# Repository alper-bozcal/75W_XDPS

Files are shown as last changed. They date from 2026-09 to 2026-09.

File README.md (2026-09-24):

# DBC2-Battery-Charger

  Main repository for the DEIF Battery Charger - 2 products.

## Dosyalama Sistemi

`Develop` branchinde kodun çalışma garantisi yoktur fakat en son kod bulunabilir. `Main` branch' de versiyon atlatıldığında stabil kod bulunabilir.

Yazılım `Firmware` klasöründe tutulmaktadır. `Common/` tüm ürünler için ortak fonksiyonları içermektedir. Bunun yanında yer alan klasörler ise proje ismine göre ayrılmıştır.

`ENKO` ve `Documents` klasörleri geliştirme sırasında oluşturulan dökümanları tutmaktadır. Bunları bazıları müşteri ile paylaşılmıştır.

`Hardware/` donanım şema ve PCB dosyalarını içermektedir.

`Simulations` ve `Tests` klasörleri donanım için gerekli çalışmalarda oluşturulan dosyaları içermektedir. Test sonuçları `Tests/` içerisinde bulunabilir.

## Algoritma

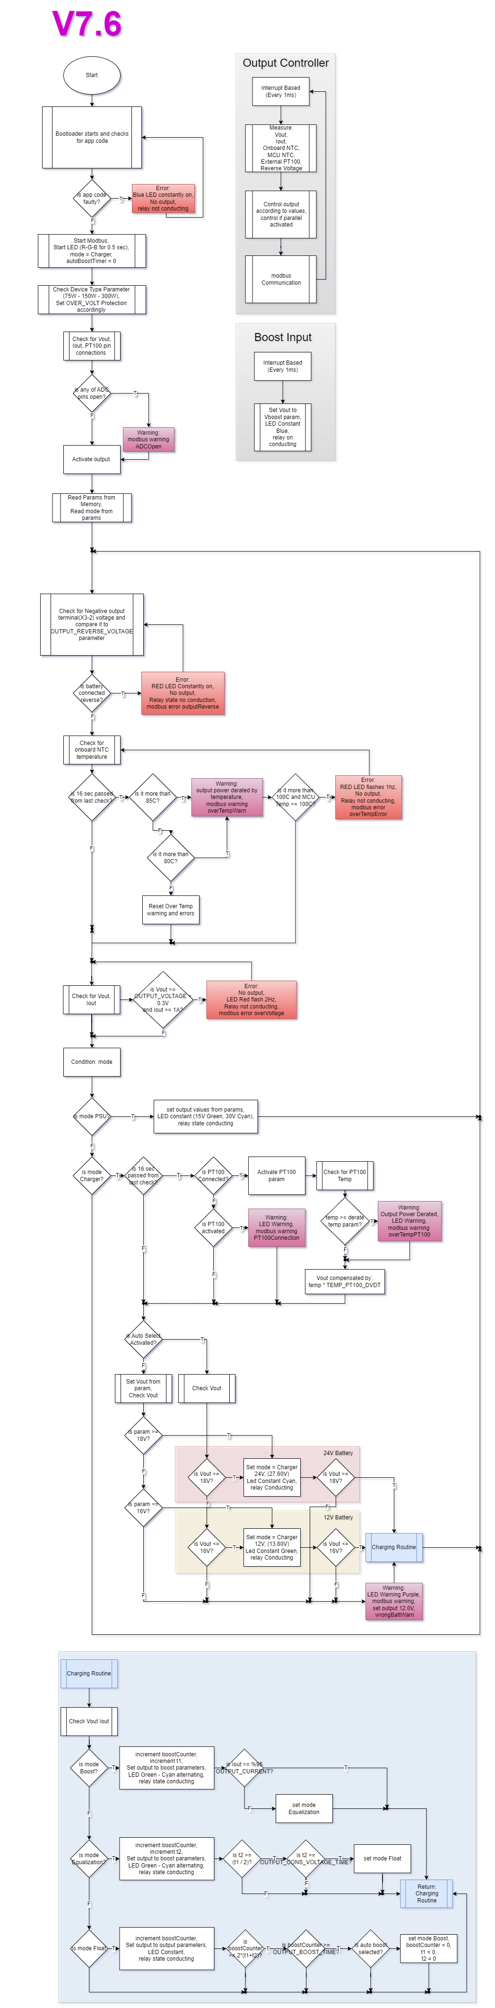
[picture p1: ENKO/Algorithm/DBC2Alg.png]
DBC2 Algorithm:


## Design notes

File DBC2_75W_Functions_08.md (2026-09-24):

# DBC2 75W Functions

|  |  |  | min-max | Unit | Default |
| --- | --- | --- | --- | --- | --- |
| Power  Supply | V_ps_set | Power Supply output voltage | 10.0-15.0 | VDC | 12 |
| Power  Supply | I_ps_limit | Power Supply current limit | 5.0 | ADC | 5 |
| Charge | I_bulk_max | Maximum current during Bulk (I) stage | 0.5-5.0 | ADC | 12 |
| Charge | V_abs | Absorption (U) voltage | 12.0-15.0 | VDC | 13.8 |
| Charge | T_bulk_max | Maximum duration for Bulk stage | 0-24 | Hour | 6 |
| Charge | T_abs | Absorption duration | 0-240 | min. | 120 |
| Charge | I_tail_threshold | Current threshold for transition from Absorption to Float | 0.1-0.2 | ADC | 1 |
| Charge | V_float | Float voltage | 11.0-14.5 | VDC | 13 |
| Charge | Ifloat_to_abs | Current threshold to switch from Float to Absorption (must be > I_tail_threshold) | 0.1-5.0 | ADC | 1.5 |
| Boost | Boost_En | Boost mode enable | 0-1 | - | 1 |
| Boost | Boost_Source | Boost source selection | Auto-Man-Both | - | Both |
| Boost | Boost Edge Selection | External Boost input rising/falling edge selection | Rising / Falling | - | Falling |
| Boost | V_boost | Boost voltage | 12.0-15.0 | VDC | 14.8 |
| Boost | I_boost_max | Maximum Boost current | 0.5-5.0 | ADC | 3 |
| Boost | T_boost_dur | Boost duration | 1-120 | min. | 60 |
| Boost | T_boost_per | Boost period | 1-99 | hour | 1440 |
| Pt100 | Pt100_Act | Pt100 temperature sensor active/passive | 0-1 | - | 0 |
| Pt100 | Pt100 dV/dT | Temperature compensation coefficient | -40 to +40 | mv/ºC | 0 |
| Pt100 | Pt100_temp_comp_minC | Minimum temperature for compensation | -10 to 10 | ºC | 0 |
| Pt100 | Pt100_temp_comp_maxC | Maximum temperature for compensation | 35 to 50 | ºC | 50 |
| Pt100 | Pt100_low_warning_temp | Battery low temperature warning level | -10 to 10 | ºC | 5 |
| Pt100 | Pt100_low_alarm_temp | Battery low temperature alarm level | -10 to 10 | ºC | 0 |
| Pt100 | Pt100_high_warning_temp | Battery high temperature warning level | 25 to 60 | ºC | 35 |
| Pt100 | Pt100_high_alarm_temp | Battery high temperature alarm level | 25 to 60 | ºC | 40 |
| Pt100 | Pt100_high_trip_temp | Battery high temperature trip level (output cut-off) | 25 to 60 | ºC | 45 |
| Cable Compensation | CableVoltage droop Compensation | Compensation coefficient for voltage drop across cable | 0 to 100 | mv/A | 0 |
| Paralel Working | Paralel_Working | Parallel working enable/disable | 0-1 | - | 0 |
| Paralel Working | Voltage Droop | Voltage droop for load sharing in parallel operation | 0 to -100 | mV/A | 0 |

| Calibration (ENKO Leevel) | Iout_offset |  |  |  |  |
| --- | --- | --- | --- | --- | --- |
| Calibration (ENKO Leevel) | Iout_gain |  |  |  |  |
| Calibration (ENKO Leevel) | Vout_offset |  |  |  |  |
| Calibration (ENKO Leevel) | Vout_gain |  |  |  |  |
| Calibration (ENKO Leevel) | Vbat_offset |  |  |  |  |
| Calibration (ENKO Leevel) | Vbat_gain |  |  |  |  |
| Calibration (ENKO Leevel) | Pt100_offset |  |  |  |  |
| Calibration (ENKO Leevel) | Pt100_gain |  |  |  |  |
| Calibration (ENKO Leevel) | NTC_offset |  |  |  |  |
| Calibration (ENKO Leevel) | NTC_gain |  |  |  |  |
| Calibration (ENKO Leevel) | Cupper Lines Voltage Droop Compensation |  |  |  |  |

## Detailed Parameter Descriptions

Parameters

Detailed Parameter Descriptions Based on DBC2 75W Functions

V_ps_set

Sets the output voltage of the device when operating in Power Supply mode. Adjustable between 10.0 V and 15.0 V to power external electronic circuits.

I_ps_limit

Defines the maximum current limit in Power Supply mode. If the load exceeds this value, the output current is clamped to this limit to prevent overload.

I_bulk_max

Maximum current supplied during the Bulk (I) charging stage. The device maintains constant current until the battery voltage reaches the absorption setpoint or the bulk time limit expires.

V_abs

Voltage setpoint for the Absorption (U) stage. The device maintains this voltage while the current gradually decreases as the battery approaches full charge.

T_bulk_max

Maximum duration for the Bulk stage. If the battery does not reach the absorption voltage within this time, the device transitions to the next stage.

T_abs

Duration of the Absorption stage. The device maintains the absorption voltage for this period unless the current drops below the tail threshold earlier.

I_tail_threshold

Current threshold used to determine the transition from Absorption to Float stage. When the charging current falls below this value, the device switches to Float mode.

V_float

Voltage level maintained during the Float stage to keep the battery fully charged without overcharging. Provides a trickle charge to compensate for self-discharge.

Ifloat_to_abs

Current threshold to trigger a transition from Float back to Absorption mode. Must be higher than the tail threshold to ensure proper recharge behavior.

Boost_En

Enables or disables the Boost charging mode. Boost mode applies a higher voltage to equalize battery cells and accelerate charging.

Boost_Source

Selects the source that initiates Boost mode. Can be time-based automatic activation, external input trigger, or both.

Boost Edge Selection

Defines the edge type (rising or falling) for external Boost input signal triggering. Determines how the Boost mode is activated externally.

V_boost

Voltage applied during Boost mode. This higher voltage helps equalize battery cells and ensure uniform charge levels.

I_boost_max

Maximum current allowed during Boost mode. Protects the system from excessive current during high-voltage charging.

T_boost_dur

Duration of the Boost mode operation. After this time, the device returns to Float voltage level.

T_boost_per

Periodicity of Boost mode activation. Defines how often Boost mode is triggered automatically.

Pt100_Act

Activates or deactivates the external Pt100 temperature sensor. Used for temperature-based voltage compensation.

Pt100 dV/dT

Temperature compensation coefficient in mV/°C. Determines how output voltage adjusts based on battery temperature.

Pt100_temp_comp_minC

Minimum temperature at which compensation is applied. Below this value, voltage compensation is not performed.

Pt100_temp_comp_maxC

Maximum temperature at which compensation is applied. Above this value, voltage compensation is not performed.

Pt100_low_warning_temp

Battery low temperature warning threshold. Triggers a warning when battery temperature drops below this level.

Pt100_low_alarm_temp

Battery low temperature alarm threshold. Triggers an alarm and may affect output behavior.

Pt100_high_warning_temp

Battery high temperature warning threshold. Triggers a warning when battery temperature exceeds this level.

Pt100_high_alarm_temp

Battery high temperature alarm threshold. Triggers an alarm and may affect output behavior.

Pt100_high_trip_temp

Battery high temperature trip threshold. If exceeded, output is cut off to protect the system.

CableVoltage droop Compensation

Compensation coefficient for voltage drop across output cables. Helps maintain accurate voltage at the battery terminals.

Paralel_Working

Enables or disables parallel operation mode. Allows multiple devices to share load current.

Voltage Droop

Voltage droop setting used in parallel operation for load sharing. Adjusts output voltage based on load to balance current among devices.

Boost (Equalization) 
Boost mode utilizes a higher charging voltage to rapidly recharge batteries and ensure that all cells within a battery string are equalized to the same charge level.

Boost mode can be initiated either automatically based on predefined timing parameters or manually by connecting the Boost terminal to the negative terminal of the battery. When the Boost function is activated externally, the automatic Boost timer is reset.

The external Boost input operates with edge triggering and can be configured to respond to either a rising or falling edge. Upon receiving an external Boost signal, the device output is elevated to the Boost voltage for the specified duration, after which it returns to the Float voltage level. Following this phase, the device automatically decides whether to switch to Float or Absorption mode based on the load conditions.

Remote Temperature Compensation Functionality (dV/dT) / Alarm

The charger supports remote temperature compensation based on the battery temperature when an optional external sensor is placed near the batteries and connected to the remote temperature sensor terminal block on the main circuit board. This feature is especially critical in applications where the charger and batteries are located in different ambient environments.

A Pt-100 sensor can be used as the external temperature sensor. If the temperature reading from the external sensor falls below -45°C or rises above +180°C, and remains outside these limits for a defined duration, a sensor fault is triggered. In this case, the alarm output is activated, and the output voltage is set to 12V.

The temperature compensation function is only active in Charger Mode. It is disabled in Power Supply Mode.

The temperature compensation value is expressed in mV/°C and can be either positive or negative:

A positive value increases the output voltage as temperature rises.

A negative value decreases the output voltage as temperature rises.

On the Power Cloud main screen, the Set Output value (for both current and voltage) reflects the user-defined setpoint. However, if temperature compensation is active, the effective output value shown will be adjusted accordingly.
For example, if the user sets the output voltage to 13.8V, and the external sensor reads 45°C with a compensation value of -10mV/°C, the adjustment will be:

Thus, the effective output voltage displayed will be 13.6V.

To protect against excessively high or low output voltages, the compensation effect is clamped at 0°C and +50°C. Beyond these temperatures, the output voltage is held constant at the values corresponding to these limits.

In a future update, the output voltage variation based on ambient temperature and set parameters will also be graphically displayed on the screen.

The temperature compensation value can be configured within the range of -40mV/°C to +40mV/°C.

If the external temperature sensor reading exceeds the Temperature Sensor Alarm Threshold, the output voltage is disabled, the LED turns red, and the alarm output is activated.

Internal Temperature Sensor / Alarm

The charger includes two internal temperature protection mechanisms and a power derating function, both utilizing onboard temperature sensors:

Sensor-1: Located on the secondary side, this sensor is also monitored by the MCU. It is used to implement power derating functions and to prevent device failure due to overheating.

Sensor-2: An NTC-type sensor also located on the secondary side, but not monitored by the MCU. It is directly connected to the primary SMPS IC and serves as a fail-safe. If Sensor-1 becomes non-functional or disconnected, Sensor-2 will shut down the output to protect the system. Once the temperature returns within safe limits, the output is automatically re-enabled.

Since only Sensor-1 is evaluated by the software, the following functions apply specifically to it:

The Sensor-1 temperature value can be monitored on the Power Cloud display and is also available in the log screen for recording.

If the Sensor-1 temperature is below 60°C, no action is taken.

Starting from 60°C, the output power is gradually limited.

At 70°C, the output power is reduced to 25% of the rated value.

If the temperature exceeds 70°C, the output is shut down, the red LED is turned on, and the alarm relay is activated.

Leds

Charger Mode:

Bulk : Flsahing Green ( 100msec ON, 100msec OFF)

Absorption: Flashing Green ( 400msec ON, 400msec OFF)

Float mode: Steady GREEN

Boost mode: Flashing BLUE (50msec ON, 500msec OFF)

Power Supply

Çıkış gerilimi set edilen değerde: Steady GREEN

Failure: Flashing RED

Over temperature (1 times 100msec ON, 500msec OFF)

Lower temperature (2 times 100msec ON, 500msec OFF)

Output Over Voltage (3 times 100msec ON, 500msec OFF)

Output Low Voltage (4 times 100msec ON, 500msec OFF)

Reverse Battery Connection (5 times 100msec ON, 500msec OFF)

Power Derate (6 times 100msec ON, 500msec OFF)

Battery Disconnected (only charger mode) (7 times 100msec ON, 500msec OFF)

High Ouput Current (only power supply mode) (8 times 100msec ON, 500msec OFF)

USB Communication:

Boot Mode (Firmware Update):  Steady Blue

Alarm Relay and Fault Monitoring Functions

The charger includes a SPST N/O (Single Pole Single Throw Normally Open) contact relay, which is energized during normal operation. This means the contact remains closed under normal conditions.

AC/DC Failure Condition

The alarm relay is de-energized (contact opens) under the following conditions:

Loss of AC input power

Loss of DC output from the charger

⚠️ Note: This alarm condition cannot be indicated via LED.

User-Configurable Alarm Functions

The following alarm functions can be enabled or disabled via the user interface. Each alarm can be configured as either:

Warning: Only the alarm relay is activated.

Trip: The alarm relay is activated and the output is shut down.

All alarm functions support a configurable delay time, with a default of 3 seconds. The delay can be set between 0 and 60 seconds.

Alarm Conditions

Low DC Output Voltage
Relay de-energized if:
VDC<88%×VSTATEV_{DC} < 88\% \times V_{STATE}VDC<88%×VSTATE
Alarm resets if:
VDC>92%×VSTATEV_{DC} > 92\% \times V_{STATE}VDC>92%×VSTATE

High DC Output Voltage
Relay de-energized if: VDC>107%×VSTATEVDC

Alarm resets if: VDC<102%×VSTATEVDC 

Overvoltage Protection
Relay de-energized if:
VDC>15.1 VDCV  (This is a fixed internal threshold.)

Battery Disconnect
Relay de-energized if the battery is disconnected.

Alarm delay: 10 to 20 minutes

This function is only active in Charger Mode

High Battery Temperature
Software-configurable threshold.
Relay de-energized if the high temperature limit is exceeded.

Low Battery Temperature
Software-configurable threshold.
Relay de-energized if the low temperature limit is exceeded.

Reverse Polarity Protection
(Relay de-energized if reverse battery connection is detected.)

Connection of Deeply Discharged Battery
(Relay de-energized if a battery with excessively low voltage is connected.)

Ters Bağlantı Koruması

Düşük gerilime Sahip Akü Bağlantısı

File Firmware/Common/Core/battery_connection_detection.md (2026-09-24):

# Battery Connection Detection Algorithm

## Overview

The battery connection detection algorithm is designed to determine whether a battery is actually connected to the charger output terminals. This is critical for proper charger operation, as the charging algorithm behaves differently when a battery is present versus when the output is open or connected to a purely resistive load.

## Purpose

- **Prevent false charging cycles**: Avoid running charging cycles when no battery is present
- **Improve safety**: Detect disconnection events that could indicate wiring issues
- **Optimize operation**: Allow the charger to enter appropriate operating modes based on battery presence

## Algorithm Overview

The detection algorithm operates on the principle that a battery behaves differently from a resistive load when voltage is applied:

1. **Resistive Load**: When voltage increases, current increases proportionally (Ohm's law: I = V/R)
2. **Battery Load**: A battery acts as a voltage source with low internal resistance, so applying voltage causes a disproportionate current increase

## Implementation Files

- **Header File**: `Controller.h` - Contains type definitions, constants, and function prototypes
- **Implementation File**: `Controller.c` - Contains the detection algorithm implementation
- **Documentation**: `battery_connection_detection.md` - This file

## Configuration Parameters

All configuration parameters are defined in `Controller.h` using `#define` directives:

| Parameter | Value | Unit | Description |
|---|---|---|---|
| `BAT_CONN_MIN_CURRENT_TRESHOLD` | 15 | 10mA | Minimum current threshold for detection (150mA) |
| `BAT_CONN_CHECK_DURATION_MS` | 30 | ms | Duration to monitor voltage after applying test voltage |
| `BAT_CONN_VOLTAGE_CONDITION_MV` | 10 | 10mV | Voltage condition threshold (100mV) |
| `BAT_CONN_VOLTAGE_THRESHOLD_MV` | 30 | 10mV | Voltage threshold above test voltage target (300mV) |
| `BAT_CONN_TEST_VOLTAGE_MV` | 1180 | mV | Test voltage to apply during detection (11.8V) |
| `BAT_CONN_CURRENT_THRESHOLD_PERCENT` | 95 | % | Percentage of effective current - detection only runs when below this |
| `BAT_CONN_CHECK_INTERVAL_MS` | 30000 | ms | Interval between detection checks (5 minutes with 10ms timer) |
| `BAT_CONN_MAX_FAILED_CHECKS` | 10 | count | Maximum consecutive failed checks before reporting battery disconnected |
| `BAT_CONN_CHECK_WINDOW_MS` | 360000 | ms | Time window for counting failed checks (1 hour with 10ms timer) |
| `BAT_CONN_RATIO_TOLERANCE_PERCENT` | 20 | % | Tolerance for comparing voltage and current change ratios |

## Algorithm Phases

### Phase 1: Preconditions Check

The detection algorithm only runs when specific conditions are met:

```
Condition: Measured Current < (Effective Current × 95%)
```

**Rationale**: Detection is only performed when current draw is low, ensuring the test voltage application won't cause issues.

### Phase 2: Baseline Measurement

```
1. Store current voltage (Vout_initial)
2. Store current current (Iout_initial)
```

These baseline values are used to calculate change ratios after applying the test voltage.

### Phase 3: Apply Test Voltage

```
1. Set charger output to 11.8V (BAT_CONN_TEST_VOLTAGE_MV)
2. Start 30ms monitoring timer (BAT_CONN_CHECK_DURATION_MS)
```

### Phase 4: Monitor Response

```
Wait for 30ms while measuring:
- Output voltage
- Output current
```

### Phase 5: Evaluation

After the monitoring period, the algorithm evaluates the results using two tests:

#### Test 1: Voltage Reached Target

```
IF Vout_measured < (BAT_CONN_TEST_VOLTAGE_MV + BAT_CONN_VOLTAGE_THRESHOLD_MV):
    RESULT = BATTERY NOT CONNECTED
```

**Rationale**: If the output voltage fails to reach approximately 11.8V within 30ms, it indicates there's no voltage source (battery) at the output.

#### Test 2: Change Ratio Comparison

If voltage reached the target, calculate and compare change ratios:

```
voltage_change = Vout_measured - Vout_initial
current_change = Iout_measured - Iout_initial

voltage_ratio = (voltage_change × 100) / Vout_initial
current_ratio = (current_change × 100) / Iout_initial

ratio_difference = |current_ratio - voltage_ratio|
```

**Decision Logic**:

```
IF ratio_difference <= BAT_CONN_RATIO_TOLERANCE_PERCENT:
    RESULT = BATTERY NOT CONNECTED (Resistive load)
ELSE IF current_ratio > (voltage_ratio + BAT_CONN_RATIO_TOLERANCE_PERCENT):
    RESULT = BATTERY CONNECTED
ELSE:
    RESULT = INDETERMINATE
```

**Rationale**:
- **Resistive Load**: Voltage and current change proportionally (similar ratios)
- **Battery Load**: Current increases more than voltage (battery acts as current sink)

## State Machine

The algorithm implements a state machine with the following states:

### BAT_CONN_IDLE
- **Description**: Waiting for next check interval
- **Entry**: After initialization or after completing a detection cycle
- **Exit**: When interval timer completes AND preconditions are met
- **Next State**: `BAT_CONN_STORE_VALUES`

### BAT_CONN_STORE_VALUES
- **Description**: Storing baseline voltage and current measurements
- **Actions**: 
  - Store `measured->Vout` → `ctx->storedVoltage`
  - Store `measured->Iout` → `ctx->storedCurrent`
- **Next State**: `BAT_CONN_APPLY_VOLTAGE`

### BAT_CONN_APPLY_VOLTAGE
- **Description**: Applying test voltage to output
- **Actions**:
  - Set `controller.referenceVoltage = BAT_CONN_TEST_VOLTAGE_MV`
  - Start monitoring timer
- **Next State**: `BAT_CONN_MONITORING`

### BAT_CONN_MONITORING
- **Description**: Monitoring voltage and current response
- **Duration**: 30ms (BAT_CONN_CHECK_DURATION_MS)
- **Exit**: When monitoring timer completes
- **Actions**: Store measured voltage and current
- **Next State**: `BAT_CONN_EVALUATE`

### BAT_CONN_EVALUATE
- **Description**: Evaluating results and updating status
- **Actions**:
  - Call `_evaluateBatteryConnection()`
  - Update failed check counter if battery not detected
  - Reset counter if battery detected
  - Update `batteryNotConnected` flag if threshold exceeded
- **Next State**: `BAT_CONN_IDLE`

## Failed Check Tracking

The algorithm tracks consecutive "battery not connected" detections:

### Counter Management

```
IF result == NOT_CONNECTED:
    failedCheckCount++
    IF failedCheckCount == 1:
        Record firstFailTimestamp
    
    IF (currentTime - firstFailTimestamp) > 1 hour:
        Reset failedCheckCount = 1
        Update firstFailTimestamp = currentTime
    
    IF failedCheckCount >= 10:
        Set batteryNotConnected flag = 1

ELSE IF result == CONNECTED:
    Reset failedCheckCount = 0
    Reset firstFailTimestamp = 0
    Clear batteryNotConnected flag = 0
```

### Rationale

- **10 consecutive failures within 1 hour**: Ensures the battery is consistently not detected before reporting
- **1-hour window**: Prevents old failures from affecting current status
- **Reset on success**: A single successful detection clears all previous failures

## Integration Guide

### ✅ Already Integrated in DBC2 Firmware

The battery connection detection has been **fully integrated** into the DBC2 firmware in `Interfaces.c`. The integration includes:

#### 1. Global Variables Declaration (Interfaces.c)
```c
protection_t protectionBatteryDisconnect;
batConnDetection_t batteryConnectionDetection = {0};
int16_t batteryConnectionStatus = 0; // 0 = connected, 1 = disconnected
```

#### 2. Protection Initialization (_initSystem function)
```c
// CRITICAL BUG - NEEDS FIXING:
initProtection(&protectionBatteryDisconnect, &batteryConnectionStatus, 0, 1000, MODE_OVER);
// Should be:
// initProtection(&protectionBatteryDisconnect, &batteryConnectionStatus, 1, 1000, MODE_OVER);

// Initialize Battery Connection Detection
initBatteryConnectionDetection(&batteryConnectionDetection);
enableBatteryConnectionDetection(&batteryConnectionDetection, 1);
```

#### 3. Periodic Update (Callback1ms function)
```c
// Update battery connection detection every 10ms
updateBatteryConnectionDetection(&batteryConnectionDetection, &measuredValues);
// Update battery connection status for protection system
batteryConnectionStatus = isBatteryDisconnected(&batteryConnectionDetection);
updateProtection(&protectionBatteryDisconnect);
```

#### 4. Error Flag Handling (_checkProtections function)
```c
// Check for battery disconnect protection
if(protectionBatteryDisconnect.triggered){
    //RED LED Flashes 7Hz
    controller.flagERR = controller.flagERR | 0x80; // 8th Error bit is BatteryDisconnect
}else{
    controller.flagERR = controller.flagERR & ~(0x80);
}
```

### How to Check Battery Status

#### Option 1: Check Protection Status
```c
if(protectionBatteryDisconnect.triggered){
    // Battery disconnection protection is active
    // Relay is in RELAY_ERROR state
}
```

#### Option 2: Direct Function Call
```c
if(isBatteryDisconnected(&batteryConnectionDetection)){
    // Battery is not connected (but protection may not be triggered yet)
}
```

#### Option 3: Check Error Flag
```c
if(controller.flagERR & 0x80){
    // Battery disconnect error flag is set (Bit 7)
}
```

#### Option 4: Via Modbus
Read the `flagERR` register via Modbus and check bit 7 (0x80).

### Protection Behavior

When `protectionBatteryDisconnect.triggered` becomes active:
1. **Error Flag**: `controller.flagERR` bit 7 (0x80) is set
2. **Relay State**: Relay goes to `RELAY_ERROR` state (output disabled)
3. **LED Indication**: Red LED blinks at 7Hz
4. **Modbus**: Error flag visible via Modbus ERR_FLAG register

### Reset Detection (If Needed)
```c
// Reset the detection algorithm
resetBatteryConnectionDetection(&batteryConnectionDetection);

// Reset the protection
resetProtection(&protectionBatteryDisconnect);
```

## Function Reference

```c
### initBatteryConnectionDetection()
```

**Description**: Initializes the battery connection detection context.

**Parameters**:
- `ctx`: Pointer to battery connection detection context structure

**Returns**: None

**Notes**: Must be called before using the detection system. Sets all fields to initial values and starts the interval timer. Called automatically during system initialization.

---

### updateBatteryConnectionDetection()

```c
BAT_CONN_RESULT updateBatteryConnectionDetection(batConnDetection_t *ctx, MEASURED_t *measured);
```

**Description**: Main update function for battery connection detection. Must be called periodically (every 10ms).

**Parameters**:
- `ctx`: Pointer to battery connection detection context structure
- `measured`: Pointer to current measurements structure

**Returns**: 
- `BAT_CONN_RESULT_CONNECTED`: Battery is connected
- `BAT_CONN_RESULT_NOT_CONNECTED`: Battery is not connected
- `BAT_CONN_RESULT_INDETERMINATE`: Status cannot be determined

**Notes**: 
- This function implements the state machine
- Should be called from a 10ms timer interrupt (DEF_CONTROL_TIMER)
- Returns the overall status based on accumulated detections

---

### isBatteryDisconnected()

```c
uint8_t isBatteryDisconnected(const batConnDetection_t *ctx);
```

**Description**: Returns the current battery connection status.

**Parameters**:
- `ctx`: Pointer to battery connection detection context structure

**Returns**: 
- `1`: Battery is disconnected (10+ consecutive failures detected)
- `0`: Battery is connected

**Notes**: This is the primary function to query battery status in application code.

---

### resetBatteryConnectionDetection()

```c
void resetBatteryConnectionDetection(batConnDetection_t *ctx);
```

**Description**: Resets the detection state and clears all counters.

**Parameters**:
- `ctx`: Pointer to battery connection detection context structure

**Returns**: None

**Notes**: 
- Clears failed check counter
- Clears batteryNotConnected flag
- Restarts interval timer
- Use when you want to force a fresh detection cycle

---

### enableBatteryConnectionDetection()

```c
void enableBatteryConnectionDetection(batConnDetection_t *ctx, uint8_t enable);
```

**Description**: Enables or disables the battery connection detection system.

**Parameters**:
- `ctx`: Pointer to battery connection detection context structure
- `enable`: `1` to enable, `0` to disable

**Returns**: None

**Notes**: 
- When disabled, `updateBatteryConnectionDetection()` always returns `BAT_CONN_RESULT_CONNECTED`
- Enabling the system automatically resets the detection state

## Example Usage Scenario

### Scenario: Battery Disconnect Protection in DBC2

The battery connection detection is **automatically active** in the DBC2 firmware. The protection system handles everything:

```c
// ✅ ALREADY IMPLEMENTED - No user code needed!

// System automatically:
// 1. Detects battery connection every 6 minutes (when I < 90% of Ieff)
// 2. After 10 consecutive failures within 1 hour -> batteryConnectionStatus = 1
// 3. Protection triggers after 1 second delay
// 4. Error flag bit 6 (0x40) is set in flagERR
// 5. Relay goes to RELAY_ERROR state
// 6. LED blinks red at 7Hz

// To check status in your code:
if(protectionBatteryDisconnect.triggered){
    // Battery disconnect protection is active
    // System has already disabled output via relay
}
```

### Manual Control Example (If Needed)

If you want to temporarily disable detection:

```c
// Disable detection
enableBatteryConnectionDetection(&batteryConnectionDetection, 0);

// ... do something ...

// Re-enable detection
enableBatteryConnectionDetection(&batteryConnectionDetection, 1);
```

### Custom Action on Battery Disconnect

```c
void CustomBatteryCheckHandler(void) {
    static uint8_t lastStatus = 0;
    uint8_t currentStatus = protectionBatteryDisconnect.triggered;
    
    // Detect state change
    if(currentStatus && !lastStatus) {
        // Battery just detected as disconnected
        // Protection is now active
        
        // Custom actions (optional - system already handles safety)
        // e.g., send CAN message, log to EEPROM, etc.
    }
    
    lastStatus = currentStatus;
}
```

## Assumptions and Limitations

### Assumptions

1. **Voltage Application**: The charger can safely apply 11.8V test voltage without causing damage
2. **Measurement Accuracy**: ADC measurements are sufficiently accurate to detect ratio differences
3. **Timing Precision**: The 10ms timer ISR is called with reasonable precision
4. **Single Battery**: Algorithm designed for single battery connection, not multiple batteries in parallel

### Limitations

1. **Test Voltage Fixed**: Currently hardcoded to 11.8V - may not be optimal for all battery types
2. **No Auto-Scaling**: Ratios are compared with fixed tolerance, may need adjustment for different battery chemistries
3. **Resistive Load Similarity**: A resistive load with very low resistance might be misidentified as a battery
4. **Temperature Effects**: Battery impedance changes with temperature, which could affect detection accuracy
5. **State of Charge**: Very full or empty batteries might behave differently
6. **Age Effects**: Old batteries with high internal resistance might be harder to detect

## Tuning Guidelines

If the detection is not working optimally, consider adjusting these parameters:

### False Negatives (Battery Present but Not Detected)

**Symptoms**: Real battery reported as not connected

**Possible Fixes**:
- Increase `BAT_CONN_RATIO_TOLERANCE_PERCENT` (allows more variation)
- Increase `BAT_CONN_CHECK_DURATION_MS` (more time for battery response)
- Adjust `BAT_CONN_TEST_VOLTAGE_MV` to a more suitable value

### False Positives (No Battery but Detected as Connected)

**Symptoms**: Open circuit or resistive load reported as battery

**Possible Fixes**:
- Decrease `BAT_CONN_RATIO_TOLERANCE_PERCENT` (requires clearer difference)
- Decrease `BAT_CONN_VOLTAGE_THRESHOLD_MV` (stricter voltage requirement)
- Increase `BAT_CONN_MAX_FAILED_CHECKS` (require more confirmations)

### Too Frequent Checks

**Symptoms**: System spends too much time in detection mode

**Possible Fixes**:
- Increase `BAT_CONN_CHECK_INTERVAL_MS` (check less frequently)
- Adjust `BAT_CONN_CURRENT_THRESHOLD_PERCENT` (run detection less often)

## Safety Considerations

1. **Voltage Application**: Ensure the test voltage (12V) is safe for all expected load types
2. **Current Limiting**: Ensure current limiting is active during detection to prevent damage
3. **Timeout Protection**: The state machine includes timeout protection via timers
4. **Null Pointer Checks**: All functions validate input pointers before use
5. **Integer Overflow**: All arithmetic uses appropriate data types to prevent overflow

## Testing Recommendations

### Test Cases

1. **Normal Battery Connection**
   - Expected: Detection reports battery connected
   - Verify: `isBatteryDisconnected()` returns `0`

2. **Open Circuit**
   - Expected: After 10 checks, reports battery not connected
   - Verify: `isBatteryDisconnected()` returns `1`

3. **Resistive Load (e.g., 10Ω)**
   - Expected: Reports battery not connected (ratios similar)
   - Verify: `isBatteryDisconnected()` returns `1`

4. **Battery Removal During Operation**
   - Expected: Within 1 hour, after 10 detection cycles, reports not connected
   - Verify: Status changes from connected to not connected

5. **Battery Reconnection**
   - Expected: Immediately (on next check) reports battery connected
   - Verify: Failed check counter resets, status changes to connected

6. **Disabled Detection**
   - Expected: Always reports battery connected
   - Verify: `updateBatteryConnectionDetection()` returns `CONNECTED` status

## Revision History

| Version | Date | Author | Changes |
|---|---|---|---|
| 1.1 | 2025-10-22 | System | **CRITICAL FIXES**: Updated documentation to match actual implementation:<br/>- Fixed error bit mapping (bit 7/0x80 for battery disconnect, not bit 6/0x40)<br/>- Corrected configuration values to match Controller.h<br/>- Updated timer frequency from 1ms to 10ms<br/>- Fixed protection threshold documentation<br/>- Updated test voltage from 12V to 11.8V<br/>- Corrected timing calculations for all intervals |
| 1.0 | 2025-10-16 | System | Initial implementation with full state machine and documentation |

## References

- **Controller.h**: Type definitions and function prototypes
- **Controller.c**: Implementation of detection algorithm
- **DBC2 Firmware Documentation**: Overall system architecture
- **Battery Charging Standards**: IEC 61851, SAE J1772 (for general battery behavior understanding)

---

**Note**: This algorithm is designed for the DBC2 battery charger series. Adaptations may be needed for different hardware configurations or battery types.

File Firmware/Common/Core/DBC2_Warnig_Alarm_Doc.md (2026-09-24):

# DBC2 Battery Charger – Error, Alarm & Warning Flags Documentation

This document describes the runtime diagnostic bitmasks `controller.flagERR` (errors/alarms) and `controller.flagWARN` (warnings) used in the DBC2 Battery Charger firmware.

> NOTE: File name typo kept for backward compatibility (`DBC2_Warnig_Alarm_Doc.md`). Prefer referencing it as “Warning & Alarm Documentation”.

## Overview

- **flagERR (ERR_FLAG)**: Critical, blocking faults OR alarms requiring protective action. Type: `int16_t` (bitmask)
- **flagWARN (WARN_FLAG)**: Non‑blocking informational conditions. Type: `int16_t` (bitmask)
- Multiple bits may be active simultaneously; firmware clears bits automatically when conditions disappear.
- Recent refactor (Oct 2025) moved PT100 connection failure from warning to error (bit 6 / 0x40) and deprecated ADC open / over‑current warnings from public documentation.

## Error / Alarm Bits (`controller.flagERR`)

| Bit | Hex | Symbol | Condition Source | Trigger Summary | Action |
|-----|-----|---|---|---|---|
| 0 | 0x01 | OutputReverse | `protectionOutputReverse` | Battery polarity reversed | Relay -> `RELAY_ERROR`, output disabled, LED pattern 1 |
| 1 | 0x02 | OverTempError | `protectionOverTemp` (NTC/internal) | Internal temperature over limit | Relay error, LED pattern 5 (see LED section) |
| 2 | 0x04 | OverVolt | `protectionOverVolt` | Output voltage > (boostVoltage + 100mV) | Relay error, LED pattern 2 |
| 3 | 0x08 | PT100UnderTemp | `protectionUnderTempPT100` | PT100 < `pt100LowAlarmTemp` | Relay error, LED pattern 8 |
| 4 | 0x10 | PT100TripTemp | `protectionTripTemp` | PT100 ≥ `pt100HighTripTemp` (Trip) | Output cut off (`flagCutOff = NOT_CONDUCTING`), LED pattern 6 |
| 5 | 0x20 | PT100OverTemp | `protectionOverTempPT100` | PT100 ≥ `Pt100AlarmTemp` (Alarm) | Relay error, LED pattern 7 |
| 6 | 0x40 | PT100Broken | `protectionPT100Broken` | PT100 physically disconnected / broken | Relay error, LED pattern 4 |
| 7 | 0x80 | BatteryDisconnect | `protectionBatteryDisconnect` | 10 failed connection detections within 1h | Relay error, LED pattern 3 |

Notes:
1. Bit numbering follows least‑significant bit = 0.
2. “LED pattern” refers to `controller.LEDBlink` values (NOT fixed Hz frequencies; pattern sequencing logic described later).
3. PT100 “Trip” (bit 4) is a hard shutdown; PT100 “OverTemp” (bit 5) is pre‑trip alarm; PT100 “Broken” (bit 6) indicates sensor integrity failure.

## Warning Bits (`controller.flagWARN`)

| Bit | Hex | Symbol | Implementation | Trigger Condition | Source File | Comments |
|-----|-----|---|---|---|---|---|
| 0 | 0x01 | ADCOpen | **Disabled (commented)** | `isADCOpen(measuredValues) == STAT_TRUE` | Interfaces.c:330-332 | Logic completely commented out |
| 1 | 0x02 | OverTempWarn | **Active** | Temperature > `POWER_DERATE_START_TEMP` during power derating | Controller.c:494,498,516 | Thermal derating warning system |
| 2 | 0x04 | PT100Connection | **Active** | `controller.flagPt100 == ENABLED` && `Tpt.flagOpen == ENABLED` | Controller.c:36,39,46 | PT100 enabled but sensor not connected |
| 3 | 0x08 | Reserved | **Unused** | – | – | Not implemented |
| 4 | 0x10 | PT100WarningTemp | **Active** | `controller.flagPt100` && `measuredValues.CPT100 > controller.Pt100WarningTemp` | Interfaces.c:297,300 | PT100 over temperature warning |
| 5 | 0x20 | WrongBattWarn | **Active** | Battery voltage mismatch in auto-detect or manual mode | Controller.c:141; Interfaces.c:483 | Wrong battery type detection |
| 6 | 0x40 | PT100UnderTempWarning | **Active** | `controller.flagPt100` && `measuredValues.CPT100 < controller.pt100LowWarningTemp` | Interfaces.c:305,308 | PT100 under temperature warning |
| 7-15 | – | Reserved | **Unused** | – | – | Not implemented |

### Disabled/Commented Warning Bits

| Bit | Hex | Symbol | Status | Location | Reason |
|-----|-----|---|---|---|---|
| 1 | 0x02 | OverCurrent | **Disabled (commented)** | Interfaces.c:266,268 | Over current warning commented out to avoid noise |

Rationale: 
- **ADC Open Detection**: Completely removed to eliminate false positives
- **Over Current Warning**: Disabled in favor of protection-only approach to reduce noise
- **Bit Reuse**: Bit 1 (0x02) repurposed from OverCurrent to OverTempWarn for thermal derating
- **PT100 Separation**: 
  - **Connection Warning** (bit 2): Informational when feature enabled but sensor missing
  - **Broken Sensor Error** (error bit 6): Critical failure requiring protective action
- **Dual Implementation**: WrongBattWarn implemented in both auto-detect and manual mode validation

## Protection Parameters

### Error / Alarm Protection Definitions
- **protectionOverVolt**: Over-voltage protection with threshold at controller.boostVoltage + 100 mV
- **protectionOutputReverse**: Reverse polarity protection (when battery is connected backwards)
- **protectionOverCurrent**: Over-current protection (when maximum current limit is exceeded) - *Note: Currently monitored but does not set warning flags*
- **protectionOverTemp**: Internal temperature protection (for MCU internal temperature)
- **protectionTripTemp**: PT100 high temperature trip protection with threshold at controller.pt100HighTripTemp (default: 450 = 45.0°C)
- **protectionOverTempPT100**: PT100 alarm temperature protection with threshold at controller.Pt100AlarmTemp (default: 1000 = 100.0°C)
- **protectionUnderTempPT100**: PT100 under-temperature protection with threshold at controller.pt100LowAlarmTemp (default: 0 = 0.0°C)
- **protectionBatteryDisconnect**: Battery connection detection protection (1s delay) triggers when `batteryConnectionStatus >= 1` after algorithm concludes disconnection.
- **protectionPT100Broken**: PT100 integrity protection, triggers when `pt100ConnectionStatus` indicates sensor loss (1s delay). Sets error bit 6.

### Warning Temperature Parameters & Derate System
- **Pt100WarningTemp**: PT100 warning temperature (default: 750 = 75.0°C)
- **Pt100AlarmTemp**: PT100 alarm temperature (default: 1000 = 100.0°C)
- **pt100LowWarningTemp**: PT100 low warning temperature (default: 50 = 5.0°C)
- **pt100LowAlarmTemp**: PT100 low alarm temperature (default: 0 = 0.0°C)
- **POWER_DERATE_START_TEMP**: Temperature at which power limiting begins
- **POWER_DERATE_END_TEMP**: Temperature at which power limiting reaches maximum
- Derate system applies power limiting with temperature increase and cuts output at very high temperatures

## Relay State Control

Any active error bit forces the relay into a safe error state (`RELAY_ERROR`). PT100TripTemp additionally sets `flagCutOff = NOT_CONDUCTING` for immediate output shutdown.

## LED Indication Logic

LED behavior is priority‑based (first matching condition in `Interfaces.c`). `controller.LEDBlink` is an integer pattern code, not a direct Hz value.

Priority & Pattern Codes (higher up = higher priority):

| Priority Order | Condition (Protection) | Error Bit | LEDBlink Code |
|---|---|---|---|
| 1 | Reverse Polarity (`protectionOutputReverse`) | 0x01 | 1 |
| 2 | Over Voltage (`protectionOverVolt`) | 0x04 | 2 |
| 3 | Battery Disconnect (`protectionBatteryDisconnect`) | 0x80 | 3 |
| 4 | PT100 Broken (`protectionPT100Broken`) | 0x40 | 4 |
| 5 | Over Temp MCU (`protectionOverTemp`) | 0x02 | 5 |
| 6 | PT100 Trip (`protectionTripTemp`) | 0x10 | 6 |
| 7 | PT100 Over Temp (`protectionOverTempPT100`) | 0x20 | 7 |
| 8 | PT100 Under Temp (`protectionUnderTempPT100`) | 0x08 | 8 |
| 9 | Over Current (`protectionOverCurrent`) | (no active bit / warning disabled) | 9 |

Blink Timing: The firmware toggles LED state with a tick window derived from `LED_DEFAULT_BLINK_TIME` and `(LEDBlink * 2)` offsets. Exact visual frequency depends on timer configuration and may not match legacy Hz documentation.

## Modbus Addresses & Access

- **ERR_FLAG**: Modbus address for error flags
- **WARN_FLAG**: Modbus address for warning flags
- **Access Level**: LEVEL_0 (read-only)
- **Save**: SAVE_DISABLE (not saved to memory)
- Values reflect real-time system status

## Flag Details

### ADC Open Circuit Detection (Deprecated)
- **Implementation**: Completely commented out in `Interfaces.c` lines 330-332
- **Previous Logic**: Would set warning bit 0 (0x01) when `isADCOpen(measuredValues) == STAT_TRUE`
- **Current Status**: Not active; code commented with "//Uyari kaldirildi." (Warning removed)

### Over Temperature Warning System (Power Derating)
- **Active Bit**: 1 (0x02) - `OverTempWarn`
- **Implementation**: `Controller.c` lines 494, 498, 516 in `updateCurrentByDerate()` function
- **Trigger Conditions**:
  - Sets when: `temperature > POWER_DERATE_START_TEMP`
  - Clears when: `temperature <= POWER_DERATE_START_TEMP`
- **Purpose**: Indicates active thermal power limiting/derating
- **Operation**: Works with linear power derating system to reduce current as temperature increases

### Over Current Warning (Disabled)
- **Implementation**: Commented out in `Interfaces.c` lines 266-268
- **Previous Logic**: Would set/clear warning bit 1 (0x02) based on `protectionOverCurrent.triggered`
- **Current Status**: Disabled to avoid noise; same bit (0x02) now used for OverTempWarn

### PT100 Connection Warning System
- **Active Bit**: 2 (0x04) - `PT100Connection`  
- **Implementation**: `Controller.c` lines 36, 39, 46 in `_checkTemperature()` function
- **Trigger Logic**:
  - Sets when: `controller.flagPt100 == ENABLED` AND `Tpt.flagOpen == ENABLED`
  - Clears when: PT100 is connected OR PT100 feature is disabled
- **Purpose**: Warns when PT100 temperature monitoring is enabled but sensor is not physically connected
- **Distinction**: This is different from PT100Broken error - this warns about missing sensor when feature is enabled

### PT100 Temperature Warning System
- **Warning Bits**: 
  - Bit 4 (0x10): `PT100WarningTemp` - Over temperature warning
  - Bit 6 (0x40): `PT100UnderTempWarning` - Under temperature warning
- **Implementation**: `Interfaces.c` lines 297-300 (over temp), 305-308 (under temp)
- **Trigger Conditions**:
  - **Over Temp**: `controller.flagPt100` AND `measuredValues.CPT100 > controller.Pt100WarningTemp`
  - **Under Temp**: `controller.flagPt100` AND `measuredValues.CPT100 < controller.pt100LowWarningTemp`
- **Requirements**: Both require `controller.flagPt100` to be enabled
- **Purpose**: Early warning system before reaching error/alarm thresholds

### Battery Type Mismatch Warning System
- **Active Bit**: 5 (0x20) - `WrongBattWarn`
- **Implementation**: 
  - `Controller.c` lines 129, 135, 141 in `outputAutoDetect()` function
  - `Interfaces.c` lines 472, 478, 483 in mode switching logic
- **Trigger Conditions**:
  - **Auto-detect mode**: When battery voltage doesn't match expected ranges (12V/24V)
  - **Manual mode**: When measured voltage doesn't match configured charge voltage
- **Clearing**: Automatically clears when voltage matches expected ranges
- **Purpose**: Alerts user to check battery type selection or wiring connections

### Battery Connection Detection System
- **Purpose**: Detects whether a battery is actually connected to the charger output
- **Detection Method**: Applies 12V test voltage and analyzes voltage/current response ratios
- **Detection Algorithm**:
  - Runs every 6 minutes when current is below 90% of effective current
  - Stores baseline voltage and current measurements
  - Applies 12V test voltage for 100ms
  - Compares voltage and current change ratios
  - Battery connected: Current ratio significantly higher than voltage ratio
  - No battery: Voltage and current ratios approximately equal (resistive load)
- **Protection Trigger**: After 10 consecutive failed detections within 1 hour
- **Protection Delay**: 1 second after batteryConnectionStatus becomes 1
- **Status Variable**: `batteryConnectionStatus` (0 = connected, 1 = disconnected)
- **Configuration Parameters** (in Controller.h):
  - `BAT_CONN_CHECK_DURATION_MS`: 100ms monitoring duration
  - `BAT_CONN_TEST_VOLTAGE_MV`: 12000mV test voltage
  - `BAT_CONN_CHECK_INTERVAL_MS`: 360000ms (6 minutes) between checks
  - `BAT_CONN_MAX_FAILED_CHECKS`: 10 consecutive failures required
  - `BAT_CONN_CHECK_WINDOW_MS`: 3600000ms (1 hour) time window
  - `BAT_CONN_CURRENT_THRESHOLD_PERCENT`: 90% effective current threshold
  - `BAT_CONN_VOLTAGE_THRESHOLD_MV`: 100mV voltage tolerance
  - `BAT_CONN_RATIO_TOLERANCE_PERCENT`: 20% ratio comparison tolerance
- **Result**: When triggered, sets error flag bit 7 (0x80), relay enters RELAY_ERROR state
- **Detailed Documentation**: See `battery_connection_detection.md` for complete algorithm description

### Power Limiting (Derate) System
- Dynamic power limiting vs. temperature (linear derate) with final cutoff at trip temperature.

## Notes & Revision History

1. Bits are auto‑clearing when protection conditions reset.
2. Errors enforce relay safe state; warnings are informational only.
3. LED priority ensures a single visible pattern (most critical first).
4. Deprecated warning bits (ADCOpen, OverCurrent) retained for traceability.
5. Battery disconnect & PT100 integrity moved to ERR domain for safety.

### Recent Updates (Oct 2025)
- **Complete Code Analysis**: Thoroughly analyzed `Controller.c` and `Interfaces.c` for all `controller.flagWARN` usages
- **Accurate Implementation Table**: Created detailed table showing exact source code locations and trigger conditions
- **Bit Usage Clarification**:
  - Bit 0 (0x01): ADCOpen - Completely commented out, not functional
  - Bit 1 (0x02): Repurposed from OverCurrent to OverTempWarn for thermal derating system  
  - Bit 2 (0x04): PT100Connection - Active warning for missing sensor when feature enabled
  - Bit 4 (0x10): PT100WarningTemp - Active temperature warning system
  - Bit 5 (0x20): WrongBattWarn - Dual implementation in auto and manual modes
  - Bit 6 (0x40): PT100UnderTempWarning - Active cold temperature warning
- **Disabled Features**: Documented OverCurrent warning disable in Interfaces.c (lines 266-268)
- **Source Code Synchronization**: Ensured 100% accuracy between documentation and actual implementation
- **Function-Level Detail**: Added specific function names and line numbers for each warning implementation

---
*Last update: October 22, 2025*

---
*This document was prepared for DBC2 Battery Charger Firmware.*
*Last update: October 17, 2025*

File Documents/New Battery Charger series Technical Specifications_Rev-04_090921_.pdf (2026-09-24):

# ENKO Ltd

### Projectname:

### DEIF NEW BATTERY CHARGERS

### Document name:

### TECHNICAL SPECIFICATIONS AND MODELS DESCRIPTION

### Customer:

### DEIF / DENMARK

### Date:

### 04/AUG/2021 17/AUG/2021 26/AUG/2021 01/SEP/2021 09/SEP/2021

### EXPLANATIONS:

### THIS DOCUMENT PRESENTS THE FINAL TECHNICAL SPECIFICATIONS

FOR THE NEW BATTERY CHARGER SERIES TO BE DESIGNED FOR DEIF. DOCUMENT CONTAINS ELECTRICAL AND MECHANICAL SPECIFICATIONS.

### THIS DOCUMENT IS REVISED TO “REV01” ON 18/AUG/2021

### DOCUMENT IS REVISED BASED ON MAIL SENT BY LENE SKJERNAA ON

20/08/2021

### REV-04 EXPLAINS THE EXPECTED COST IMPACT AND DIFFERENCES IN TECHNICAL SPECIFICATIONS WITH REFERENCE TO PPT PRESENTATION DOCUMENT PREVIOUSLY SHARED WITH DEIF

### Revision:

R00
R01
R02
R03
R04

### Preparation:

### ENKO R&D

### Contents:

### - PROJECT SCOPE - MODEL DESCRIPTIONS - TECHNICAL SPECIFICATIONS (REVISED TO “REV-04”) - COMMENTS

### Written:

### S. KAZAZOGLU

### Control:

### M. AKAR

Approved: | Pages:
| 21 (INCLUDING COVER)

### REF:

### DEIF_T_090921

### ENKO LTD 10006 sokak, No: 64 AOSB

Çiğli IZMIR – TURKEY | Tel: 0090 232 3767806

### ENKO Electronic Control Systems

### September 9, 2021

www.enkoelektronik.com | Tel: 0090 232 3767806 | Page | 2

## PROJECT BACKGROUND:

This project was initiated in order to create a new `Battery Charger` series for DEIF with up-to-date technology and specifications and at the same time, renew the mechanical construction design to suit market demand.

Both DEIF and ENKO technical teams participated in a series of discussions to determine the final technical specifications for these new charger series and final specifications document is generated and published in the following chapters. A revision can be made to these specifications before the project starts and all changes will be followed by revision updates, based on this document.

## GENERAL DESCRIPTION OF THE MODELS:

Based on the technical discussions till date, the model arrangement of the new battery chargers is given in the

### table below:

MODELS: | 75W | 150W | 300W | 600W | 1200W
MODEL – A | 12V/5A
MODEL – B | | 12V10A 24V/5A
MODEL – C | | | 24V/10
MODEL – D | | | | 24V/20A
MODEL – E | | | | | 24V/40A

The above model names will be nominated by DEIF in the later stages of the project. MODEL-B is a 150W package device and charge voltage will be user selectable in the field.

## NOTES ON CHARGER SPECIFICATIONS:

Rev-03 contains all the revisions we have been discussing during our meetings with DEIF project team. This is the final technical specifications document for DEIF Charger project.

Model names are given as reference to this document and DEIF should determine each model name and description.

Mechanical dimensions are given as reference in this document and only approximate dimensions are given. During design phase, exact dimensions will be calculated and published in respective documents. Charger enclosure design work will be made in ENKO and plastic injection molds will be manufactured in ENKO.

Reinforced insulation term is used instead of “Double Insulation” as double insulation refers to non-earthed devices where output is completely FLOATING, and input is not connected to EARTH point. This is not the case in DEIF charger series.

### September 9, 2021

www.enkoelektronik.com | Tel: 0090 232 3767806 | Page | 3

Revision Rev-04 includes notes on added technical specifications with reference to the initial specifications document (ppt document) shared with DEIF initially and the estimated cost impact on the models, based on normal component prices (impact of component shortage premium costs is not included in this calculation).

## MODEL-A: 12V/5A (75W PACKAGE)

This is the basic model and will be based on flyback converter topology. Targeted efficiency will be better than 86% at 220Vac input voltage and above 50% load conditions.

Specification | Description

Input Specifications:

AC Supply Input Voltage range: | Universal AC power input
(withstand to 300Vac)
88.0Vac min. | 265Vac max.
@ full-load conditions
Operating Input Frequency range: | 50Hz / 60Hz | 45Hz | 70Hz
| | 120V | 400V
DC Input voltage range: | DC volts
@ full-load conditions
Continuous Input current at full load condition: | @ 5A load condition | @ 90Vac input | <1.8Aac (typ.)
| | @ 220Vac input | <0.7Aac (typ.)
Efficiency: | >83% worst case condition (typical efficiency: 85%)
Input Power Factor: | >0,65 Capacitive (no PFC compensation)
Input fuse protection: | PCB mounted, non-replaceable fuse (no user serviceable parts)
Rated input power: | <88W max. at full load. (@ worst case efficiency)
Input terminal type: | Enclosure front panel mounted | Mains input | GSTB 2.5 / 3 (12Adc) Phoenix three pole screw type terminal set
| | DC output | MSTB 2.5 / 6 (12Adc) Phoenix six pole screw type terminal set

Output Specifications:

Output voltage range:
12V model only

Factory set at 13.8Vdc float charge Boost mode: 14.5Vdc (gassing level)

Output current range: | 0Adc to 5Adc (load dependent)
Short-circuit current: | 100% rated output current into short circuit, continuous operation.
Output ripple voltage: | <1.0% of nominal output voltage over 10Hz to 100KHz
Output voltage tolerance: | <±1.5% of set value

### September 9, 2021

www.enkoelektronik.com | Tel: 0090 232 3767806 | Page | 4
Current limit: | 100% rated current during BULK and ABSORPTION charging modes
Boost mode control: | Built-in automatic boost function, (boost mode charge current derating value will be decided during design phase.)
Output noise level: | <1.2V pk-pk (30KHz to 300KHz) connected to resistive load
Line regulation: | <1% over 100Vac to 265Vac input voltage range at constant output load (not exceeding rated load)
Load regulation: | <1% at constant input voltage, from 10% load to 90% load on the output, measured at the output terminals
Reverse polarity protection: | Active protection | “Automatic Resettable” SS reverse polarity protection. No external component (fuse) is required.
Front panel indicators: | Multicolor LED indicator for status and alarm conditions: • Float mode (normal operation): steady green • Boost mode: blinking green • Failure: blinking red
Auxiliary output: | Alarm output, N/O contact relay (SPST), 250Vac@1A, AC3 class

Environmental conditions:

Operating temperature range: | -40ºC to +70ºC with output power derating
Output Power derating: | Output power is linearly de-rated starting at 55ºC down to 50% rated current at TAMB = 70ºC (approx. -3.5%/⁰C power derating above 55⁰C))
Storage temperature and humidity: | -40ºC to +85ºC, (0%Rh to 95%Rh, non-condensing)
Cooling type: | Convection cooled (vertical mounted, no physical obstacles are allowed within 20mm from both sides and minimum 50mm for top and bottom sides)
Operating humidity range: | 0%Rh to 95%Rh, non-condensing with AC supply connected. Derating may activate below 30%RH depending on operating conditions.
Altitude: | <2000mt at full rated load. Derate linearly from full power to 50% power from 2000mt to 3000mt over the specified working temperature range.
Dielectric withstanding voltage: | Mains input – DC output, Boost input & Alarm o/p (with voltage input terminals shorted) Reinforced-insulation between primary and secondary circuits. | 4.0 KVDC @ 70% RH
| Mains input – Earth (voltage input terminals shorted) | 2,5 KVDC @ 70% RH
| DC Output – Earth (with output terminals shorted) | 0,5 KVac @ 70% RH
| Alarm o/p - DC out & Boost terminals | 2,5 KVDC @ 70% RH
ESD protection: | 8kV free air discharge onto the metal case and plastic housing (metal case connected to EARTH)
EMI noise immunity: | IEC/EN 61000-6-2,
Conducted and radiated EMC: | IEC/EN61000-6-4, IEC/EN61000-4-4, IEC/EN61000-4-5, IEC/EN61000-4-6, IEC/EN61000-4-11, IEC/EN61000-3-2, Light industry noise emission level

### September 9, 2021

www.enkoelektronik.com | Tel: 0090 232 3767806 | Page | 5
Safety standard compatibility: | UL508, EN61000-4-2 (ESD),
Vibration (non-operating): | Swept Sine (EN60068-2-6): 2G, 18-500 Hz, 3 primary axes. Random: 20-500Hz
Protection class: | IP20 protection class (minimum)
Output protection fuse: | No output protection fuse. Short circuit protection provided with electronic hardware design
Terminal Protection: | Terminals are inset within the plastic enclosure. Protected against accidental touch.

Standards Agency Compliancy:

All models: | CE compliant (LVD, EMC and RoHS directives, no certification) UL compliant (no certification)

Additional functions:

Alarm Output:

| Relay contact, coil activated during normal operation (energized for power good signal)
N/O contact relay | Relay contact, potential-free N/O contact (energized and closed under normal operating conditions) Contact capacity: 230Vac/1A max.
| AC/DC failure: | Relay de-energized, if: 1. AC power input is lost 2. If charger DC output is lost
| Low DC output: | Relay de-energized, if: 1. Charger DC output voltage VDC<88%VFLOAT 2. Alarm RESET if VDC>92%VFLOAT
| High DC output: | Relay de-energized, if: 1. Charger DC output voltage VDC>107%VFLOAT 2. Alarm RESET if VDC<105%VFLOAT
| Overvoltage: | Relay de-energized, if: 1. VDC>16VDC (on 12VDC charger) 2. VDC>30.5VDC (on 24VDC charger)
| Battery Disconnect: | Relay de-energized, if: Battery load is disconnected (alarm time delay 10 to 20 minutes)
Communication: | USB com port | Type-B USB socket, non-isolated, for device configuration purpose only.
Temperature measurement: | Pt-100 RTD sensor | Range: -40⁰C to +100⁰C for battery terminal voltage compensation (sensor not supplied)
Boost Enable/Disable: | Automatic BOOST function | Integrated “Automatic Boost” function, with an additional external BOOST control input (user selectable)
| Serial connection: | Not allowed
| Parallel connection: | Multiple units of same model can be connected in parallel to increase total output current value and/or to introduce redundancy. Current sharing is based on V-I characteristics of each individual charger unit in the stack.

Alarm Functions:

Charger stacking:

### September 9, 2021

www.enkoelektronik.com | Tel: 0090 232 3767806 | Page | 6
Label: | Printed, compliant to UL standards | Stamp printed on front panel cover | Model number Serial number, terminal definition Input limits Warnings Compliance, LED definition Alarm output indication.
| Live – Earth

Input Surge Protection:

Capacitive decoupling
Neutral – Earth | Common mode noise filter
Live-Neutral | MOV protected
Earth Leakage Current: | Live-Neutral to Earth: | <1mA | 50Hz – 60Hz ±10%
| Nylon 66 plastic material with GF reinforcement | Black / 25%GF | No additional colouring
| | UL94 (1,5mm HB) | 850⁰C glow wire test compliant
Plastic enclosure:

Mounting

DIN rail mount | Screw mounting with wall-
Screw mount | mount plate
Mechanical dimensions: | L x W x H | To be determined during design phase

### REVISED TECHNICAL SPECIFICTIONS FOR 75W MODEL:

### - USB non-isolated communication port added with type-2 socket - Temperature compensation RTD sensor port added - External BOOST control terminal added - Foldback current limiting changed to full rated current into short circuit

### Initial estimated cost of 75W model was: $22.60

Estimated cost with added features: | $28.20

## MODEL-B: 12V/10A & 24V/5A (150W Package)

This is the model with dual-battery voltage selection. The topology is based on flyback conversion and targeted efficiency will be around 86% at 220Vac input and more than 50% output load.

Specifications | Description

Input Specifications:

AC Supply Input Voltage range: | Universal AC power input
(withstanding to 300Vac)
88.0Vac min. | 265Vac max.

@ Full load conditions

Operating Input Frequency range: | 50Hz / 60Hz | 45Hz min. | 70Hz max.
| | 120V min. | 400V max.
DC Input voltage range: | DC volts
@ full load conditions
Continuous Input current: | @ Full load | 90Vac input | <3.23Aac
| | 220Vac input | <1.22Aac

### September 9, 2021

www.enkoelektronik.com | Tel: 0090 232 3767806 | Page | 7
Efficiency: | >83% worst case condition
Rated input power: | <178W @ full load and worst-case efficiency conditions
Input Power Factor: | >0.65 Capacitive (no PFC compensation)
Input fuse protection: | PCB mounted, non-replaceable fuse (no user serviceable parts)
Input terminal type: | 12V/10A 24V/5A | Mains | GSTB 2.5 / 3 Three pole Phoenix screw type terminal set
| | Battery | MSTB 2.5 / 6 six pole Phoenix screw type terminal set

Output Specifications:

Output voltage (VFLOAT):

| 12V selection (user configurable) | Factory set at 13.8Vdc Boost mode: 14.7Vdc
| 24V selection (user configurable) | Factory set at 27.6Vdc Boost mode: 29.4Vdc
| 12V selection | 10A
| 24V selection | 5A
Short-circuit current: | Full rated current into short circuit, continuous operation
Output ripple voltage: | <1.0% of nominal output voltage over 10Hz to 100KHz
Current limit: | Automatic current limitation at rated o/p current value, based on selected battery voltage setting.
Boost mode control: | Built-in automatic boost function control, BOOST charge current limit to be decided during design phase.
Output noise level: | <1.5V pk-pk (30KHz to 300KHz)
Line regulation: | <1% over specified input voltage range at constant output load (not exceeding rated load)
Load regulation: | <1% at constant input voltage, from no load to full load on the output, measured at the output terminals, no current limiting conditions
Output Voltage ripple: | <160mV pk-pk at full load
Battery voltage selection: | Battery voltage selection is user configurable from USB communication port
Reverse polarity protection: | 12V/10A 24V/5A | “Automatic Resettable” electronic reverse polarity protection. No external components (fuse) required.
Front panel indicators: | Multicolor LED indicator for status and alarm conditions: • Bulk, Absorption and Float modes: steady green • Boost mode: blinking green • Failure: steady red Battery voltage selection: • Green LED for 12V and 24V selected battery voltage indication
Auxiliary output: | Alarm relay output | N/O contact, 250Vac@1A AC3 class

Output current range:

Environmental conditions:

Operating temperature range: | -40ºC to +70ºC with power derating
Output Power derating: | Output power is linearly de-rated starting at 55ºC down to 50% of its rated capacity at 70ºC. (7pprox... -3.5%/⁰C power derating above 55⁰C)

### September 9, 2021

www.enkoelektronik.com | Tel: 0090 232 3767806 | Page | 8
Storage temperature and humidity: | -40ºC to +85ºC, (0%rh to 95%rh, non-condensing)
Cooling type: | Convection cooled (vertical mounted and no physical obstacles are allowed within 30mm from each side and 50mm between top and bottom sides)
Operating humidity range: | 0%Rh to 95%Rh, non-condensing and AC supply connected. Derating may activate below 30%RH depending on operating conditions
Altitude: | 2000mt at full rated load. De-rate linearly from full power to 50% power from 2000mt to 3000mt over the specified working temperature range.
| Mains input – DC output, Boost input & Alarm o/p (with voltage input terminals shorted) Reinforced-insulation between primary and secondary cicuits. | 4.0 KVDC @ 70% RH
| Mains input – Earth (voltage input terminals shorted) | 2,5 KVDC @ 70% RH
| DC Output – Earth (with output terminals shorted) | 0,5 KVac @ 70% RH
| Alarm o/p - DC out & Boost terminals | 2,5 KVDC @ 70% RH

Dielectric withstanding voltage:

ESD protection: | 8kV free air discharge onto plastic front cover and metal case (metal case connected to Earth)
EMI noise immunity: | IEC/EN 61000-6-2,
Conducted and radiated EMC: | IEC/EN61000-6-4, IEC/EN61000-4-4, IEC/EN61000-4-5, IEC/EN61000-4-6, IEC/EN61000-4-11, IEC/EN61000-3-2, Light industry noise emission level
Safety standard compatibility: | UL508, EN61000-4-2 (ESD),
Vibration (non-operating): | Swept Sine (EN60068-2-6): 2G, 18-500 Hz, 3 primary axes.
Environmental Protection class: | IP20 protection class (minimum)
Output protection fuse: | No output protection fuse. Short circuit protection with electronic hardware
Terminal Protection: | Terminals are inset within the plastic enclosure. Protected against accidental touch.

Standards Agency Compliancy:

All models: | CE compliant (LVD, EMC and RoHS directives, no certification) UL safety standard compliant (no certification)

Additional functions:

Alarm Output:

| Relay contact, active during normal operation (energized for power good signal)
Relay fitted as standard | Relay contact, potential-free N/O contact (Energized under normal operating conditions) Contact capacity: 230Vac/1A max.
| AC/DC failure: | Relay de-energized, if: 1. AC power input is lost 2. If charger DC output is lost
| Low DC output: | Relay de-energized, if: 1. Charger DC output voltage VDC<88%VFLOAT 2. Alarm RESET if VDC>92%VFLOAT
Alarm Functions:

### September 9, 2021

www.enkoelektronik.com | Tel: 0090 232 3767806 | Page | 9
| High DC output: | Relay de-energized, if: 1. Charger DC output voltage VDC>107%VFLOAT 2. Alarm RESET if VDC<105%VFLOAT
| Overvoltage: | Relay de-energized, if: 1. VDC>16VDC (on 12V charger) 2. VDC>30.5VDC (on 24V charger)
| Battery Disconnect: | Relay de-energized, if: Battery load is disconnected (alarm time delay, aprox. 10 to 20 minutes)
Boost Enable/Disable: | Automatic BOOST function | Integrated “Automatic Boost” function, with an additional external BOOST control input (user selectable)
Communication: | USB com port | Type-B USB socket, non-isolated, for device configuration purpose only.
Temperature measurement: | Pt-100 RTD sensor | Range: -40⁰C to +100⁰C for battery terminal voltage compensation (sensor not supplied)
| Serial connection: | Not allowed
| Parallel connection: | Multiple similar models can be connected in parallel to increase total output current value and/or to introduce redundancy. Current sharing is based on V-I characteristics of individual charger in the stack.
Label: | Stamp printed, compliant to UL standards | Printed on front cover | Model number Serial number Terminal definition Input limits Warnings Compliance, LED definition Alarm output indication,
| Live – Earth

Charger stacking:

Input Surge Protection:

Capacitive decoupling | Common mode noise
filter in the input circuit Neutral – Earth
Live-Neutral | MOV protected
Earth Leakage Current: | Live-Neutral to Earth: | <1mA | 50Hz – 60Hz ±5%
| Nylon 66 with GF reinforcement filling | Black / 25%GF | no additional colouring
| | UL94 (1,5mm HB) | 850⁰C glow wire test compliant
Plastic enclosure:

Mounting

DIN rail mount | Screw mounting with
Screw mount | wall-mount plate.
Mechanical dimensions: | L x W x H | Mechanical dimensions will be determined during design phase

### REVISED TECHNICAL SPECIFICTIONS FOR 150W MODEL:

### - USB non-isolated communication port added with type-2 socket - Temperature compensation RTD sensor port added - External BOOST control terminal added - Foldback current limiting changed to full rated current into short circuit

### Initial estimated cost of 150W model was: $31.60

Estimated cost with added features: | $37.80

### September 9, 2021

www.enkoelektronik.com | Tel: 0090 232 3767806 | Page | 10

## MODEL-C: 24V/10A (300W package)

This package is a 24V model and will be based on forward conversion topology. Input stage will be designed with PFC circuit and targeted efficiency will be above 88% at 220Vac input voltage and above 50% output load.

Specification | Description

Input Specifications:

AC Supply Input Voltage range: | Universal input
(withstand to 300Vac)
88.0Vac min. | 265Vac
@ Full load condition
Operating Input Frequency range: | 50Hz / 60Hz | 45Hz min. | 70Hz max.
DC operating input voltage range: | DC Volts | 120VDC min @ full load conditions | 400VDC max. @ full load conditions
Continuous input current at full load condition: | 300W package (Cosφ >0.97 with PFC correction circuit) | 90Vac input | <4.40Aac
| | 220Vac input | <1.85Aac
Efficiency: | >88% worst-case condition
Input Power Factor: | >0.97 with “Power Factor Corrected” input circuit design
Input fuse protection: | PCB mounted, replaceable glass fuse protection on the input circuit
Input terminal type: | 24Vdc model only | Mains | GSTB 2.5 / 3 (12Adc) Three pole screw type Phoenix terminal set
| | Battery | MSTB 2.5 / 6 (12Adc) six pole screw type Phoenix terminal set

Output Specifications:

Output voltage:

| Float voltage setting | Factory setting: 27.6Vdc
| Boost voltage setting | Factory setting: 29.0Vdc
Output current range: | 24vdc | 0 – 10Adc load dependent
Output terminal types: | PCB mounted | 16Adc | Phoenix Screw type terminal set
Short-circuit current: | Rated output current (10Adc) into short circuit, continuous operation
Output ripple voltage: | <1.0% of nominal output voltage over 10Hz to 100KHz
Current limit: | 100% rated current during BULK and ABSORPTION charging modes
Boost mode control: | Built-in automatic boost function, with one EXTERNAL Boost control input. Boost charging current derating will be decided during design phase.
Output noise level: | <1.5V pk-pk (30KHz to 300KHz)
Line regulation: | <1.0% over 100Vac to 300Vac between -20⁰C to 55⁰C at 50% constant load condition
Load regulation: | <1.0% at constant input voltage between 115Vac and 265Vac, from 10% load to 90% load on the output, measured at the output terminals over -20⁰C and 55⁰C operating temperature
Output Voltage ripple: | <150mV pk-pk at full load conditions

### September 9, 2021

www.enkoelektronik.com | Tel: 0090 232 3767806 | Page | 11
Reverse polarity protection: | With 24V battery connected to output terminals | “Automatic Resettable” electronic reverse polarity protection. No external components (fuse) required.
Front panel indicators: | Multicolor LED indicator for status and alarm conditions: • Bulk, Absorption and Float mode charging: steady green • Boost mode: blinking green • Failure: steady red
Auxiliary output: | Alarm relay output | N/O contact, 250Vac@2A AC3 class

N/C contact, 250Vac@1A AC3 class

Environmental conditions:

Operating temperature range: | -40ºC to +70ºC ambient temperature. Starting at 55⁰C ambient, output power will be linearly derated down to 50% of rated output power at 70⁰C
Output Power derating: | Output power is linearly de-rated starting at 55ºC down to 50% of its rated capacity at 70ºC. Output will cut off at TAMB > 70ºC
Storage temperature and humidity: | -40ºC to +85ºC, (10%rh to 95%rh, non-condensing)
Cooling type: | Convection cooled (vertical mounted and no physical obstacles are allowed within 30mm from each side and 50mm above and below)
Humidity: | 0%Rh to 95%Rh, non-condensing and AC supply connected. (power derating may become active below 30%RH)
Altitude: | Up to 2000mt at full rated load (input voltage >110Vac) De-rate linearly from full power to 50% power from 2000mt to 3000mt over the specified operating temperature range.
| Mains input – DC output, Boost input & Alarm o/p (with voltage input terminals shorted) Reinforced insulation between primary and secondary circuits. | 4.0 KVDC @ 70% RH
| Mains input – Earth (voltage input terminals shorted) | 2,5 KVDC @ 70% RH
| DC Output – Earth (with output terminals shorted) | 0,5 KVac @ 70% RH
| Alarm o/p - DC out & Boost terminals | 2,5 KVDC @ 70% RH

Dielectric withstanding voltage:

ESD protection: | 8kV free air discharge onto the metal case and plastic enclosure (metal case connected to EARTH)
EMI noise immunity: | IEC/EN 61000-6-2,
Conducted and radiated EMC: | IEC/EN61000-6-4, IEC/EN61000-4-4, IEC/EN61000-4-5, IEC/EN61000-4-6, IEC/EN61000-4-11, IEC/EN61000-3-2, Light industry noise emission level
Safety standard compliance: | UL508, EN61000-4-2 (ESD),
Vibration (non-operating): | Swept Sine (EN60068-2-6): 4G, 18-500 Hz, 3 primary axes. Random: 20-500Hz,
Environmental Protection class: | IP20 protection class (minimum)
Output protection fuse: | No output protection fuse. Short circuit protection with electronic hardware
Terminal Protection: | Terminals are inset within the plastic enclosure. Protected against accidental touch.

### September 9, 2021

www.enkoelektronik.com | Tel: 0090 232 3767806 | Page | 12

Standards Agency Compliancy:

All models: | CE compliant (LVD, EMC and RoHS directives, no certification) UL compliant (no certification)

Additional functions:

Alarm Output:

| Active during normal operation (energized for power good signal)
Relay fitted as standard (SPDT relay) | Relay contact, potential-free N/O - N/C contact (energized under normal operating conditions) Contact capacity: 230Vac/1Aac max.
| AC/DC failure: | Relay de-energized, if: 1. AC power input is lost 2. If charger DC output is lost
| Low DC output: | Relay de-energized, if: 1. Charger DC output voltage VDC<88%VFLOAT 2. Alarm RESET if VDC>92%VFLOAT
| High DC output: | Relay de-energized, if: 1. Charger DC output voltage VDC>107%VFLOAT 2. Alarm RESET if VDC<105%VFLOAT
| Overvoltage: | Relay de-energized, if: 1. VDC>16VDC (on 12V charger) 2. VDC>30.5VDC (on 24V charger)
| Battery Disconnect: | Relay de-energized, if: Battery load is disconnected (alarm time delay, approx. 10 to 20 minutes)
Boost Enable/Disable: | Automatic BOOST function | Integrated “Automatic Boost” function with an additional terminal for external BOOST control
Communication: | USB com port | Type-B USB socket, non-isolated, for device configuration purpose only.
Temperature measurement: | Pt-100 RTD sensor | Range: -40⁰C to +100⁰C for battery terminal voltage compensation (sensor not supplied)
| Serial connection: | Not allowed
| Parallel connection: | Multiple similar units can be connected in parallel to increase total output current value and/or to introduce redundancy. Current sharing is based on V-I characteristics of individual charger in the stack.
Label: | Printed, compliant to UL standards | Stamp printed on enclosure front cover | Model number Serial number. Terminal definition Input limits Warnings Compliance LED definition Alarm output
| Live - Earth

Alarm Functions:

Charger stacking:

Input Surge Protection:

Capacitive coupling | Common mode noise filter stage for conduction EMC
Neutral - Earth
Live-Neutral | MOV protected
Earth Leakage Current: | Live-Neutral to Earth: | <1mA | 50Hz – 60Hz ±5%
Plastic enclosure: | Nylon-6 25%GF | Original Black granules | No coloring
| | UL94 (1,5mm HB) | 850⁰C glow wire test compliant

### September 9, 2021

www.enkoelektronik.com | Tel: 0090 232 3767806 | Page | 13

Mounting

DIN rail mount
Screw mount with | Standard feature
mounting plate
Mechanical dimensions: | L x W x H | To be determined during design phase

### REVISED TECHNICAL SPECIFICTIONS FOR 300W MODEL:

### - PFC input circuit - USB non-isolated communication port added with type-2 socket - Temperature compensation RTD sensor port added - External BOOST control terminal added - Foldback current limiting changed to full rated current into short circuit

### Initial estimated cost of 300W model was: $49.40

Estimated cost with added features: | $62.00

## MODEL-D: 24V/20A (600W package)

This model will be designed with communication capability and topology will be based on LLC resonant converter technology to achieve high efficiency

Specification | Description

Input Specifications:

AC Supply Input Voltage range: | Universal input
(withstanding 300Vac)
88.0Vac min. | 265Vac max.
Full load
Operating Input Frequency range: | 45Hz to 70Hz. (All models can operate at full capacity with DC input voltage feed, within their specified input voltage ranges)
DC Input voltage range: | DC Volts | 120VDC min. @ full load conditions | 400VDC max. @ full load conditions
Continuous Input current at full load condition: | 600W package (Cosφ > 0.97) | 90Vac input | <7.8Aac
| | 220Vac input | <3.0Aac
Efficiency: | >90% worst case condition
Input Power Factor: | >0.97 PFC corrected input stage
Input fuse protection: | PCB mounted, replaceable glass fuse, not front panel accessible.

### September 9, 2021

www.enkoelektronik.com | Tel: 0090 232 3767806 | Page | 14
Input / Output terminal types: | 24Vdc model only | Mains | GSTB 2.5 / 3 (12Adc) Three pole screw type Phoenix terminal set
| | Battery | 40A stud type battery terminals
| | Control and signal | MSTB2.5/6 screw type Phoenix terminals. The number of terminals may vary depending on the required number of external control pins.

Output Specifications:

Output voltage range: | 24Vdc nominal
Factory set at 27.6Vdc | For BULK, ABSORPTION and FLOAT
mode operation
Boost: 29.0Vdc | Boos mode only (gassing limit)
Output current range: | DC amps | 0 to 20A depending on output load
Output terminal types: | 24VDC | 40.0A (contact capacity) | Stud type screw terminal set
Short-circuit current: | Output current cut off below 60% of rated open circuit output voltage level. Full rated current can be delivered, provided that; loaded output voltage is >0.6VOUT-nominal.
Output ripple voltage: | <1.5% of nominal output voltage over 10Hz to 300KHz
Current limit: | 100% rated current in Bulk / Absorb charging modes 50% rated current in Boost mode, governed by rated maximum power and operating conditions,
Boost mode control: | Intelligent BOOST charge mode based on integrated BMS software algorithm. There is an additional terminal for EXTERNAL Boost function control
| Series connection | Not allowed
| Parallel connection | Multiple same model chargers can be connected in parallel to increase output charge current and/or to introduce redundancy. Current sharing of each unit depends on the V-I characteristics of individual charger unit. Intelligent current sharing possible when connected with RBM or EDU accessories.
Output noise level: | <1.5V pk-pk (30KHz to 300KHz)
Line regulation: | <1% over specified input voltage range (90Vac to 265Vac) at constant output load of 50%
Load regulation: | <1.5% at constant input voltage of 220Vac, from 10% load to 90% load on the output, measured across output terminals of the charger unit,
Reverse polarity protection: | All models | “Automatic Resettable” electronic reverse polarity protection. No external components (fuse) required.
Front panel LED indicators: | Multicolor LED indicator for status and alarm conditions: • Bulk, Absorption and Float mode: steady green • Boost mode: blinking green • Failure: steady red • Communication port status indicator • Auxiliary i/o status indicators (high battery temperature)
Alarm output: | Alarm relay output (SPDT) | N/O contact, 250Vac@1A AC3 class

Charger stacking:

N/C contact, 250Vac@1A AC3 class

AUXILIARY I/O: | Digital I/O

2 digital inputs and 1 digital output (solid state protected output) available for external device integration. All AUX i/o connections are non-isolated and rated voltage is 24Vdc.

### September 9, 2021

www.enkoelektronik.com | Tel: 0090 232 3767806 | Page | 15

Environmental conditions:

Operating temperature range: | -40ºC to +70ºC, between 200Vac to 440Vac input voltage range with power derating active
Operating humidity range: | 0%RH to 95%RH (power derating may activate below 30%RH based on the operating conditions), AC power is connected,
Output Power derating: | Output power is linearly de-rated starting at 55ºC down to 50% of its rated capacity at 70ºC. Power derating factor is approx. -3.5%/⁰C from 55⁰C to 70⁰C ambient temp.
Storage temperature and humidity: | -40ºC to +85ºC, (0%rh to 95%rh, non-condensing)
Cooling type: | Convection cooled (vertical mounted and no physical obstacles are allowed within 50mm from each side and 100mm above and below.
Altitude: | 2000mt at full rated load. De-rate linearly from full power to 50% power from 2000mt to 3000mt over the specified working temperature and humidity range.
| Mains input – DC output, Boost input & Alarm o/p (with voltage input terminals shorted) Reinforced-insulation between primary and secondary circuits. | 4.0 KVDC @ 70% RH
| Mains input – Earth (voltage input terminals shorted) | 2,5 KVDC @ 70% RH
| DC Output – Earth (with output terminals shorted) | 0,5 KVac @ 70% RH
| Alarm o/p - DC out & Boost terminals | 2,5 KVDC @ 70% RH

Dielectric withstanding voltage:

ESD protection: | 8kV free air discharge onto plastic enclosure and metal parts (with unit connected to EARTH)
EMI noise immunity: | IEC/EN 61000-6-2,
Conducted and radiated EMC: | IEC/EN61000-6-4, IEC/EN61000-4-4, IEC/EN61000-4-5, IEC/EN61000-4-6, IEC/EN61000-4-11, IEC/EN61000-3-2, Light industry noise emission level
Safety standard compliance: | UL508, EN61000-4-2 (ESD),
Vibration (non-operating): | Swept Sine (EN60068-2-6): 4G, 18-500 Hz, 3 primary axes. Random: 20-500Hz,
Environmental Protection class: | IP20 protection class (minimum)
Output protection fuse: | No output protection fuse. Short circuit current limiting with electronic hardware
Terminal Protection: | Terminals are inset within the plastic enclosure. Protected against accidental touch.

Standards Agency Compliancy:

All models: | CE compliant (LVD, EMC and RoHS directives, no certification) UL compliant (no certification)

Additional functions:

Alarm Output:

| Active during normal operation (energized for power good signal)
SPDT Relay fitted as standard on all models | Relay contact, potential-free N/O - N/C contact (energized under normal operating conditions) Contact capacity: 230Vac/1A AC3 class
Alarm Functions: | AC/DC failure: | Relay de-energized, if: 1. AC power input is lost 2. If charger DC output is lost

### September 9, 2021

www.enkoelektronik.com | Tel: 0090 232 3767806 | Page | 16
| Low DC output: | Relay de-energized, if: 1. Charger DC output voltage VDC<88%VFLOAT 2. Alarm RESET if VDC>92%VFLOAT
| High DC output: | Relay de-energized, if: 1. Charger DC output voltage VDC>107%VFLOAT 2. Alarm RESET if VDC<105%VFLOAT
| Overvoltage: | Relay de-energized, if: 1. VDC>30.5VDC (on 24V charger)
| Battery Disconnect: | Relay de-energized, if: Battery load is disconnected (alarm time delay, approx. 10 to 20 minutes)
| High Battery temperature: | Relay de-energized if: TBATTERY > SET TEMP. POINT
| S/W Alarm warnings: | When connected with COM port, additional alarm and status indication data will be available with PC Tool Software. BMS measured and calculated data will be available from the COM port only.
Boost Enable/Disable: | Automatic BOOST control | Integrated “Automatic Boost” control function plus an additional EXTERNAL Boost control terminal
Label: | Printed, compliant to UL standards | Stamp printed on front cover | Model number Serial number Terminal definition Input limits Warnings Compliance LED definition Alarm output indication
| Live - Earth

Input Surge Protection:

Capacitive coupling Common mode noise filter and PFC circuit for conducted EMC compatibility

Neutral - Earth

Live-Neutral | MOV protected
Earth Leakage Current: | Live-Neutral to Earth: | <1mA | 50Hz – 60Hz ±5%

Communications:

USB (type2): | For device configuration only (no galvanic isolation, for device configuration only) Type-B USB socket on the PCB.
CAN BUS (CAN open): | For connection to peripheral devices and networks. (Galvanically isolated communications and power input)
Battery temperature measuring input: | Pt-100 RTD temperature sensor | Configurable with PC Tool S/W for battery temperature measurement. (sensor not supplied)
| Nylon-6 with GF reinforcement and aluminum heatsink plate | Black | Natural granules, no color granule additives
| | UL94 (1,5mm HB) | 850⁰C glow wire test compliant
| Mounting | Screw mount with mounting plate | Standard feature

Enclosure:

### September 9, 2021

www.enkoelektronik.com | Tel: 0090 232 3767806 | Page | 17

### REVISED TECHNICAL SPECIFICTIONS FOR 600W MODEL:

### - External BOOST control terminal added

### Initial estimated cost of 600W model was: $99.40

No significant cost change.

(please note that; the short circuit current limit is working as “fold-back” current limiting mode in this model. We have not changed this right from the beginning of our discussions).

## MODEL-E: 24V/40A (1200W package)

These chargers will be designed with 3-phase input stage and PFC correction circuit. They will be panel mounted (not suitable for DIN rail mounting).

Specification | Description

Input Specifications:

AC Supply Input Voltage range: | 3-phase input
(no NEUTRAL connection)
200Vac min. | 440Vac max.
Full load conditions
Operating Input Frequency range: | 45Hz to 70Hz.
DC Input voltage range: | DC Volts | 300VDC min. and 550VDC max. Input rectifier diode current rating will be selected according to DC input current values connected across two phases.
Continuous Input current at full load: | 1200W package (Cosφ > 0.97) | 3 x 200Vac input | <3.6Aac
Efficiency: | >93% worst case condition
Input Power Factor: | >0.97 with PFC corrected input stage
Input fuse protection: | PCB mounted, replaceable fuse (not suitable for user servicing)
Input / Output terminal types: | 24Vdc model only | Mains | 1000V rated screw type terminal strip
| | Battery | 100A stud type battery terminals
| | Control and signal | Phoenix MSTB2.5 screw type terminals (required number of terminals)

Output Specifications:

Output voltage range: | 24Vdc nominal | Factory set at 27.6Vdc Boost mode: 29.0Vdc

Configurable via PC
Tool software

### September 9, 2021

www.enkoelektronik.com | Tel: 0090 232 3767806 | Page | 18
Output current range: | DC Amps | 0-40A load dependent
Short-circuit current: | Output current cut off below 60% of rated open circuit output voltage level. Full rated current can be delivered, if; loaded output voltage is >0.6VOUT-nominal.
Output ripple voltage: | <1.5% of nominal output voltage over 10Hz to 300KHz
Current limit: | 100% rated current in Bulk / Absorption and Float charging phases. Output current will cut-off if battery terminal voltage is <60% of nominal battery voltage level.
Boost mode control: | Intelligent BOOST charge mode based on integrated BMS software algorithm. Boost mode can also be configured and controlled via communication ports.
Output noise level: | <1.2V pk-pk (30KHz to 300KHz) at 50% load level.
Line regulation: | <1% over specified input voltage range at 50% output load condition.
Load regulation: | <1.5% at nominal input voltage, from 10% load to 90% load on the output, measured at the output terminals
Output Voltage ripple: | <300mV pk-pk at full load (not in current limit conditions)
Reverse polarity protection: | Solid state protection technology | “Automatic Resettable” electronic reverse polarity protection. No external components (fuse) required.
Front panel indicators: | Multicolor LED indicator for status and alarm conditions: • Float mode: steady green • Boost mode: steady blinking green • Failure: steady red • Communication status indicators • i/o status indicators (high battery temperature)
Alarm output: | SPDT Relay | N/O contact, 250Vac@2A AC3 class

N/C contact, 250Vac@1A AC3 class

Auxiliary input / output: | 24Vdc Digital input and output ports

2 digital inputs and 1 solid-state digital output, non-isolated and rated at 24Vdc. Configurable via PC tool software.
Environmental conditions:
Operating temperature range: | -40ºC to +70⁰C ambient temperature.
Output Power derating: | Output power is linearly de-rated starting at 55ºC down to 50% of its rated output capacity at 70ºC. Output will cut off at around TAMB > 70ºC
Storage temperature range: | -40ºC to +85ºC, (0%rh to 95%rh, non-condensing)
Cooling type: | Convection cooled (vertical mounted and no physical obstacles are allowed within 50mm from each side and 100mm above and below)
Operating Humidity range: | 0%Rh to 95%Rh, non-condensing and AC supply connected. Power derating may activate if humidity is <30%RH under certain operating conditions
Altitude: | 2000mt at full rated load. De-rate linearly from full power to 50% rated power from 2000mt to 3000mt over the specified working temperature range.
Dielectric withstanding voltage: | Mains input – DC output, Boost input & Alarm o/p (with voltage input terminals shorted) Reinforced insulation between primary and secondary circuits. | 4.0 KVDC @ 70% RH

### September 9, 2021

www.enkoelektronik.com | Tel: 0090 232 3767806 | Page | 19
Mains input – Earth (voltage input terminals shorted) | 2,5 KVDC @ 70% RH
DC Output – Earth (with output terminals shorted) | 0,5 KVac @ 70% RH
Alarm o/p - DC out & Boost terminals | 2,5 KVDC @ 70% RH
ESD protection: | 8kV free air discharge onto the metal case (metal case is internally connected to EARTH)
EMI noise immunity: | IEC/EN 61000-6-2,
Conducted and radiated EMC: | IEC/EN61000-6-4, IEC/EN61000-4-4, IEC/EN61000-4-5, IEC/EN61000-4-6, IEC/EN61000-4-11, IEC/EN61000-3-2, Light industry noise emission level
Safety standard compliance: | UL508, EN61000-4-2 (ESD),
Vibration (non-operating): | Swept Sine (EN60068-2-6): 4G, 18-500 Hz, 3 primary axes. Random: 20-500Hz,
Environmental Protection class: | IP20 protection class (minimum)
Output protection fuse: | No output protection fuse. Short circuit protection with electronic hardware
Terminal Protection: | Terminals are inset within the plastic enclosure. Protected against accidental touch.

Standards Agency Compliancy:

All models: | CE compliant (LVD, EMC and RoHS directives, no certification) UL compliant (no certification)

Additional functions:

Alarm Output:

| Active during normal operation (energized for power good signal)
SPDT Relay fitted as standard on all models | Relay contact, potential-free N/O - N/C contact (energized under normal operating conditions) Contact capacity: 230Vac/1A max.
| AC/DC failure: | Relay de-energized, if: 1. AC power input is lost 2. If charger DC output is lost
| Low DC output: | Relay de-energized, if: 1. Charger DC output voltage VDC<88%VFLOAT 2. Alarm RESET if VDC>92%VFLOAT
| High DC output: | Relay de-energized, if: 1. Charger DC output voltage VDC>107%VFLOAT 2. Alarm RESET if VDC<105%VFLOAT
| Overvoltage: | Relay de-energized, if: 1. VDC>30.5VDC (on 24V charger)
| Battery Disconnect: | Relay de-energized, if: Battery load is disconnected (alarm time delay, approx. 10 minutes)
| High Battery temperature: | Relay de-energized if: TBATTERY > SET TEMP. POINT

Alarm Functions:

### September 9, 2021

www.enkoelektronik.com | Tel: 0090 232 3767806 | Page | 20
| S/W Alarm warnings: | When connected with COM port, additional alarm and status indication data will be available with PC Tool Software. BMS measured and calculated data will be available from the COM port only.
Boost Enable/Disable: | All models | Integrated “Automatic Boost” control function. Can be also controlled via com-port with PC-Tool software. There is an additional terminal for EXTERNAL Boost control.
Label: | Printed, compliant to UL standards | Stamp printed on front cover | Model number Serial number Terminal definition Input limits Warnings Compliance LED definition Alarm output and status indications
| Live - Earth

Input Surge Protection:

Capacitive coupling Common mode noise filter Neutral - Earth

Live-Neutral | MOV protected
Earth Leakage Current: | Live-Neutral to Earth: | <1mA | 50Hz – 60Hz ±5%

Communications:

USB (type2): | For device configuration only (no galvanic isolation, for device configuration only) Type-B USB socket on the PCB.
CAN BUS (CAN Open): | For connection to peripheral devices and networks. (Galvanically isolated communications and power input)
Temperature measuring input: | Pt-100 RTD sensor | Configurable with PC Tool S/W for battery temperature measurement. (sensor not supplied)
Power limit selection: | User configurable (600W / 1200W) | Output power can be limited to 600W (with current limit parameter selection) for applications with 3-phase input configuration.
| Nylon-6 with GF reinforcement and aluminum metal heatsink | Black | Natural colored granule, no additional coloring
| | UL94 (1,5mm HB) | 850⁰C glow wire test compliant
| Mounting | Screw mount only on panel surface | Standard feature

Enclosure:

### REVISED TECHNICAL SPECIFICTIONS FOR 1200W MODEL:

### - External BOOST control terminal added

Initial estimated cost of 1200W model was: | $168.00

No significant cost change.

(please note that; the short circuit current limit is working as “fold-back” current limiting mode in this model. We have not changed this right from the beginning of our discussions).

### September 9, 2021

www.enkoelektronik.com | Tel: 0090 232 3767806 | Page | 21

### THIS PAGE IS LEFT BLANK INTENTIONALLY

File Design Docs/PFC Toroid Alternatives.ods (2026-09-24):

Magnetics | ChangSung | Turn | Wire Dia. (mm) | Strand | No Load Ind. (uH) | Full Load Ind. (uH) | Winding Factor (%) | Loss (W) | ΔT (°C) | DC Current (A) | Ir (A) | Core Stack | Power (W)
77071 (https://www.mag-inc.com/Media/Magnetics/Datasheets/0077071A7.pdf) | CS330060G (http://www.changsung.com/file/product/cores/5.%20Sendust%20Cores/TDS_CS330060G.pdf) | 80 | 1 | 2 | 390 | 162 | 50 | 3,7 | 53 | 6 | 5 | 1 | 300
77071 (https://www.mag-inc.com/Media/Magnetics/Datasheets/0077071A7.pdf) | CS330060G (http://www.changsung.com/file/product/cores/5.%20Sendust%20Cores/TDS_CS330060G.pdf) | 95 | 1 | 2 | 550 | 190 | 60,3 | 4,3 | 60 | 6 | 5 | 1 | 300
77083 (https://www.mag-inc.com/Media/Magnetics/Datasheets/0077083A7.pdf) | CS400060G(Stokta var) (http://www.changsung.com/file/product/cores/5.%20Sendust%20Cores/TDS_CS400060G.pdf) | 65 | 1 | 1 | 344 | 189 | 14,3 | 5,7 | 53 | 6 | 5 | 1 | 300
77083 (https://www.mag-inc.com/Media/Magnetics/Datasheets/0077083A7.pdf) | CS400060G(Stokta var) (http://www.changsung.com/file/product/cores/5.%20Sendust%20Cores/TDS_CS400060G.pdf) | 150 | 1 | 1 | 1822 | 357 | 33 | 12 | 100 | 6 | 5 | 1 | 300
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

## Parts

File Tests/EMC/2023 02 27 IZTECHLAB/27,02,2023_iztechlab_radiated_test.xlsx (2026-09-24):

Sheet: DBC2_75W
RE_DBC2_75W |  |  |  | RE_DBC2_75W_2
 | Gate | 120 | ohm |  | Gate | 120 | ohm
 | C5 | N.C. | nF |  | C5 | 2.2 | nF
 | C7 | N.C. | nF |  | C7 | 2.2 | nF

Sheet: Adaptör
RE_Adaptör_1 |  |  | RE_Adaptör_2
 | N.C | pF |  | 470 | pF
 | N.C | pF |  | 470 | pF

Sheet: DBC2_150W
RE_DBC2_150W_1510_B |  |  |  | RE_DBC2_150W_3005_B |  |  |  |  | RE_DBC2_150W_1505_B2 |  |  |  |  | RE_DBC2_150W_1510_B3 |  |  |  |  | RE_DBC2_150W_1510_B4
 |  |  |  | Ters polarite mosfeti hasar gördü |  |  |  |  | D kartı komponentleri B karrtı ile aynı hale getirildi
 |  |  |  |  | Gate | R15 | 42 | Ohm |  | Gate | R15 | 42 | Ohm |  | Gate | R15 | 42 | Ohm |  | Gate | R15
Gate | R15 | 42 | Ohm |  |  | R14 | 82 | Ohm |  |  | R14 | 82 | Ohm |  |  | R14 | 82 | Ohm |  |  | R14
 | R14 | 82 | Ohm |  |  | D5 | 1N4148 |  |  |  | D5 | 1N4148 |  |  |  | D5 | 1N4148 |  |  |  | D5
 | D5 | 1N4148 |  |  | Pri snubb | C17 | 270 | pF |  | Pri snubb | C17 | 270 | pF |  | Pri snubb | C17 | 270 | pF |  | Pri snubb | C17
Pri snubb | C17 | 270 | pF |  |  | R31 | 15 | Ohm |  |  | R31 | 15 | Ohm |  |  | R31 | 15 | Ohm |  |  | R31
 | R31 | 15 | Ohm |  |  | R33 | 15 | Ohm |  |  | R33 | 15 | Ohm |  |  | R33 | 15 | Ohm |  |  | R33
 | R33 | 15 | Ohm |  |  | R334 | 15 | Ohm |  |  | R334 | 15 | Ohm |  |  | R334 | 15 | Ohm |  |  | R334
 | R334 | 15 | Ohm |  |  | R30 | 15 | Ohm |  |  | R30 | 15 | Ohm |  |  | R30 | 15 | Ohm |  |  | R30
 | R30 | 15 | Ohm |  | Sec snubb | C21 | 4.7 | nF |  | Sec snubb | C21 | 4.7 | nF |  | Sec snubb | C21 | 4.7 | nF |  | Sec snubb | C21
Sec snubb | C21 | 4.7 | nF |  |  | R39 | 56 | Ohm |  |  | R39 | 56 | Ohm |  |  | R39 | 56 | Ohm |  |  | R39
 | R39 | 56 | Ohm |  |  | R40 | 56 | Ohm |  |  | R40 | 56 | Ohm |  |  | R40 | 56 | Ohm |  |  | R40
 | R40 | 56 | Ohm |  |  | R41 | 56 | Ohm |  |  | R41 | 56 | Ohm |  |  | R41 | 56 | Ohm |  |  | R41
 | R41 | 56 | Ohm |  |  | R42 | 56 | Ohm |  |  | R42 | 56 | Ohm |  |  | R42 | 56 | Ohm |  |  | R42
 | R42 | 56 | Ohm |  |  | C59 | 4.7 | nF |  |  | C59 | N.C. | nF |  |  | C59 | N.C. | nF |  |  | C59
 | C59 | 4.7 | nF |  |  | C27 | 4.7 | nF |  |  | C27 | N.C. | nF |  |  | C27 | N.C. | nF |  |  | C27
 | C27 | 4.7 | nF |  |  | C73 | 4.7 | nF |  |  | C73 | 4.7 | nF |  |  | C73 | 4.7 | nF |  |  | C73
 | C73 | 4.7 | nF |  |  | C25 | 4.7 | nF |  |  | C25 | 4.7 | nF |  |  | C25 | 4.7 | nF |  |  | C25
 | C25 | 4.7 | nF |  |  | C18 | 4.7 | nF |  |  | C18 | 4.7 | nF |  |  | C18 | 4.7 | nF |  |  | C18
 | C18 | 4.7 | nF |  |  | C74 | 10 | nF |  |  | C74 | 10 | nF |  |  | C74 | 4.7 | nF |  |  | C74
 | C74 | 10 | nF |  |  | C75 | 10 | nF |  |  | C75 | 10 | nF |  |  | C75 | 4.7 | nF |  |  | C75
 | C75 | 10 | nF
 |  |  |  |  |  | Trafo | E42/21/15 |  |  |  | Trafo | E42/21/15 |  |  |  | Trafo | E42/21/15 |  |  |  | Trafo
 | Trafo | E42/21/15 |  |  |  | Lm | 300 | uH |  |  | Lm | 300 | uH |  |  | Lm | 300 | uH |  |  | Lm
 | Lm | 300 | uH
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

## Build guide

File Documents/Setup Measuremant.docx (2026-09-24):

# Leakage Test Setup Measurement

I made the setup measurement for the Leakage test. Measured with 20Vrms 60Hz input signal.

Results of the measurement :

V1 = 20,91Vrms

I1 = 10.74 mA rms

V3 = 5,325Vrms

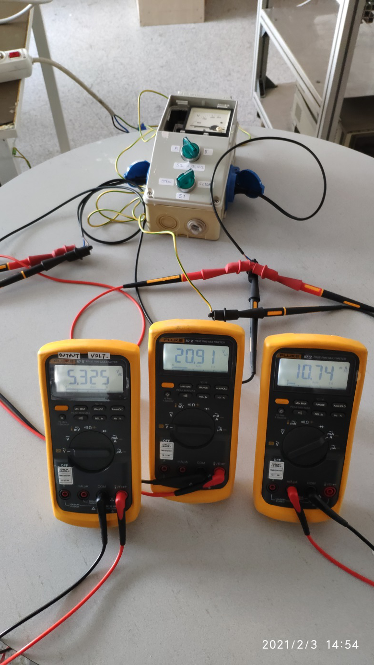
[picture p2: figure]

# Referenced resources:

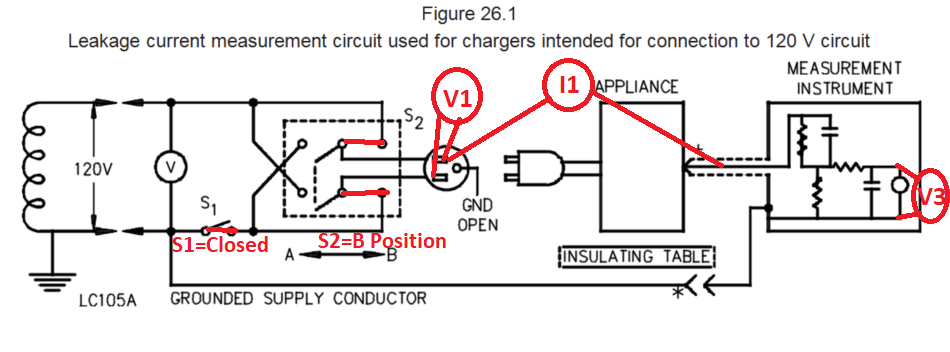
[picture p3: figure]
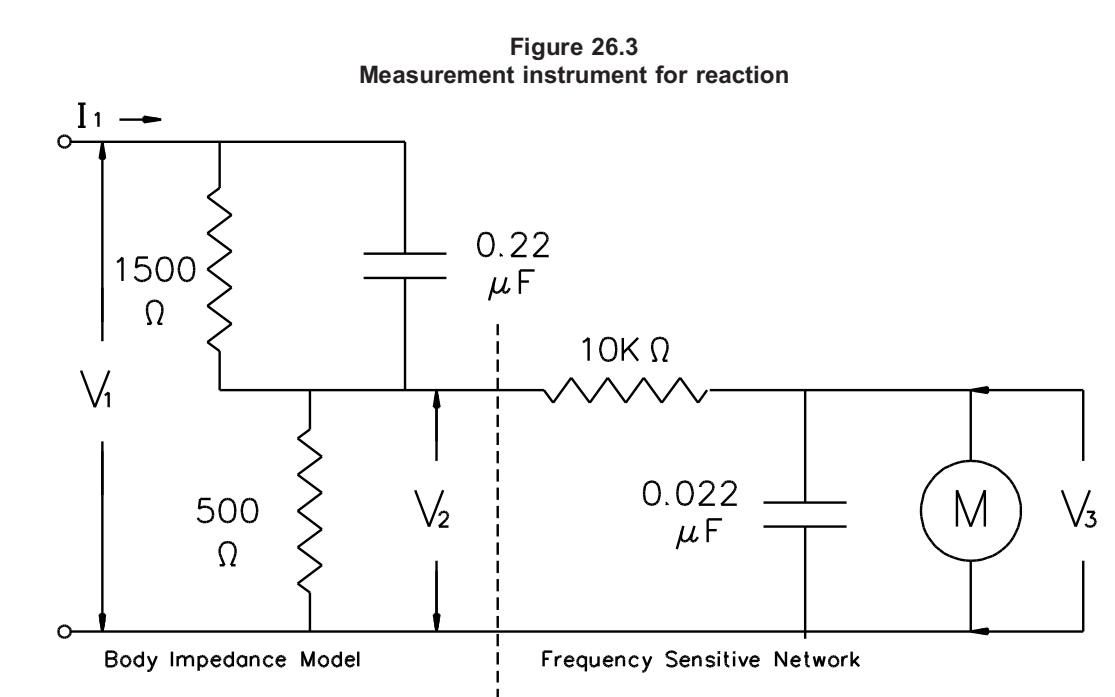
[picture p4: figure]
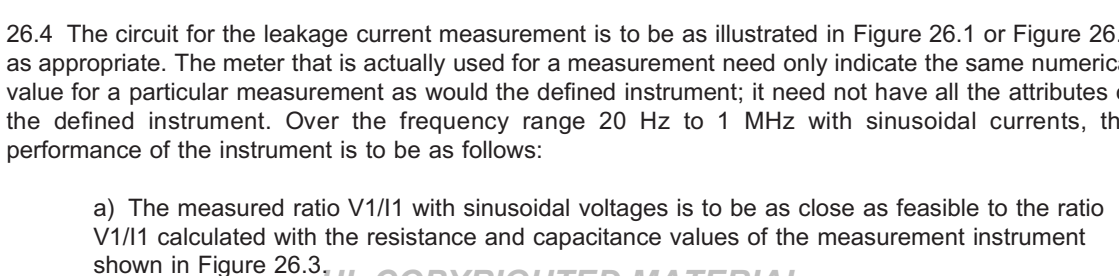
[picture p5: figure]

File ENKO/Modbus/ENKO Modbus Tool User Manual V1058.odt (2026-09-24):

DBC2

ENKO MODBUS TOOL

USER MANUAL

V1003

ENKO Battery Charger Team

March 2023

ENKO Modbus Tool provides interface to the DBC2 device over USB. Using this interface following actions can be taken.

# 1. Connecting to Device

This tool uses modbus over USB to talk with the device. To use it:

- First connect USB from device to PC.

- Then click on Connect/Disconnect toggle.

- Values should be updated on the UI. If not please check the connections and drivers.

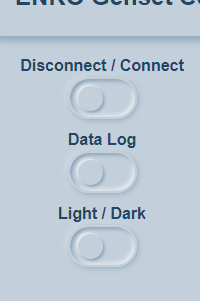
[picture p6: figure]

Image 1

# 2. Reading Output Values

This tool can show you output readings in UI.

Vout is the output Voltage readed from Modbus interface and Iout is the output current. Their units are Volts and Amps accordingly.

Examples:

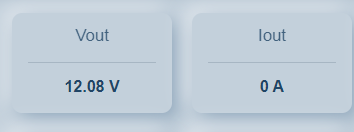
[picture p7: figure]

Image 2

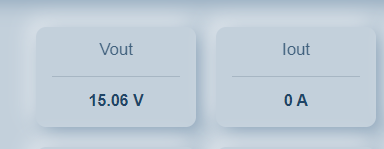
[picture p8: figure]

Image 3

## Readable Parameters

There are few monitoring parameters to see device states and readings. There are few examples below. More information about these monitoring parameters can be found on “Parameter Lists Vxxx” document.

- Vout, Iout, Vbat.

- NTC, RPT100.

- Error and Warning Flags.

- SW Version.

Also all of the settable parameters can be monitored simultaneously.

## Warning And Error Outputs

There is 5 warning situations and 3 error situations for this device. They are visually represented by diagram in Modbus Tool. If any one of them goes to red color this means there is corresponding error happening right now on device.

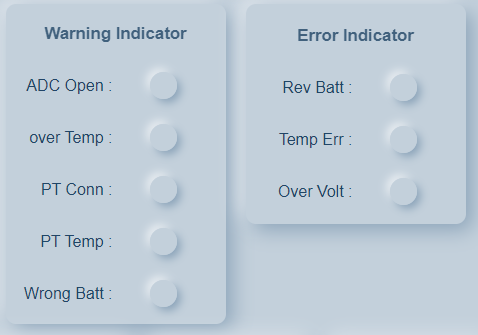
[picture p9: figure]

Image 4

# 3. Configuring Output Values

Output voltage can be controlled with Modbus interface through Vout-set card. Left clicking this card will open a popup window.

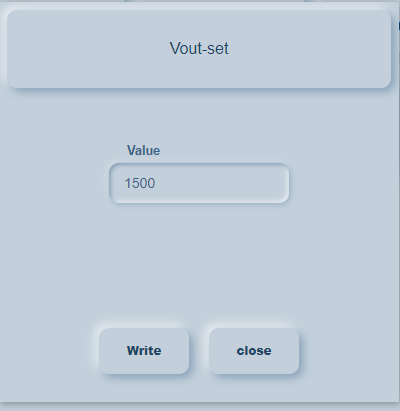
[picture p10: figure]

Image 5

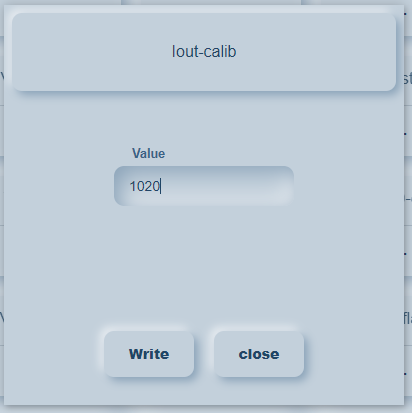
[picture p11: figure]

Image 6

To set output voltage, desired value * 100 should be entered to value box. For example; setting to 12V could be done with 1200. Setting to 13.8V could be done with 1380 value.

Be careful, for the 75W model minimum settable output voltage is 12V and maximum settable output voltage is 15V. Only 1200 – 1500 range can be typed in this box. Otherwise input will be discarded.

After that click on the write button to send value to device. This will trigger an event and if write successful, value can be read back from this card. Otherwise card value won’t change.

After setting V or I out, device will calculate corresponding output power. If this power exceeds device limits, last set value will remain unchanged but complementary one will go for smallest possible value.

Image 7

Image 8

## Settable Parameters

Following parameters can be also settable by this. More information about these parameters can be found on “Parameter Lists Vxxx” document.

- Iout-set.

- Vboost-set.

- isParallel

- Vout, Iout, PT100, NTC, Vbat Calibrations.

- PT100 Activated.

- PSU mode activated

- LED Color, Blink and Period controls.

# 4. Updating Firmware

Firmware update to the device could be done with this tool. Only ENKO firmware, and firmware files are supported.

To use this, click on the “Firmware Update” toggle on left panel. This will open a file manager window to manage firmware file. Locate the firmware file and choose it. After clicking open, update will take some time and your device’s LED’s may flicker few times. If update successful popup will show the output.

Update process should be robust and shouldn't require any user interaction on process. But if it stuck or any external interrupt disturbs update, device can go brick mode. In this case just close Modbus Tool, unplug and plug USB cable then start update process again. It would update just regularly and parameters should not be lost.

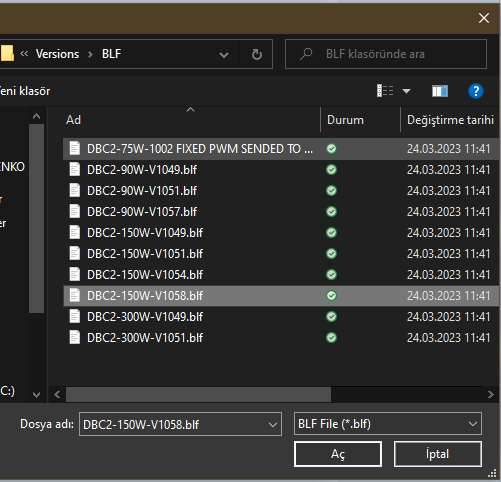
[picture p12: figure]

Image 9

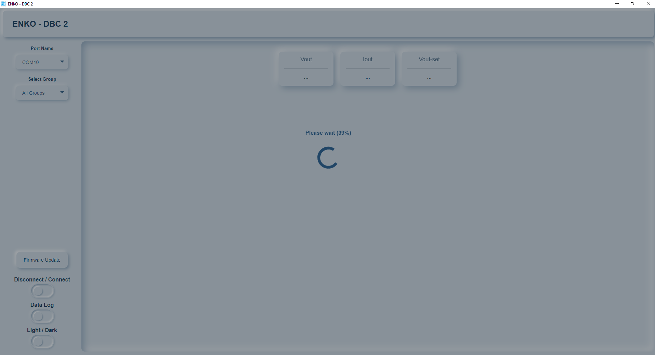
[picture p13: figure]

Image 10

# 5. Logging Info

Logging of the output values versus time could be done with this tool.

To use this click on the Data Log toggle left on your panel. This will open a file manager window. Choose file name and path to save output file. This text file will contain modbus address and value of each card on UI, and will be updated every second.

# 6. UI Theme

User can choose to see Light or Dark theme easily through toggle switch on left plane.

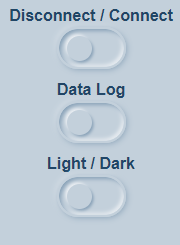
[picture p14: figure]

Image 11

ENKO Control Systems

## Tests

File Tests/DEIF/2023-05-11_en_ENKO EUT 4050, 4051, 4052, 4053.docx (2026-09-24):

Remarks to measurements on the EUT’s

Voltage and current measurements at different input voltages and output currents.

Load is pure resistive. No electronic load used during tests.

Remarks:

The internal current measurement without external load shows 210mA. This was not seen on the first prototypes with the old firmware and seems to be introduced with SW release 1.070. EUT’s with SW 1.058 do not show this issue.

Remarks

The remark above about internal measurements also applies here.

Remarks

The remark above about internal measurements also applies here.

At a load of 10 A at 14.4 Vdc and a supply voltage of 88 Vac the DC-output is not stable. We suspect this is caused by the 100 Hz ripple, that can be seen in the following measurements.

Remarks

The remark above about internal measurements also applies here.

At a load of 10 A at 14.4 Vdc and a supply voltage of 88 Vac the DC-output is not stable. We suspect this is caused by the 100 Hz ripple, that can be seen in the following measurements.

Measurements on the DC-output connector

Specification | Measured

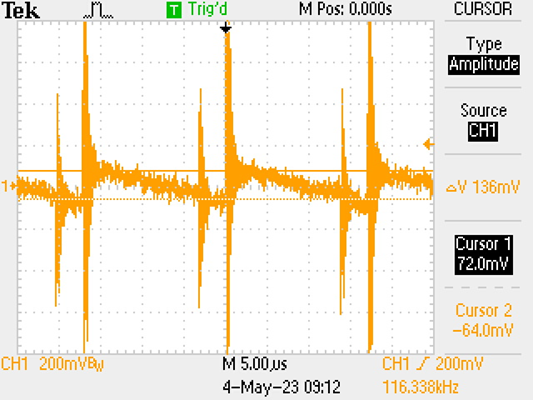
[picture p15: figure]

Output Voltage ripple: <160 mV pk-pk @ full load Mains = 230Vac. Load 10A @ 14.5Vdc. Measured ripple 136mVpp

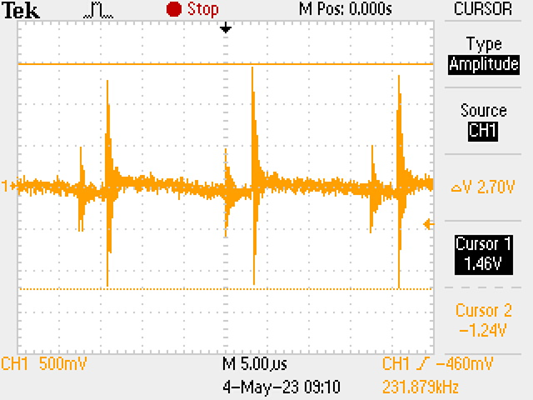
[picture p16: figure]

Output Noise level: <1.5Vpp (30KHz – 300KHz) Mains = 230Vac. Load 10A @ 14.5Vdc. Measured noise 2.7Vpp

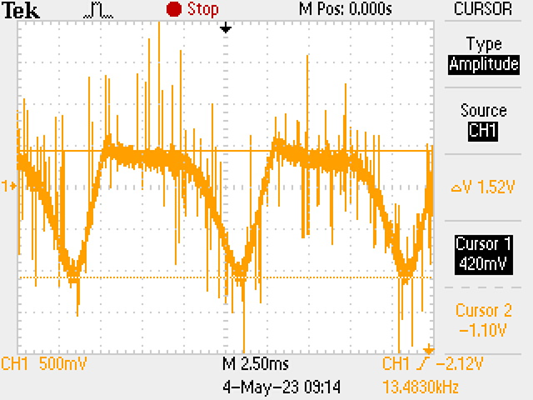
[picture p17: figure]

Output ripple voltage: <1.0% of nominal output voltage Over (10Hz – 100KHz) Mains = 88Vac. Load 10A @ 14.5Vdc. Measured 100Hz ripple, 1.52 Vpp.

Harmonic distortion

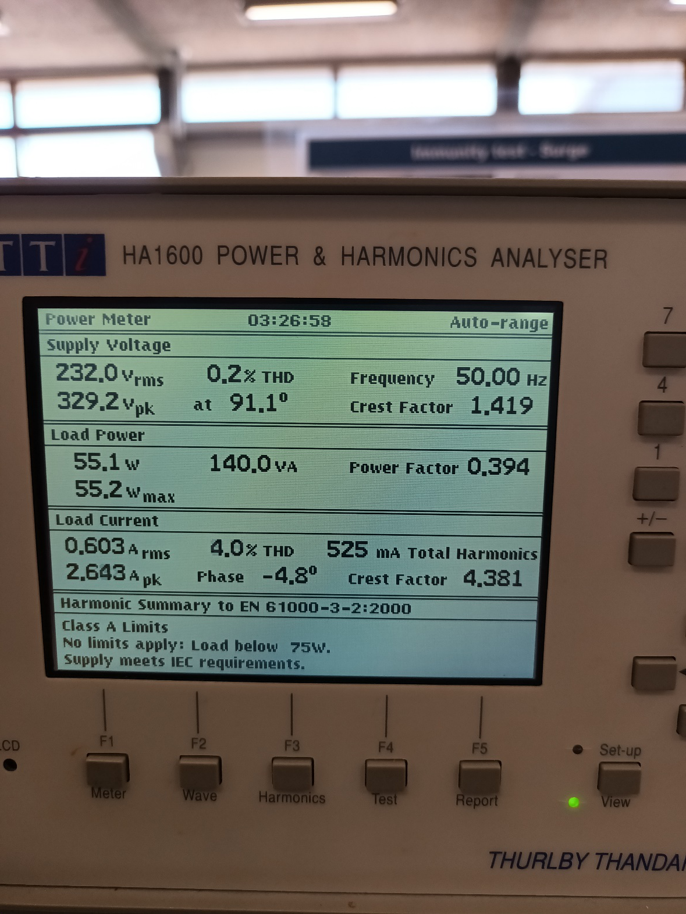
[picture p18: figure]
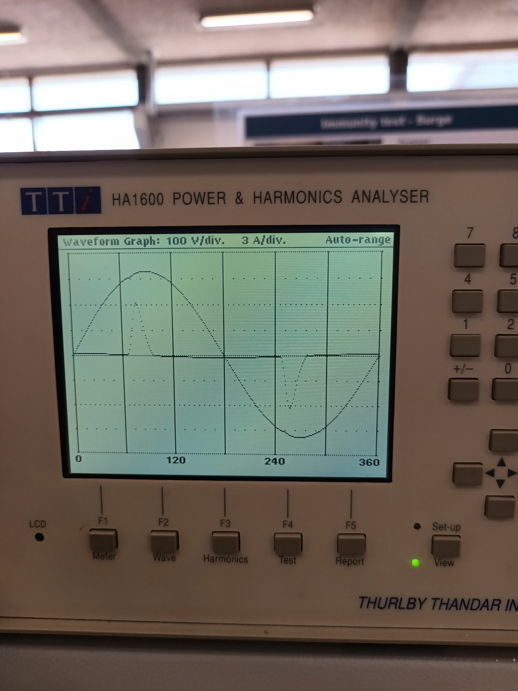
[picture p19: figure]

Voltage and current at 230 Vac

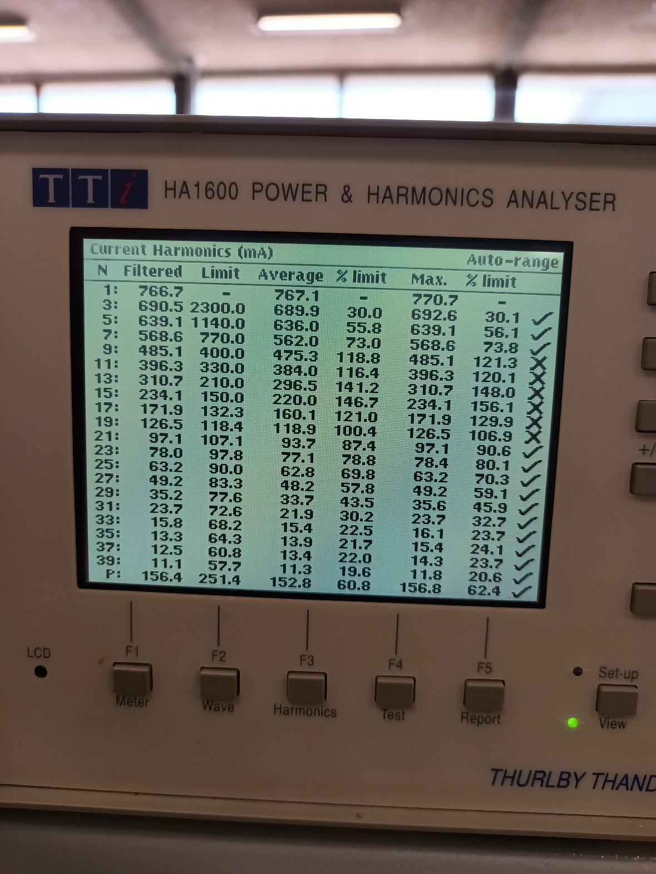
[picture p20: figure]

Table of harmonic distortion

Load 10A @ 14,5Vdc

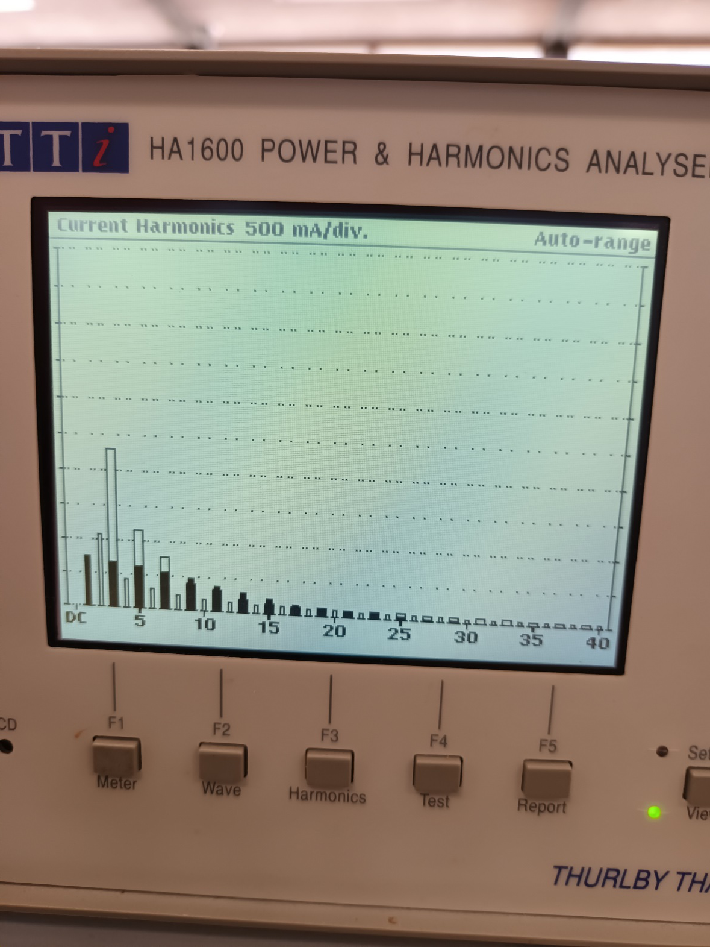
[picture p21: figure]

Harmonic distortion histogram.

Load 10A @ 14,5Vdc

Temperature measurement

During the above measurements, the units appeared to be very warm. For this reason thermal images of EUT 4053 were made. Ambient temperature was 23 deg. C

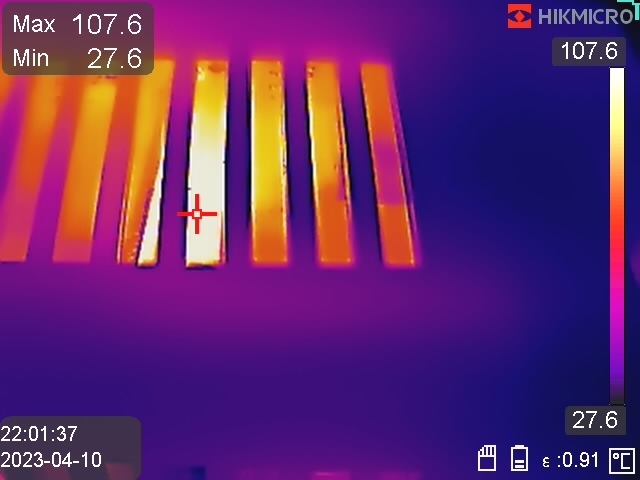
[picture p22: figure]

First measurement with unit in cabinet

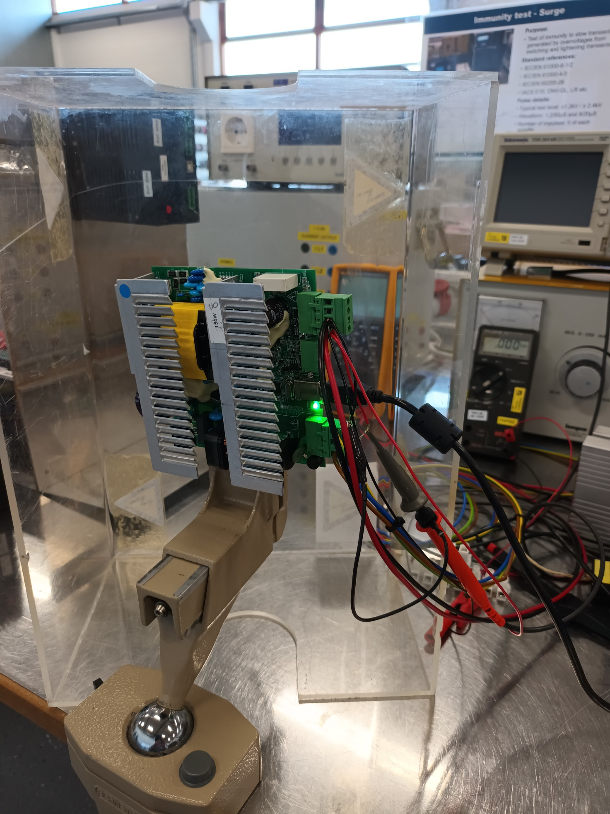
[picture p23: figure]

Tests on open PCB

(It has been noticed the unit is oriented up-side down.)

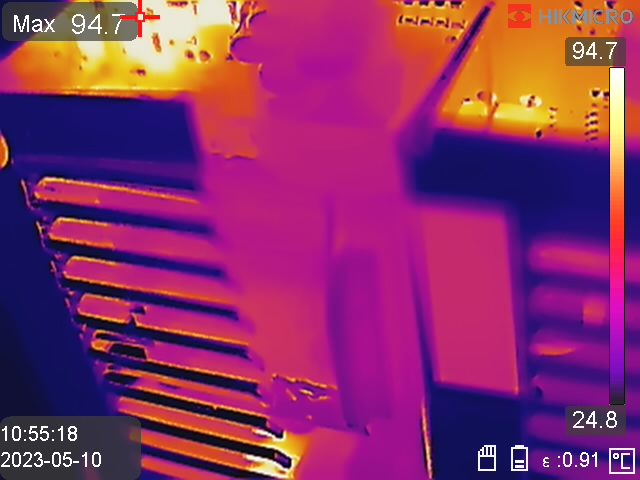
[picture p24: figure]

Hot spot at SMD resistors (primary side snubber and current sensing?)


Rectifier MOSFET


Backside of PCB


Backside of PCB


Inrush PTC


SMD power resistors


Mains rectifier bridge

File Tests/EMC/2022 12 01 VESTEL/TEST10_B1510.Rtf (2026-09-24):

TEST10_B1510

Common Information
Test Description:
Test Site: | SAC3
Test Standard:
Environment Conditions:
Operator Name:
Comment:

Final_Result
Frequency (MHz) | QuasiPeak (dBµV/m) | Limit (dBµV/m) | Margin (dB) | Meas. Time (ms) | Bandwidth (kHz) | Height (cm) | Pol | Azimuth (deg)
Hardware Setup: EMI radiated\SAC3 Radiated Emission 30-6000 MHz - [EMI radiated] Subrange 1
| Frequency Range: | 30 MHz - 6 GHz
| Receiver: | ESW 44 [ESW 44]
| | @ GPIB0 (ADR 20), SN 1328.4100K45/103131, FW 2.10SP2
| Signal Path: | ESR 7-ETS-Lindgren 3142E
| | FW 1.0
| | Correction Table: EMI+ANTENNA_CABLE_30MHz-6GHz_26.08.2022
| Antenna: | ETS-Lindgren 3142E
| | Correction Table (vertical): ETS_LINDGREN_3142E_HORIZONTAL_18.08.2020
| | Correction Table (horizontal): ETS_LINDGREN_3142E_HORIZONTAL_18.08.2020
| Antenna Tower: | EMCO 2090 Antenna Tower [EMCO 2090 Antenna Tower]
| | @ GPIB0 (ADR 8), FW REV 3.21
| Turntable: | EMCO Turntable [EMCO Turntable]
| | @ GPIB0 (ADR 9), FW REV 3.21
EMI Auto Test Template: SAC3 EN 55032 CLASS B 30-1000 MHz TEST
Hardware Setup: | SAC3 Radiated Emission 30-6000 MHz
Measurement Type: | Open-Area-Test-Site
Frequency Range: | 30 MHz - 1 GHz
Graphics Level Range: | 0 dBµV/m - 80 dBµV/m
Preview Measurements:
| Graphics Display: | Show separate traces for horizontal and vertical polarization
| Scan Test Template: | SAC2 TV EN 55022 ITE Equipments Prescan
Adjustment:
| Template for Single Meas.: | SAC2 TV EN 55022 ITE Equipments Final Measurement
Final Measurements:
| Template for Single Meas.: | SAC2 TV EN 55022 ITE Equipments Final Measurement

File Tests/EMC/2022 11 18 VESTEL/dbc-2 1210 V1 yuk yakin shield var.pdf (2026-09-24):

# DBC-2

18.11.2022 13:26:01

1 / 1 - Page 1 of 2

Heading | dbc-2 1210 V1 yuk yakin shield var
Meas Type
Equipment under Test
Manufacturer | enko
OP Condition | p
Operator | g.aktas
Test Spec | J
Settings
Scan Start | 150.000000000 kHz
Scan Stop | 30.000000000 MHz
RBW | 9.0 kHz
IF RBW | 10.0 kHz
Meas Time | 1.0 s
RF Att | 10.0 dB
Preamp State | Off
Preamp Value | 0.0 dB
Input Selection | INP1
Input Coupling | AC
Scan Type | TD Scan
Transducer | ENV432 ENKO.TDF
Scan Table
Scan Start | 150.000000000 kHz
Scan Stop | 30.000000000 MHz
Scan Type | TD Scan
Transducer | ENV432 ENKO.TDF
Detector | Trace 1: Max Peak Trace 2: Average
Start
Frequency

Stop
Frequency
Step Size | RBW | Meas Time | RF Atten | Preamp | Input
150.000 kHz | 30.000 MHz | 2.250 kHz | 9.0 kHz 100.0 ms 10.0 dB 0.0 dB INPUT1
Peak List
Margin | 6.0 dB
Peaks | 25
Trace | Frequency | Level (dBµV) | Phase | Detector | Delta Limit/dB
2 | 10.383000000 MHz | 44.14 | L1 | Average | -5.86
1 | 10.970250000 MHz | 58.01 | L1 Positive Peak | -1.99
Final Results
Meas Time | 1.0 s
Margin | 6.0 dB
Peaks | 25
Trace | Frequency | Level (dBµV) | Phase | Detector | Delta Limit/dB
2 | 10.383000000 MHz | 43.92 | L1 | CISPR AV | -6.08
1 | 10.970250000 MHz | 51.86 | L1 | Quasi Peak | -8.14

18.11.2022 13:26:01
Heading | dbc-2 1210 V1 yuk yakin shield var
Meas Type
Equipment under Test
Manufacturer | enko
OP Condition | p
Operator | g.aktas
Test Spec | J

1 / 1 - Page 2 of 2

Scan Diagram


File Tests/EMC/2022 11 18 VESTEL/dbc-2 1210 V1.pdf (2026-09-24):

# DBC-2

18.11.2022 13:21:24

### 1 / 1 - Page 1 of 2

Heading | dbc-2 1210 V1

## Meas Type Equipment under Test

Manufacturer | enko
OP Condition | p
Operator | g.aktas
Test Spec | J

## Settings

Scan Start | 150.000000000 kHz
Scan Stop | 30.000000000 MHz
RBW | 9.0 kHz
IF RBW | 10.0 kHz
Meas Time | 1.0 s
RF Att | 10.0 dB
Preamp State | Off
Preamp Value | 0.0 dB
Input Selection | INP1
Input Coupling | AC
Scan Type | TD Scan
Transducer | ENV432 ENKO.TDF

## Scan Table

Scan Start | 150.000000000 kHz
Scan Stop | 30.000000000 MHz
Scan Type | TD Scan
Transducer | ENV432 ENKO.TDF
Detector | Trace 1: Max Peak Trace 2: Average
Start
Frequency

Stop
Frequency
Step Size | RBW | Meas Time | RF Atten | Preamp | Input
150.000 kHz | 30.000 MHz | 2.250 kHz | 9.0 kHz 100.0 ms 10.0 dB 0.0 dB INPUT1

## Peak List

Margin | 6.0 dB
Peaks | 25
Trace | Frequency | Level (dBµV) | Phase | Detector | Delta Limit/dB
1 | 9.807000000 MHz | 55.88 | L1 Positive Peak | -4.12
1 | 10.288500000 MHz | 56.28 | L1 Positive Peak | -3.72
2 | 10.320000000 MHz | 44.39 | L1 | Average | -5.61
1 | 10.356000000 MHz | 56.88 | L1 Positive Peak | -3.12
2 | 10.387500000 MHz | 44.36 | L1 | Average | -5.64
1 | 10.698000000 MHz | 57.42 | L1 Positive Peak | -2.58

## Final Results

Meas Time | 1.0 s
Margin | 6.0 dB
Peaks | 25
Trace | Frequency | Level (dBµV) | Phase | Detector | Delta Limit/dB
1 | 9.807000000 MHz | 48.99 | L1 | Quasi Peak | -11.01
1 | 10.288500000 MHz | 50.39 | L1 | Quasi Peak | -9.61
2 | 10.320000000 MHz | 43.87 | L1 | CISPR AV | -6.13
1 | 10.356000000 MHz | 50.33 | L1 | Quasi Peak | -9.67
2 | 10.387500000 MHz | 44.41 | L1 | CISPR AV | -5.59
1 | 10.698000000 MHz | 51.30 | L1 | Quasi Peak | -8.70

18.11.2022 13:21:24
Heading | dbc-2 1210 V1

## Meas Type Equipment under Test

Manufacturer | enko
OP Condition | p
Operator | g.aktas
Test Spec | J

### 1 / 1 - Page 2 of 2

## Scan Diagram


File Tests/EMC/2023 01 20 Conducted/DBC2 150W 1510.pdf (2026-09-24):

# sens

19.01.2023 21:00:15

1 / 1 - Page 1 of 2

Heading | dbc2 150W 1510
Meas Type
Equipment under Test
Manufacturer | enko
OP Condition | p
Operator | g.aktas
Test Spec | J
Settings
Scan Start | 150.000000000 kHz
Scan Stop | 30.000000000 MHz
RBW | 9.0 kHz
IF RBW | 10.0 kHz
Meas Time | 1.0 s
RF Att | 10.0 dB
Preamp State | Off
Preamp Value | 0.0 dB
Input Selection | INP1
Input Coupling | AC
Scan Type | TD Scan
Transducer | ENV432 ENKO.TDF
Scan Table
Scan Start | 150.000000000 kHz
Scan Stop | 30.000000000 MHz
Scan Type | TD Scan
Transducer | ENV432 ENKO.TDF
Detector | Trace 1: Max Peak Trace 2: Average
Start
Frequency

Stop
Frequency
Step Size | RBW | Meas Time | RF Atten | Preamp | Input
150.000 kHz | 30.000 MHz | 2.250 kHz | 9.0 kHz | 10.0 ms 10.0 dB 0.0 dB INPUT1
Peak List
Margin | 6.0 dB
Peaks | 25
Trace | Frequency | Level (dBµV) | Phase | Detector | Delta Limit/dB
1 174.750000000 kHz | 60.47 | N Positive Peak | -4.26
2 177.000000000 kHz | 50.23 | N | Average | -4.40
1 | 8.020500000 MHz | 54.55 | N Positive Peak | -5.45
Final Results
Meas Time | 1.0 s
Margin | 6.0 dB
Peaks | 25
Trace | Frequency | Level (dBµV) | Phase | Detector | Delta Limit/dB
1 174.750000000 kHz | 58.93 | N | Quasi Peak | -5.80
2 177.000000000 kHz | 46.80 | N | CISPR AV | -7.83
1 | 8.020500000 MHz | 46.70 | N | Quasi Peak | -13.30

19.01.2023 21:00:15
Heading | dbc2 150W 1510
Meas Type
Equipment under Test
Manufacturer | enko
OP Condition | p
Operator | g.aktas
Test Spec | J

1 / 1 - Page 2 of 2

Scan Diagram


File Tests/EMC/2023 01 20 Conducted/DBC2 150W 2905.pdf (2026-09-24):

# sens

19.01.2023 20:55:51

1 / 1 - Page 1 of 2

Heading | dbc2 150W 2905
Meas Type
Equipment under Test
Manufacturer | enko
OP Condition | p
Operator | g.aktas
Test Spec | J
Settings
Scan Start | 150.000000000 kHz
Scan Stop | 30.000000000 MHz
RBW | 9.0 kHz
IF RBW | 10.0 kHz
Meas Time | 1.0 s
RF Att | 10.0 dB
Preamp State | Off
Preamp Value | 0.0 dB
Input Selection | INP1
Input Coupling | AC
Scan Type | TD Scan
Transducer | ENV432 ENKO.TDF
Scan Table
Scan Start | 150.000000000 kHz
Scan Stop | 30.000000000 MHz
Scan Type | TD Scan
Transducer | ENV432 ENKO.TDF
Detector | Trace 1: Max Peak Trace 2: Average
Start
Frequency

Stop
Frequency
Step Size | RBW | Meas Time | RF Atten | Preamp | Input
150.000 kHz | 30.000 MHz | 2.250 kHz | 9.0 kHz | 10.0 ms 10.0 dB 0.0 dB INPUT1
Peak List
Margin | 6.0 dB
Peaks | 25
Trace | Frequency | Level (dBµV) | Phase | Detector | Delta Limit/dB
1 161.250000000 kHz | 60.32 | L1 Positive Peak | -5.08
2 163.500000000 kHz | 50.37 | L1 | Average | -4.91
2 | 1.214250000 MHz | 41.72 | L1 | Average | -4.28
Final Results
Meas Time | 1.0 s
Margin | 6.0 dB
Peaks | 25
Trace | Frequency | Level (dBµV) | Phase | Detector | Delta Limit/dB
1 161.250000000 kHz | 59.39 | N | Quasi Peak | -6.01
2 163.500000000 kHz | 48.53 | N | CISPR AV | -6.75
2 | 1.214250000 MHz | 40.94 | L1 | CISPR AV | -5.06

19.01.2023 20:55:51
Heading | dbc2 150W 2905
Meas Type
Equipment under Test
Manufacturer | enko
OP Condition | p
Operator | g.aktas
Test Spec | J

1 / 1 - Page 2 of 2

Scan Diagram


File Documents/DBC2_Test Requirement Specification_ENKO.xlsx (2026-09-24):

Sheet: TESTLER
1- | TEST1 sayfasındaki koşullar oluşturularak test yapılır. Sonuçlar bu sayfaya kayıt edilir.
2- | PC arayüzden min.12V ve maksimum 30V değerine set edilebilir olmalıdır. Kontrol edilir.
3- | Output reverse polarity protection test (TEST3)
4- | Akım harmonikleri ölçümü TEST4
4- | Cold start test
5- | Max. ambient temperature test on maximum output power (thermal kamera ile test, thermocouple ile test)
6- | Leakage Current. Leakage current için devre eş değer şeması çizilir. Leakage akım hesaplanır. 220VAC ve 264VAc için ölçülür.
 | Humidity test
 | Output power derating test
 | Alarm conditions and alarm relay test
 | Battery temperature measurement tests
 | Boost charge test
 | Parallel connection test
 | Vibration
 | Sparking (Cihaz enerjisiz ve çıkış kondansatörleri boşalmışken akü bağlantısı yapılır bu sırada ark oluşmamalıdır.)
 | In-rush current value (Cihaz enerjisiz ve çıkış kondansötörleri boşalmışken çıkış tam yük ve boş durumları için akım akım probu ile osiloskopta giriş akımı ölçülür.)
 | Input-output Hi-Pot test (with terminals shorted)
 | Input-Earth isolation test
 | Output-Earth isolation test
 | Case-Earth ESD test, 8kV max. (not applicable with 3D enclosure)
 | EMC test:
 | Input current harmonics level measurement
 | Conducted EMC
 | Radiated EMC
 | Burst-surge test (to be tested at final stage)
 | Noise immunity test
 | Failure Mode Analysis
 | Load Dump Test
 |  | 7-

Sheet: TEST1
INPUT |  |  |  |  | OUTPUT |  |  |  | Verim | Ripple | Start-up | Start-up with 10x10.000uF
Vin (VAC) |  | Fr (Hz) |  | Pin (watt) | Vout(DC) |  | Iout(A) |  | Çıkış Gücü/Giriş Gücü | Çıkışta sadece direnç yükü varken ölçüm yapılır. | Beliritlen koşulda giriş gerilimini kes ve ver. Problemsiz olarak çıkış geriliminin yada akımının oluştuğunu gör. | Beliritlen koşulda giriş gerilimini kes ve ver. Problemsiz olarak çıkış geriliminin yada akımının oluştuğunu gör.
İstenen | Ölçülen | İstenen | Ölçülen |  | İstenen | Ölçülen | İstenen | Ölçülen | % | mVDC
85VAC |  | 60Hz |  |  | 12VDC |  | NO LOAD
85VAC |  | 60Hz |  |  | 12VDC |  | 0,5A
85VAC |  | 60Hz |  |  | 12VDC |  | 5A
85VAC |  | 60Hz |  |  | 12VDC |  | 9A
85VAC |  | 60Hz |  |  | 12VDC |  | 10A
85VAC |  | 60Hz |  |  | 12VDC |  | SHORT
85VAC |  | 60Hz |  |  | 13,8VDC |  | NO LOAD
85VAC |  | 60Hz |  |  | 13,8VDC |  | 0,5A
85VAC |  | 60Hz |  |  | 13,8VDC |  | 5A
85VAC |  | 60Hz |  |  | 13,8VDC |  | 9A
85VAC |  | 60Hz |  |  | 13,8VDC |  | 10A
85VAC |  | 60Hz |  |  | 13,8VDC |  | SHORT
85VAC |  | 60Hz |  |  | 15VDC |  | NO LOAD
85VAC |  | 60Hz |  |  | 15VDC |  | 0,5A
85VAC |  | 60Hz |  |  | 15VDC |  | 5A
85VAC |  | 60Hz |  |  | 15VDC |  | 9A
85VAC |  | 60Hz |  |  | 15VDC |  | 10A
85VAC |  | 60Hz |  |  | 15VDC |  | SHORT
85VAC |  | 60Hz |  |  | 24VDC |  | NO LOAD
85VAC |  | 60Hz |  |  | 24VDC |  | 0,5A
85VAC |  | 60Hz |  |  | 24VDC |  | 5A
85VAC |  | 60Hz |  |  | 24VDC |  | 9A
85VAC |  | 60Hz |  |  | 24VDC |  | 10A
85VAC |  | 60Hz |  |  | 24VDC |  | SHORT
85VAC |  | 60Hz |  |  | 27,6VDC |  | NO LOAD
85VAC |  | 60Hz |  |  | 27,6VDC |  | 0,5A
85VAC |  | 60Hz |  |  | 27,6VDC |  | 5A
85VAC |  | 60Hz |  |  | 27,6VDC |  | 9A
85VAC |  | 60Hz |  |  | 27,6VDC |  | 10A
85VAC |  | 60Hz |  |  | 27,6VDC |  | SHORT
85VAC |  | 60Hz |  |  | 30VDC |  | NO LOAD
85VAC |  | 60Hz |  |  | 30VDC |  | 0,5A
85VAC |  | 60Hz |  |  | 30VDC |  | 5A
85VAC |  | 60Hz |  |  | 30VDC |  | 9A
85VAC |  | 60Hz |  |  | 30VDC |  | 10A
85VAC |  | 60Hz |  |  | 30VDC |  | SHORT
110VAC |  | 60Hz |  |  | 12VDC |  | NO LOAD
110VAC |  | 60Hz |  |  | 12VDC |  | 0,5A
110VAC |  | 60Hz |  |  | 12VDC |  | 5A
110VAC |  | 60Hz |  |  | 12VDC |  | 9A
110VAC |  | 60Hz |  |  | 12VDC |  | 10A
110VAC |  | 60Hz |  |  | 12VDC |  | SHORT
110VAC |  | 60Hz |  |  | 13,8VDC |  | NO LOAD
110VAC |  | 60Hz |  |  | 13,8VDC |  | 0,5A
110VAC |  | 60Hz |  |  | 13,8VDC |  | 5A
110VAC |  | 60Hz |  |  | 13,8VDC |  | 9A
110VAC |  | 60Hz |  |  | 13,8VDC |  | 10A
110VAC |  | 60Hz |  |  | 13,8VDC |  | SHORT
110VAC |  | 60Hz |  |  | 15VDC |  | NO LOAD
110VAC |  | 60Hz |  |  | 15VDC |  | 0,5A
110VAC |  | 60Hz |  |  | 15VDC |  | 5A
110VAC |  | 60Hz |  |  | 15VDC |  | 9A
110VAC |  | 60Hz |  |  | 15VDC |  | 10A
110VAC |  | 60Hz |  |  | 15VDC |  | SHORT
110VAC |  | 60Hz |  |  | 24VDC |  | NO LOAD
110VAC |  | 60Hz |  |  | 24VDC |  | 0,5A
110VAC |  | 60Hz |  |  | 24VDC |  | 5A
110VAC |  | 60Hz |  |  | 24VDC |  | 9A
110VAC |  | 60Hz |  |  | 24VDC |  | 10A
110VAC |  | 60Hz |  |  | 24VDC |  | SHORT
110VAC |  | 60Hz |  |  | 27,6VDC |  | NO LOAD
110VAC |  | 60Hz |  |  | 27,6VDC |  | 0,5A
110VAC |  | 60Hz |  |  | 27,6VDC |  | 5A
110VAC |  | 60Hz |  |  | 27,6VDC |  | 9A
110VAC |  | 60Hz |  |  | 27,6VDC |  | 10A
110VAC |  | 60Hz |  |  | 27,6VDC |  | SHORT
110VAC |  | 60Hz |  |  | 30VDC |  | NO LOAD
110VAC |  | 60Hz |  |  | 30VDC |  | 0,5A
110VAC |  | 60Hz |  |  | 30VDC |  | 5A
110VAC |  | 60Hz |  |  | 30VDC |  | 9A
110VAC |  | 60Hz |  |  | 30VDC |  | 10A
110VAC |  | 60Hz |  |  | 30VDC |  | SHORT
220VAC |  | 50Hz |  |  | 12VDC |  | NO LOAD
220VAC |  | 50Hz |  |  | 12VDC |  | 0,5A
220VAC |  | 50Hz |  |  | 12VDC |  | 5A
220VAC |  | 50Hz |  |  | 12VDC |  | 9A
220VAC |  | 50Hz |  |  | 12VDC |  | 10A
220VAC |  | 50Hz |  |  | 12VDC |  | SHORT
220VAC |  | 50Hz |  |  | 13,8VDC |  | NO LOAD
220VAC |  | 50Hz |  |  | 13,8VDC |  | 0,5A
220VAC |  | 50Hz |  |  | 13,8VDC |  | 5A
220VAC |  | 50Hz |  |  | 13,8VDC |  | 9A
220VAC |  | 50Hz |  |  | 13,8VDC |  | 10A
220VAC |  | 50Hz |  |  | 13,8VDC |  | SHORT
220VAC |  | 50Hz |  |  | 15VDC |  | NO LOAD
220VAC |  | 50Hz |  |  | 15VDC |  | 0,5A
220VAC |  | 50Hz |  |  | 15VDC |  | 5A
220VAC |  | 50Hz |  |  | 15VDC |  | 9A
220VAC |  | 50Hz |  |  | 15VDC |  | 10A
220VAC |  | 50Hz |  |  | 15VDC |  | SHORT
220VAC |  | 50Hz |  |  | 24VDC |  | NO LOAD
220VAC |  | 50Hz |  |  | 24VDC |  | 0,5A
220VAC |  | 50Hz |  |  | 24VDC |  | 5A
220VAC |  | 50Hz |  |  | 24VDC |  | 9A
220VAC |  | 50Hz |  |  | 24VDC |  | 10A
220VAC |  | 50Hz |  |  | 24VDC |  | SHORT
220VAC |  | 50Hz |  |  | 27,6VDC |  | NO LOAD
220VAC |  | 50Hz |  |  | 27,6VDC |  | 0,5A
220VAC |  | 50Hz |  |  | 27,6VDC |  | 5A
220VAC |  | 50Hz |  |  | 27,6VDC |  | 9A
220VAC |  | 50Hz |  |  | 27,6VDC |  | 10A
220VAC |  | 50Hz |  |  | 27,6VDC |  | SHORT
220VAC |  | 50Hz |  |  | 30VDC |  | NO LOAD
220VAC |  | 50Hz |  |  | 30VDC |  | 0,5A
220VAC |  | 50Hz |  |  | 30VDC |  | 5A
220VAC |  | 50Hz |  |  | 30VDC |  | 9A
220VAC |  | 50Hz |  |  | 30VDC |  | 10A
220VAC |  | 50Hz |  |  | 30VDC |  | SHORT
264VAC |  | 50Hz |  |  | 12VDC |  | NO LOAD
264VAC |  | 50Hz |  |  | 12VDC |  | 0,5A
264VAC |  | 50Hz |  |  | 12VDC |  | 5A
264VAC |  | 50Hz |  |  | 12VDC |  | 9A
264VAC |  | 50Hz |  |  | 12VDC |  | 10A
264VAC |  | 50Hz |  |  | 12VDC |  | SHORT
264VAC |  | 50Hz |  |  | 13,8VDC |  | NO LOAD
264VAC |  | 50Hz |  |  | 13,8VDC |  | 0,5A
264VAC |  | 50Hz |  |  | 13,8VDC |  | 5A
264VAC |  | 50Hz |  |  | 13,8VDC |  | 9A
264VAC |  | 50Hz |  |  | 13,8VDC |  | 10A
264VAC |  | 50Hz |  |  | 13,8VDC |  | SHORT
264VAC |  | 50Hz |  |  | 15VDC |  | NO LOAD
264VAC |  | 50Hz |  |  | 15VDC |  | 0,5A
264VAC |  | 50Hz |  |  | 15VDC |  | 5A
264VAC |  | 50Hz |  |  | 15VDC |  | 9A
264VAC |  | 50Hz |  |  | 15VDC |  | 10A
264VAC |  | 50Hz |  |  | 15VDC |  | SHORT
264VAC |  | 50Hz |  |  | 24VDC |  | NO LOAD
264VAC |  | 50Hz |  |  | 24VDC |  | 0,5A
264VAC |  | 50Hz |  |  | 24VDC |  | 5A
264VAC |  | 50Hz |  |  | 24VDC |  | 9A
264VAC |  | 50Hz |  |  | 24VDC |  | 10A
264VAC |  | 50Hz |  |  | 24VDC |  | SHORT
264VAC |  | 50Hz |  |  | 27,6VDC |  | NO LOAD
264VAC |  | 50Hz |  |  | 27,6VDC |  | 0,5A
264VAC |  | 50Hz |  |  | 27,6VDC |  | 5A
264VAC |  | 50Hz |  |  | 27,6VDC |  | 9A
264VAC |  | 50Hz |  |  | 27,6VDC |  | 10A
264VAC |  | 50Hz |  |  | 27,6VDC |  | SHORT
264VAC |  | 50Hz |  |  | 30VDC |  | NO LOAD
264VAC |  | 50Hz |  |  | 30VDC |  | 0,5A
264VAC |  | 50Hz |  |  | 30VDC |  | 5A
264VAC |  | 50Hz |  |  | 30VDC |  | 9A
264VAC |  | 50Hz |  |  | 30VDC |  | 10A
264VAC |  | 50Hz |  |  | 30VDC |  | SHORT
300VAC |  | 50Hz |  |  | 12VDC |  | NO LOAD
300VAC |  | 50Hz |  |  | 12VDC |  | 0,5A
300VAC |  | 50Hz |  |  | 12VDC |  | 5A
300VAC |  | 50Hz |  |  | 12VDC |  | 9A
300VAC |  | 50Hz |  |  | 12VDC |  | 10A
300VAC |  | 50Hz |  |  | 12VDC |  | SHORT
300VAC |  | 50Hz |  |  | 13,8VDC |  | NO LOAD
300VAC |  | 50Hz |  |  | 13,8VDC |  | 0,5A
300VAC |  | 50Hz |  |  | 13,8VDC |  | 5A
300VAC |  | 50Hz |  |  | 13,8VDC |  | 9A
300VAC |  | 50Hz |  |  | 13,8VDC |  | 10A
300VAC |  | 50Hz |  |  | 13,8VDC |  | SHORT
300VAC |  | 50Hz |  |  | 15VDC |  | NO LOAD
300VAC |  | 50Hz |  |  | 15VDC |  | 0,5A
300VAC |  | 50Hz |  |  | 15VDC |  | 5A
300VAC |  | 50Hz |  |  | 15VDC |  | 9A
300VAC |  | 50Hz |  |  | 15VDC |  | 10A
300VAC |  | 50Hz |  |  | 15VDC |  | SHORT
300VAC |  | 50Hz |  |  | 24VDC |  | NO LOAD
300VAC |  | 50Hz |  |  | 24VDC |  | 0,5A
300VAC |  | 50Hz |  |  | 24VDC |  | 5A
300VAC |  | 50Hz |  |  | 24VDC |  | 9A
300VAC |  | 50Hz |  |  | 24VDC |  | 10A
300VAC |  | 50Hz |  |  | 24VDC |  | SHORT
300VAC |  | 50Hz |  |  | 27,6VDC |  | NO LOAD
300VAC |  | 50Hz |  |  | 27,6VDC |  | 0,5A
300VAC |  | 50Hz |  |  | 27,6VDC |  | 5A
300VAC |  | 50Hz |  |  | 27,6VDC |  | 9A
300VAC |  | 50Hz |  |  | 27,6VDC |  | 10A
300VAC |  | 50Hz |  |  | 27,6VDC |  | SHORT
300VAC |  | 50Hz |  |  | 30VDC |  | NO LOAD
300VAC |  | 50Hz |  |  | 30VDC |  | 0,5A
300VAC |  | 50Hz |  |  | 30VDC |  | 5A
300VAC |  | 50Hz |  |  | 30VDC |  | 9A
300VAC |  | 50Hz |  |  | 30VDC |  | 10A
300VAC |  | 50Hz |  |  | 30VDC |  | SHORT

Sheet: TEST3
INPUT |  |  |  | OUTPUT |  |  | Çıkışa ters olarak bağlanacak akü şarj durumu | Çıkışa ters olarak bağlanacak akü nominal gerilimi
Vin (VAC) |  | Fr (Hz) |  | Vout(DC) |  | Iout(A)
İstenen | Ölçülen | İstenen | Ölçülen | İstenen | Ölçülen | İstenen |  | İstenen | Ölçülen
110VAC |  | 50Hz |  | 12VDC |  | NO LOAD | Boş yada boşa yakın | 12VDC
110VAC |  | 50Hz |  | 12VDC |  | NO LOAD | Tam şarjlı | 24VDC
110VAC |  | 50Hz |  | 13,8VDC |  | NO LOAD | Boş yada boşa yakın | 12VDC
110VAC |  | 50Hz |  | 13,8VDC |  | NO LOAD | Tam şarjlı | 24VDC
110VAC |  | 50Hz |  | 15VDC |  | NO LOAD | Boş yada boşa yakın | 12VDC
110VAC |  | 50Hz |  | 15VDC |  | NO LOAD | Tam şarjlı | 24VDC
110VAC |  | 50Hz |  | 24VDC |  | NO LOAD | Boş yada boşa yakın | 12VDC
110VAC |  | 50Hz |  | 24VDC |  | NO LOAD | Tam şarjlı | 24VDC
110VAC |  | 50Hz |  | 27,6VDC |  | NO LOAD | Boş yada boşa yakın | 12VDC
110VAC |  | 50Hz |  | 27,6VDC |  | NO LOAD | Tam şarjlı | 24VDC
110VAC |  | 50Hz |  | 30VDC |  | NO LOAD | Boş yada boşa yakın | 12VDC
110VAC |  | 50Hz |  | 30VDC |  | NO LOAD | Tam şarjlı | 24VDC
220VAC |  | 50Hz |  | 12VDC |  | NO LOAD | Boş yada boşa yakın | 12VDC
220VAC |  | 50Hz |  | 12VDC |  | NO LOAD | Tam şarjlı | 24VDC
220VAC |  | 50Hz |  | 13,8VDC |  | NO LOAD | Boş yada boşa yakın | 12VDC
220VAC |  | 50Hz |  | 13,8VDC |  | NO LOAD | Tam şarjlı | 24VDC
220VAC |  | 50Hz |  | 15VDC |  | NO LOAD | Boş yada boşa yakın | 12VDC
220VAC |  | 50Hz |  | 15VDC |  | NO LOAD | Tam şarjlı | 24VDC
220VAC |  | 50Hz |  | 24VDC |  | NO LOAD | Boş yada boşa yakın | 12VDC
220VAC |  | 50Hz |  | 24VDC |  | NO LOAD | Tam şarjlı | 24VDC
220VAC |  | 50Hz |  | 27,6VDC |  | NO LOAD | Boş yada boşa yakın | 12VDC
220VAC |  | 50Hz |  | 27,6VDC |  | NO LOAD | Tam şarjlı | 24VDC
220VAC |  | 50Hz |  | 30VDC |  | NO LOAD | Boş yada boşa yakın | 12VDC
220VAC |  | 50Hz |  | 30VDC |  | NO LOAD | Tam şarjlı | 24VDC
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

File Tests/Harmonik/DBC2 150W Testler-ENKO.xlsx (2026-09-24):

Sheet: TESTLER
1- | TEST1 sayfasındaki koşullar oluşturularak test yapılır. Sonuçlar bu sayfaya kayıt edilir.
2- | PC arayüzden min.12V ve maksimum 30V değerine set edilebilir olmalıdır. Kontrol edilir.
3- | Output reverse polarity protection test (TEST3)
4- | Akım harmonikleri ölçümü TEST4
4- | Cold start test
5- | Max. ambient temperature test on maximum output power (thermal kamera ile test, thermocouple ile test)
6- | Leakage Current. Leakage current için devre eş değer şeması çizilir. Leakage akım hesaplanır. 220VAC ve 264VAc için ölçülür.
 | Humidity test
 | Output power derating test
 | Alarm conditions and alarm relay test
 | Battery temperature measurement tests
 | Boost charge test
 | Parallel connection test
 | Vibration
 | Sparking (Cihaz enerjisiz ve çıkış kondansatörleri boşalmışken akü bağlantısı yapılır bu sırada ark oluşmamalıdır.)
 | In-rush current value (Cihaz enerjisiz ve çıkış kondansötörleri boşalmışken çıkış tam yük ve boş durumları için akım akım probu ile osiloskopta giriş akımı ölçülür.)
 | Input-output Hi-Pot test (with terminals shorted)
 | Input-Earth isolation test
 | Output-Earth isolation test
 | Case-Earth ESD test, 8kV max. (not applicable with 3D enclosure)
 | EMC test:
 | Input current harmonics level measurement
 | Conducted EMC
 | Radiated EMC
 | Burst-surge test (to be tested at final stage)
 | Noise immunity test
 | Failure Mode Analysis
 | Load Dump Test
 |  | 7-

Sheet: TEST1
INPUT |  |  |  |  | OUTPUT |  |  |  | Verim | Ripple | Start-up | Start-up with 10x10.000uF
Vin (VAC) |  | Fr (Hz) |  | Pin (watt) | Vout(DC) |  | Iout(A) |  | Çıkış Gücü/Giriş Gücü | Çıkışta sadece direnç yükü varken ölçüm yapılır. | Beliritlen koşulda giriş gerilimini kes ve ver. Problemsiz olarak çıkış geriliminin yada akımının oluştuğunu gör. | Beliritlen koşulda giriş gerilimini kes ve ver. Problemsiz olarak çıkış geriliminin yada akımının oluştuğunu gör.
İstenen | Ölçülen | İstenen | Ölçülen |  | İstenen | Ölçülen | İstenen | Ölçülen | % | mVDC
85VAC |  | 60Hz |  |  | 12VDC |  | NO LOAD
85VAC |  | 60Hz |  |  | 12VDC |  | 0,5A
85VAC |  | 60Hz |  |  | 12VDC |  | 5A
85VAC |  | 60Hz |  |  | 12VDC |  | 9A
85VAC |  | 60Hz |  |  | 12VDC |  | 10A
85VAC |  | 60Hz |  |  | 12VDC |  | SHORT
85VAC |  | 60Hz |  |  | 13,8VDC |  | NO LOAD
85VAC |  | 60Hz |  |  | 13,8VDC |  | 0,5A
85VAC |  | 60Hz |  |  | 13,8VDC |  | 5A
85VAC |  | 60Hz |  |  | 13,8VDC |  | 9A
85VAC |  | 60Hz |  |  | 13,8VDC |  | 10A
85VAC |  | 60Hz |  |  | 13,8VDC |  | SHORT
85VAC |  | 60Hz |  |  | 15VDC |  | NO LOAD
85VAC |  | 60Hz |  |  | 15VDC |  | 0,5A
85VAC |  | 60Hz |  |  | 15VDC |  | 5A
85VAC |  | 60Hz |  |  | 15VDC |  | 9A
85VAC |  | 60Hz |  |  | 15VDC |  | 10A
85VAC |  | 60Hz |  |  | 15VDC |  | SHORT
85VAC |  | 60Hz |  |  | 24VDC |  | NO LOAD
85VAC |  | 60Hz |  |  | 24VDC |  | 0,5A
85VAC |  | 60Hz |  |  | 24VDC |  | 5A
85VAC |  | 60Hz |  |  | 24VDC |  | 9A
85VAC |  | 60Hz |  |  | 24VDC |  | 10A
85VAC |  | 60Hz |  |  | 24VDC |  | SHORT
85VAC |  | 60Hz |  |  | 27,6VDC |  | NO LOAD
85VAC |  | 60Hz |  |  | 27,6VDC |  | 0,5A
85VAC |  | 60Hz |  |  | 27,6VDC |  | 5A
85VAC |  | 60Hz |  |  | 27,6VDC |  | 9A
85VAC |  | 60Hz |  |  | 27,6VDC |  | 10A
85VAC |  | 60Hz |  |  | 27,6VDC |  | SHORT
85VAC |  | 60Hz |  |  | 30VDC |  | NO LOAD
85VAC |  | 60Hz |  |  | 30VDC |  | 0,5A
85VAC |  | 60Hz |  |  | 30VDC |  | 5A
85VAC |  | 60Hz |  |  | 30VDC |  | 9A
85VAC |  | 60Hz |  |  | 30VDC |  | 10A
85VAC |  | 60Hz |  |  | 30VDC |  | SHORT
110VAC |  | 60Hz |  |  | 12VDC |  | NO LOAD
110VAC |  | 60Hz |  |  | 12VDC |  | 0,5A
110VAC |  | 60Hz |  |  | 12VDC |  | 5A
110VAC |  | 60Hz |  |  | 12VDC |  | 9A
110VAC |  | 60Hz |  |  | 12VDC |  | 10A
110VAC |  | 60Hz |  |  | 12VDC |  | SHORT
110VAC |  | 60Hz |  |  | 13,8VDC |  | NO LOAD
110VAC |  | 60Hz |  |  | 13,8VDC |  | 0,5A
110VAC |  | 60Hz |  |  | 13,8VDC |  | 5A
110VAC |  | 60Hz |  |  | 13,8VDC |  | 9A
110VAC |  | 60Hz |  |  | 13,8VDC |  | 10A
110VAC |  | 60Hz |  |  | 13,8VDC |  | SHORT
110VAC |  | 60Hz |  |  | 15VDC |  | NO LOAD
110VAC |  | 60Hz |  |  | 15VDC |  | 0,5A
110VAC |  | 60Hz |  |  | 15VDC |  | 5A
110VAC |  | 60Hz |  |  | 15VDC |  | 9A
110VAC |  | 60Hz |  |  | 15VDC |  | 10A
110VAC |  | 60Hz |  |  | 15VDC |  | SHORT
110VAC |  | 60Hz |  |  | 24VDC |  | NO LOAD
110VAC |  | 60Hz |  |  | 24VDC |  | 0,5A
110VAC |  | 60Hz |  |  | 24VDC |  | 5A
110VAC |  | 60Hz |  |  | 24VDC |  | 9A
110VAC |  | 60Hz |  |  | 24VDC |  | 10A
110VAC |  | 60Hz |  |  | 24VDC |  | SHORT
110VAC |  | 60Hz |  |  | 27,6VDC |  | NO LOAD
110VAC |  | 60Hz |  |  | 27,6VDC |  | 0,5A
110VAC |  | 60Hz |  |  | 27,6VDC |  | 5A
110VAC |  | 60Hz |  |  | 27,6VDC |  | 9A
110VAC |  | 60Hz |  |  | 27,6VDC |  | 10A
110VAC |  | 60Hz |  |  | 27,6VDC |  | SHORT
110VAC |  | 60Hz |  |  | 30VDC |  | NO LOAD
110VAC |  | 60Hz |  |  | 30VDC |  | 0,5A
110VAC |  | 60Hz |  |  | 30VDC |  | 5A
110VAC |  | 60Hz |  |  | 30VDC |  | 9A
110VAC |  | 60Hz |  |  | 30VDC |  | 10A
110VAC |  | 60Hz |  |  | 30VDC |  | SHORT
220VAC |  | 50Hz |  |  | 12VDC |  | NO LOAD
220VAC |  | 50Hz |  |  | 12VDC |  | 0,5A
220VAC |  | 50Hz |  |  | 12VDC |  | 5A
220VAC |  | 50Hz |  |  | 12VDC |  | 9A
220VAC |  | 50Hz |  |  | 12VDC |  | 10A
220VAC |  | 50Hz |  |  | 12VDC |  | SHORT
220VAC |  | 50Hz |  |  | 13,8VDC |  | NO LOAD
220VAC |  | 50Hz |  |  | 13,8VDC |  | 0,5A
220VAC |  | 50Hz |  |  | 13,8VDC |  | 5A
220VAC |  | 50Hz |  |  | 13,8VDC |  | 9A
220VAC |  | 50Hz |  |  | 13,8VDC |  | 10A
220VAC |  | 50Hz |  |  | 13,8VDC |  | SHORT
220VAC |  | 50Hz |  |  | 15VDC |  | NO LOAD
220VAC |  | 50Hz |  |  | 15VDC |  | 0,5A
220VAC |  | 50Hz |  |  | 15VDC |  | 5A
220VAC |  | 50Hz |  |  | 15VDC |  | 9A
220VAC |  | 50Hz |  |  | 15VDC |  | 10A
220VAC |  | 50Hz |  |  | 15VDC |  | SHORT
220VAC |  | 50Hz |  |  | 24VDC |  | NO LOAD
220VAC |  | 50Hz |  |  | 24VDC |  | 0,5A
220VAC |  | 50Hz |  |  | 24VDC |  | 5A
220VAC |  | 50Hz |  |  | 24VDC |  | 9A
220VAC |  | 50Hz |  |  | 24VDC |  | 10A
220VAC |  | 50Hz |  |  | 24VDC |  | SHORT
220VAC |  | 50Hz |  |  | 27,6VDC |  | NO LOAD
220VAC |  | 50Hz |  |  | 27,6VDC |  | 0,5A
220VAC |  | 50Hz |  |  | 27,6VDC |  | 5A
220VAC |  | 50Hz |  |  | 27,6VDC |  | 9A
220VAC |  | 50Hz |  |  | 27,6VDC |  | 10A
220VAC |  | 50Hz |  |  | 27,6VDC |  | SHORT
220VAC |  | 50Hz |  |  | 30VDC |  | NO LOAD
220VAC |  | 50Hz |  |  | 30VDC |  | 0,5A
220VAC |  | 50Hz |  |  | 30VDC |  | 5A
220VAC |  | 50Hz |  |  | 30VDC |  | 9A
220VAC |  | 50Hz |  |  | 30VDC |  | 10A
220VAC |  | 50Hz |  |  | 30VDC |  | SHORT
264VAC |  | 50Hz |  |  | 12VDC |  | NO LOAD
264VAC |  | 50Hz |  |  | 12VDC |  | 0,5A
264VAC |  | 50Hz |  |  | 12VDC |  | 5A
264VAC |  | 50Hz |  |  | 12VDC |  | 9A
264VAC |  | 50Hz |  |  | 12VDC |  | 10A
264VAC |  | 50Hz |  |  | 12VDC |  | SHORT
264VAC |  | 50Hz |  |  | 13,8VDC |  | NO LOAD
264VAC |  | 50Hz |  |  | 13,8VDC |  | 0,5A
264VAC |  | 50Hz |  |  | 13,8VDC |  | 5A
264VAC |  | 50Hz |  |  | 13,8VDC |  | 9A
264VAC |  | 50Hz |  |  | 13,8VDC |  | 10A
264VAC |  | 50Hz |  |  | 13,8VDC |  | SHORT
264VAC |  | 50Hz |  |  | 15VDC |  | NO LOAD
264VAC |  | 50Hz |  |  | 15VDC |  | 0,5A
264VAC |  | 50Hz |  |  | 15VDC |  | 5A
264VAC |  | 50Hz |  |  | 15VDC |  | 9A
264VAC |  | 50Hz |  |  | 15VDC |  | 10A
264VAC |  | 50Hz |  |  | 15VDC |  | SHORT
264VAC |  | 50Hz |  |  | 24VDC |  | NO LOAD
264VAC |  | 50Hz |  |  | 24VDC |  | 0,5A
264VAC |  | 50Hz |  |  | 24VDC |  | 5A
264VAC |  | 50Hz |  |  | 24VDC |  | 9A
264VAC |  | 50Hz |  |  | 24VDC |  | 10A
264VAC |  | 50Hz |  |  | 24VDC |  | SHORT
264VAC |  | 50Hz |  |  | 27,6VDC |  | NO LOAD
264VAC |  | 50Hz |  |  | 27,6VDC |  | 0,5A
264VAC |  | 50Hz |  |  | 27,6VDC |  | 5A
264VAC |  | 50Hz |  |  | 27,6VDC |  | 9A
264VAC |  | 50Hz |  |  | 27,6VDC |  | 10A
264VAC |  | 50Hz |  |  | 27,6VDC |  | SHORT
264VAC |  | 50Hz |  |  | 30VDC |  | NO LOAD
264VAC |  | 50Hz |  |  | 30VDC |  | 0,5A
264VAC |  | 50Hz |  |  | 30VDC |  | 5A
264VAC |  | 50Hz |  |  | 30VDC |  | 9A
264VAC |  | 50Hz |  |  | 30VDC |  | 10A
264VAC |  | 50Hz |  |  | 30VDC |  | SHORT
300VAC |  | 50Hz |  |  | 12VDC |  | NO LOAD
300VAC |  | 50Hz |  |  | 12VDC |  | 0,5A
300VAC |  | 50Hz |  |  | 12VDC |  | 5A
300VAC |  | 50Hz |  |  | 12VDC |  | 9A
300VAC |  | 50Hz |  |  | 12VDC |  | 10A
300VAC |  | 50Hz |  |  | 12VDC |  | SHORT
300VAC |  | 50Hz |  |  | 13,8VDC |  | NO LOAD
300VAC |  | 50Hz |  |  | 13,8VDC |  | 0,5A
300VAC |  | 50Hz |  |  | 13,8VDC |  | 5A
300VAC |  | 50Hz |  |  | 13,8VDC |  | 9A
300VAC |  | 50Hz |  |  | 13,8VDC |  | 10A
300VAC |  | 50Hz |  |  | 13,8VDC |  | SHORT
300VAC |  | 50Hz |  |  | 15VDC |  | NO LOAD
300VAC |  | 50Hz |  |  | 15VDC |  | 0,5A
300VAC |  | 50Hz |  |  | 15VDC |  | 5A
300VAC |  | 50Hz |  |  | 15VDC |  | 9A
300VAC |  | 50Hz |  |  | 15VDC |  | 10A
300VAC |  | 50Hz |  |  | 15VDC |  | SHORT
300VAC |  | 50Hz |  |  | 24VDC |  | NO LOAD
300VAC |  | 50Hz |  |  | 24VDC |  | 0,5A
300VAC |  | 50Hz |  |  | 24VDC |  | 5A
300VAC |  | 50Hz |  |  | 24VDC |  | 9A
300VAC |  | 50Hz |  |  | 24VDC |  | 10A
300VAC |  | 50Hz |  |  | 24VDC |  | SHORT
300VAC |  | 50Hz |  |  | 27,6VDC |  | NO LOAD
300VAC |  | 50Hz |  |  | 27,6VDC |  | 0,5A
300VAC |  | 50Hz |  |  | 27,6VDC |  | 5A
300VAC |  | 50Hz |  |  | 27,6VDC |  | 9A
300VAC |  | 50Hz |  |  | 27,6VDC |  | 10A
300VAC |  | 50Hz |  |  | 27,6VDC |  | SHORT
300VAC |  | 50Hz |  |  | 30VDC |  | NO LOAD
300VAC |  | 50Hz |  |  | 30VDC |  | 0,5A
300VAC |  | 50Hz |  |  | 30VDC |  | 5A
300VAC |  | 50Hz |  |  | 30VDC |  | 9A
300VAC |  | 50Hz |  |  | 30VDC |  | 10A
300VAC |  | 50Hz |  |  | 30VDC |  | SHORT

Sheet: TEST3
INPUT |  |  |  | OUTPUT |  |  | Çıkışa ters olarak bağlanacak akü şarj durumu | Çıkışa ters olarak bağlanacak akü nominal gerilimi
Vin (VAC) |  | Fr (Hz) |  | Vout(DC) |  | Iout(A)
İstenen | Ölçülen | İstenen | Ölçülen | İstenen | Ölçülen | İstenen |  | İstenen | Ölçülen
110VAC |  | 50Hz |  | 12VDC |  | NO LOAD | Boş yada boşa yakın | 12VDC
110VAC |  | 50Hz |  | 12VDC |  | NO LOAD | Tam şarjlı | 24VDC
110VAC |  | 50Hz |  | 13,8VDC |  | NO LOAD | Boş yada boşa yakın | 12VDC
110VAC |  | 50Hz |  | 13,8VDC |  | NO LOAD | Tam şarjlı | 24VDC
110VAC |  | 50Hz |  | 15VDC |  | NO LOAD | Boş yada boşa yakın | 12VDC
110VAC |  | 50Hz |  | 15VDC |  | NO LOAD | Tam şarjlı | 24VDC
110VAC |  | 50Hz |  | 24VDC |  | NO LOAD | Boş yada boşa yakın | 12VDC
110VAC |  | 50Hz |  | 24VDC |  | NO LOAD | Tam şarjlı | 24VDC
110VAC |  | 50Hz |  | 27,6VDC |  | NO LOAD | Boş yada boşa yakın | 12VDC
110VAC |  | 50Hz |  | 27,6VDC |  | NO LOAD | Tam şarjlı | 24VDC
110VAC |  | 50Hz |  | 30VDC |  | NO LOAD | Boş yada boşa yakın | 12VDC
110VAC |  | 50Hz |  | 30VDC |  | NO LOAD | Tam şarjlı | 24VDC
220VAC |  | 50Hz |  | 12VDC |  | NO LOAD | Boş yada boşa yakın | 12VDC
220VAC |  | 50Hz |  | 12VDC |  | NO LOAD | Tam şarjlı | 24VDC
220VAC |  | 50Hz |  | 13,8VDC |  | NO LOAD | Boş yada boşa yakın | 12VDC
220VAC |  | 50Hz |  | 13,8VDC |  | NO LOAD | Tam şarjlı | 24VDC
220VAC |  | 50Hz |  | 15VDC |  | NO LOAD | Boş yada boşa yakın | 12VDC
220VAC |  | 50Hz |  | 15VDC |  | NO LOAD | Tam şarjlı | 24VDC
220VAC |  | 50Hz |  | 24VDC |  | NO LOAD | Boş yada boşa yakın | 12VDC
220VAC |  | 50Hz |  | 24VDC |  | NO LOAD | Tam şarjlı | 24VDC
220VAC |  | 50Hz |  | 27,6VDC |  | NO LOAD | Boş yada boşa yakın | 12VDC
220VAC |  | 50Hz |  | 27,6VDC |  | NO LOAD | Tam şarjlı | 24VDC
220VAC |  | 50Hz |  | 30VDC |  | NO LOAD | Boş yada boşa yakın | 12VDC
220VAC |  | 50Hz |  | 30VDC |  | NO LOAD | Tam şarjlı | 24VDC
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

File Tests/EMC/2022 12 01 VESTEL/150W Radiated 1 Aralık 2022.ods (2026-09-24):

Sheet: Açıklamalar
Test 1 -> A | Test 3 -> A | Test 5 -> A | Test 7 -> A
470pF Primer Snubber | 470pF Primer Snubber | Test 3 | Test 5
Sens Primer MOSFET | Orijinal MOSFET | + Primer Gate 150R | + Sec Couplinglere 470pF eklenmesi
Orijinal Trafo | Orijinal Trafo
Test 2 -> B | Test 4 -> B | Test 6 -> B | Test 8 -> B
470pF Primer Snubber | Test 2 | Test 4 | Test 6
Orijinal MOSFET | + Toprağın trafonun yanına getirilmesi | + Sec soğutucu topraklı | + Primer soğutucuyu toprakla
Alternatif Trafo | + 3 Coupling (2 sec 1 pri)

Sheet: Sonuçlar
Test 1 -> A |  | Test 3 -> A |  |  | Test 5 -> A |  | Test 7 -> A |  | Test 9 -> A |  | Test 11 -> A
 | 1510 |  | 1510 |  |  | 1510 |  | 1510 |  | 1510 |  | 1510
 | 3005 |  | 3005
Test 2 -> B |  | Test 4 -> B |  | Test 6 -> B |  |  | Test 8 -> B |  | Test 10 -> B
 | 1510 |  | 1510 |  | 1510 |  |  | 1510 |  | 1510
3005

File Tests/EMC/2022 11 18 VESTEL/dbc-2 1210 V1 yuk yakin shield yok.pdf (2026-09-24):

# DBC-2

18.11.2022 13:24:35

### 1 / 1 - Page 1 of 2

Heading | dbc-2 1210 V1 yuk yakin shield yok

## Meas Type Equipment under Test

Manufacturer | enko
OP Condition | p
Operator | g.aktas
Test Spec | J

## Settings

Scan Start | 150.000000000 kHz
Scan Stop | 30.000000000 MHz
RBW | 9.0 kHz
IF RBW | 10.0 kHz
Meas Time | 1.0 s
RF Att | 10.0 dB
Preamp State | Off
Preamp Value | 0.0 dB
Input Selection | INP1
Input Coupling | AC
Scan Type | TD Scan
Transducer | ENV432 ENKO.TDF

## Scan Table

Scan Start | 150.000000000 kHz
Scan Stop | 30.000000000 MHz
Scan Type | TD Scan
Transducer | ENV432 ENKO.TDF
Detector | Trace 1: Max Peak Trace 2: Average
Start
Frequency

Stop
Frequency
Step Size | RBW | Meas Time | RF Atten | Preamp | Input
150.000 kHz | 30.000 MHz | 2.250 kHz | 9.0 kHz 100.0 ms 10.0 dB 0.0 dB INPUT1

## Peak List

Margin | 6.0 dB
Peaks | 25
Trace | Frequency | Level (dBµV) | Phase | Detector | Delta Limit/dB
1 | 9.879000000 MHz | 57.78 | L1 Positive Peak | -2.22
2 | 10.353750000 MHz | 44.29 | L1 | Average | -5.71
2 | 10.387500000 MHz | 44.31 | L1 | Average | -5.69
1 | 10.425750000 MHz | 56.57 | L1 Positive Peak | -3.43
1 | 10.563000000 MHz | 57.43 | L1 Positive Peak | -2.57
2 | 18.393000000 MHz | 48.19 | N | Average | -1.81
1 | 18.521250000 MHz | 60.59 | N Positive Peak | 0.59

## Final Results

Meas Time | 1.0 s
Margin | 6.0 dB
Peaks | 25
Trace | Frequency | Level (dBµV) | Phase | Detector | Delta Limit/dB
1 | 9.879000000 MHz | 49.95 | L1 | Quasi Peak | -10.05
2 | 10.353750000 MHz | 43.92 | L1 | CISPR AV | -6.08
2 | 10.387500000 MHz | 43.84 | L1 | CISPR AV | -6.16
1 | 10.425750000 MHz | 49.55 | L1 | Quasi Peak | -10.45
1 | 10.563000000 MHz | 49.29 | N | Quasi Peak | -10.71
2 | 18.393000000 MHz | 46.66 | N | CISPR AV | -3.34
1 | 18.521250000 MHz | 54.30 | N | Quasi Peak | -5.70

18.11.2022 13:24:35
Heading | dbc-2 1210 V1 yuk yakin shield yok

## Meas Type Equipment under Test

Manufacturer | enko
OP Condition | p
Operator | g.aktas
Test Spec | J

### 1 / 1 - Page 2 of 2

## Scan Diagram


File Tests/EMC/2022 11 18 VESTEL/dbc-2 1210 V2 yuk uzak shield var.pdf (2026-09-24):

# DBC-2

18.11.2022 15:02:13

### 1 / 1 - Page 1 of 2

Heading | dbc-2 1210 V2 yuk uzak shield var

## Meas Type Equipment under Test

Manufacturer | enko
OP Condition | p
Operator | g.aktas
Test Spec | J

## Settings

Scan Start | 150.000000000 kHz
Scan Stop | 30.000000000 MHz
RBW | 9.0 kHz
IF RBW | 10.0 kHz
Meas Time | 1.0 s
RF Att | 10.0 dB
Preamp State | Off
Preamp Value | 0.0 dB
Input Selection | INP1
Input Coupling | AC
Scan Type | TD Scan
Transducer | ENV432 ENKO.TDF

## Scan Table

Scan Start | 150.000000000 kHz
Scan Stop | 30.000000000 MHz
Scan Type | TD Scan
Transducer | ENV432 ENKO.TDF
Detector | Trace 1: Max Peak Trace 2: Average
Start
Frequency

Stop
Frequency
Step Size | RBW | Meas Time | RF Atten | Preamp | Input
150.000 kHz | 30.000 MHz | 2.250 kHz | 9.0 kHz 100.0 ms 10.0 dB 0.0 dB INPUT1

## Peak List

Margin | 6.0 dB
Peaks | 25
Trace | Frequency | Level (dBµV) | Phase | Detector | Delta Limit/dB
1 | 9.809250000 MHz | 56.06 | L1 Positive Peak | -3.94
1 | 10.286250000 MHz | 55.19 | L1 Positive Peak | -4.81
2 | 10.351500000 MHz | 44.10 | L1 | Average | -5.90
1 | 10.356000000 MHz | 55.95 | L1 Positive Peak | -4.05
2 | 10.385250000 MHz | 44.19 | L1 | Average | -5.81
2 | 10.416750000 MHz | 44.31 | L1 | Average | -5.69
1 | 10.423500000 MHz | 56.08 | L1 Positive Peak | -3.92
2 | 10.450500000 MHz | 44.28 | L1 | Average | -5.72
1 | 10.765500000 MHz | 57.52 | L1 Positive Peak | -2.48

## Final Results

Meas Time | 1.0 s
Margin | 6.0 dB
Peaks | 25
Trace | Frequency | Level (dBµV) | Phase | Detector | Delta Limit/dB
1 | 9.809250000 MHz | 48.55 | L1 | Quasi Peak | -11.45
1 | 10.286250000 MHz | 49.85 | L1 | Quasi Peak | -10.15
2 | 10.351500000 MHz | 43.92 | L1 | CISPR AV | -6.08
1 | 10.356000000 MHz | 49.29 | L1 | Quasi Peak | -10.71
2 | 10.385250000 MHz | 43.98 | L1 | CISPR AV | -6.02
2 | 10.416750000 MHz | 43.85 | L1 | CISPR AV | -6.15
1 | 10.423500000 MHz | 49.95 | L1 | Quasi Peak | -10.05
2 | 10.450500000 MHz | 43.78 | L1 | CISPR AV | -6.22
1 | 10.765500000 MHz | 51.26 | L1 | Quasi Peak | -8.74

18.11.2022 15:02:13
Heading | dbc-2 1210 V2 yuk uzak shield var

## Meas Type Equipment under Test

Manufacturer | enko
OP Condition | p
Operator | g.aktas
Test Spec | J

### 1 / 1 - Page 2 of 2

## Scan Diagram


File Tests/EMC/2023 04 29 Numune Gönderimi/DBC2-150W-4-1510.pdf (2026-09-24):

# DBC2

19.04.2023 15:59:39

### 1 / 1 - Page 1 of 2

Heading | DBC2-150W-4-1510

## Meas Type Equipment under Test DBC2

Manufacturer | ENKO
OP Condition | p
Operator | C.U.
Test Spec | J

## Settings

Scan Start | 150.000000000 kHz
Scan Stop | 30.000000000 MHz
RBW | 9.0 kHz
IF RBW | 10.0 kHz
Meas Time | 1.0 s
RF Att | 10.0 dB
Preamp State | Off
Preamp Value | 0.0 dB
Input Selection | INP1
Input Coupling | AC
Scan Type | TD Scan
Transducer | ENV432 ENKO.TDF

## Scan Table

Scan Start | 150.000000000 kHz
Scan Stop | 30.000000000 MHz
Scan Type | TD Scan
Transducer | ENV432 ENKO.TDF
Detector | Trace 1: Max Peak Trace 2: Average
Start
Frequency

Stop
Frequency
Step Size | RBW | Meas Time | RF Atten | Preamp | Input
150.000 kHz | 30.000 MHz | 2.250 kHz | 9.0 kHz | 10.0 ms 10.0 dB 0.0 dB INPUT1

## Peak List

Margin | 6.0 dB
Peaks | 25
Trace | Frequency | Level (dBµV) | Phase | Detector | Delta Limit/dB
1 204.000000000 kHz | 58.50 | L1 Positive Peak | -4.95
1 | 3.621750000 MHz | 50.62 | L1 Positive Peak | -5.38
1 | 12.167250000 MHz | 54.77 | L1 Positive Peak | -5.23
1 | 12.718500000 MHz | 55.86 | L1 Positive Peak | -4.14
1 | 16.957500000 MHz | 58.06 | L1 Positive Peak | -1.94
2 | 17.047500000 MHz | 45.86 | N | Average | -4.14
2 | 17.490750000 MHz | 46.28 | N | Average | -3.72

## Final Results

Meas Time | 1.0 s
Margin | 6.0 dB
Peaks | 25
Trace | Frequency | Level (dBµV) | Phase | Detector | Delta Limit/dB
1 204.000000000 kHz | 56.25 | L1 | Quasi Peak | -7.20
1 | 3.621750000 MHz | 46.50 | L1 | Quasi Peak | -9.50
1 | 12.167250000 MHz | 47.21 | L1 | Quasi Peak | -12.79
1 | 12.718500000 MHz | 49.20 | L1 | Quasi Peak | -10.80
1 | 16.957500000 MHz | 52.17 | N | Quasi Peak | -7.83
2 | 17.047500000 MHz | 44.01 | N | CISPR AV | -5.99
2 | 17.490750000 MHz | 44.42 | L1 | CISPR AV | -5.58

19.04.2023 15:59:39
Heading | DBC2-150W-4-1510

## Meas Type Equipment under Test DBC2

Manufacturer | ENKO
OP Condition | p
Operator | C.U.
Test Spec | J

### 1 / 1 - Page 2 of 2

## Scan Diagram


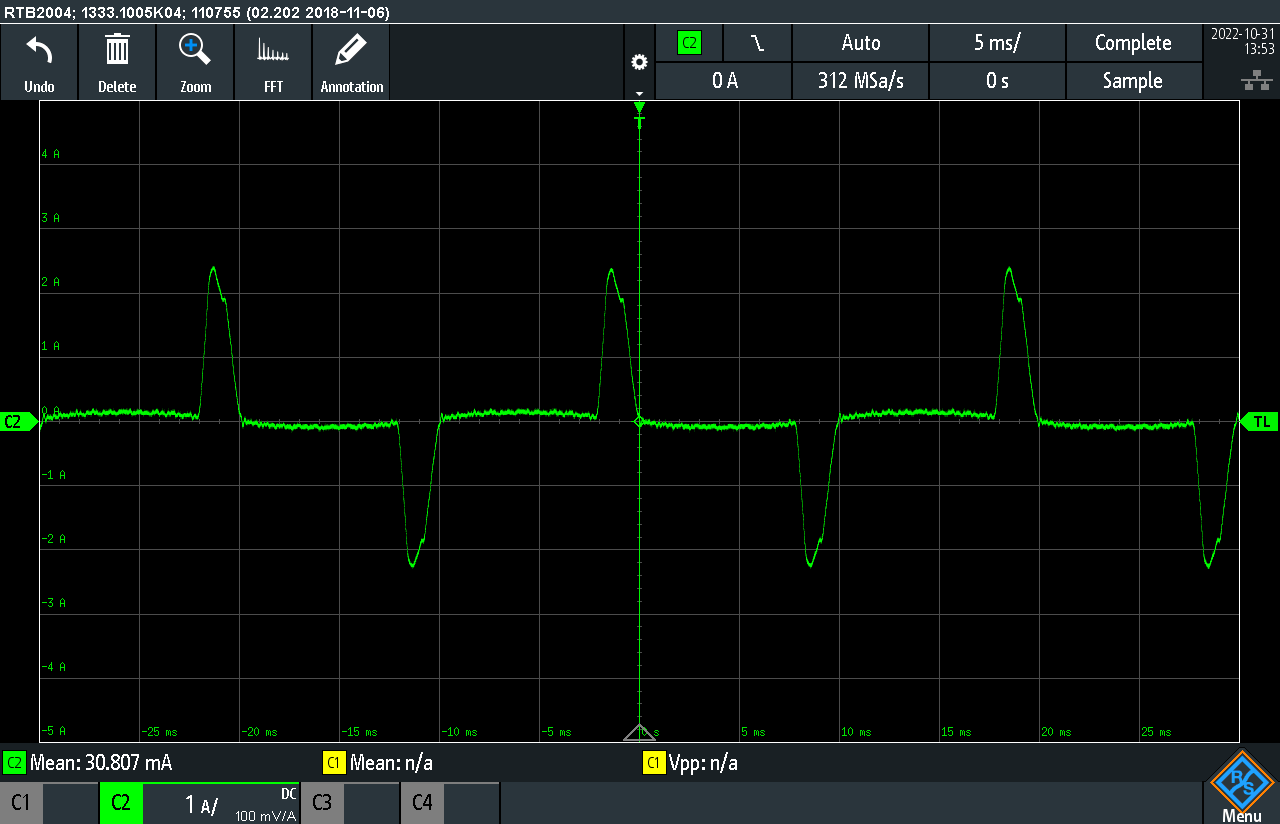
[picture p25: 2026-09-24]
Tests/Harmonik/Harmonik 31 Ekim 90W/SAVE04/SCR.PNG

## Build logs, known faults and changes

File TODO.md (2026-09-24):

# TODO

- Create 300W .ioc
- Add CANBus Lib
- Add SPNs
- STATs are Disabled because of second signature. Re-enable them and open them up on modbus
- SCADA should be able to display stats
- TAG should be tested with new modbus, it is also disabled
- Main coreLoop() should be a state machine with well defined behaviour, not a mess like this!

Before updating the software version:
-Fix version 9999.
-Resolve CubeMX compatibility issues to ensure operation with V7 PCB (PWM frequency was increased by a factor of 10).
-Set the password to always default to Level1 for proper communication with SCADA.
-Remove USBPinDown function.
+Add tempVal to allow software-based derating.

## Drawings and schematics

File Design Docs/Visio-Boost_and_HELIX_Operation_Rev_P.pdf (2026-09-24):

# MicroGenius LE – Boost and HELIX Operation (Rev. P)

## SENS Proprietary and Confidential Information

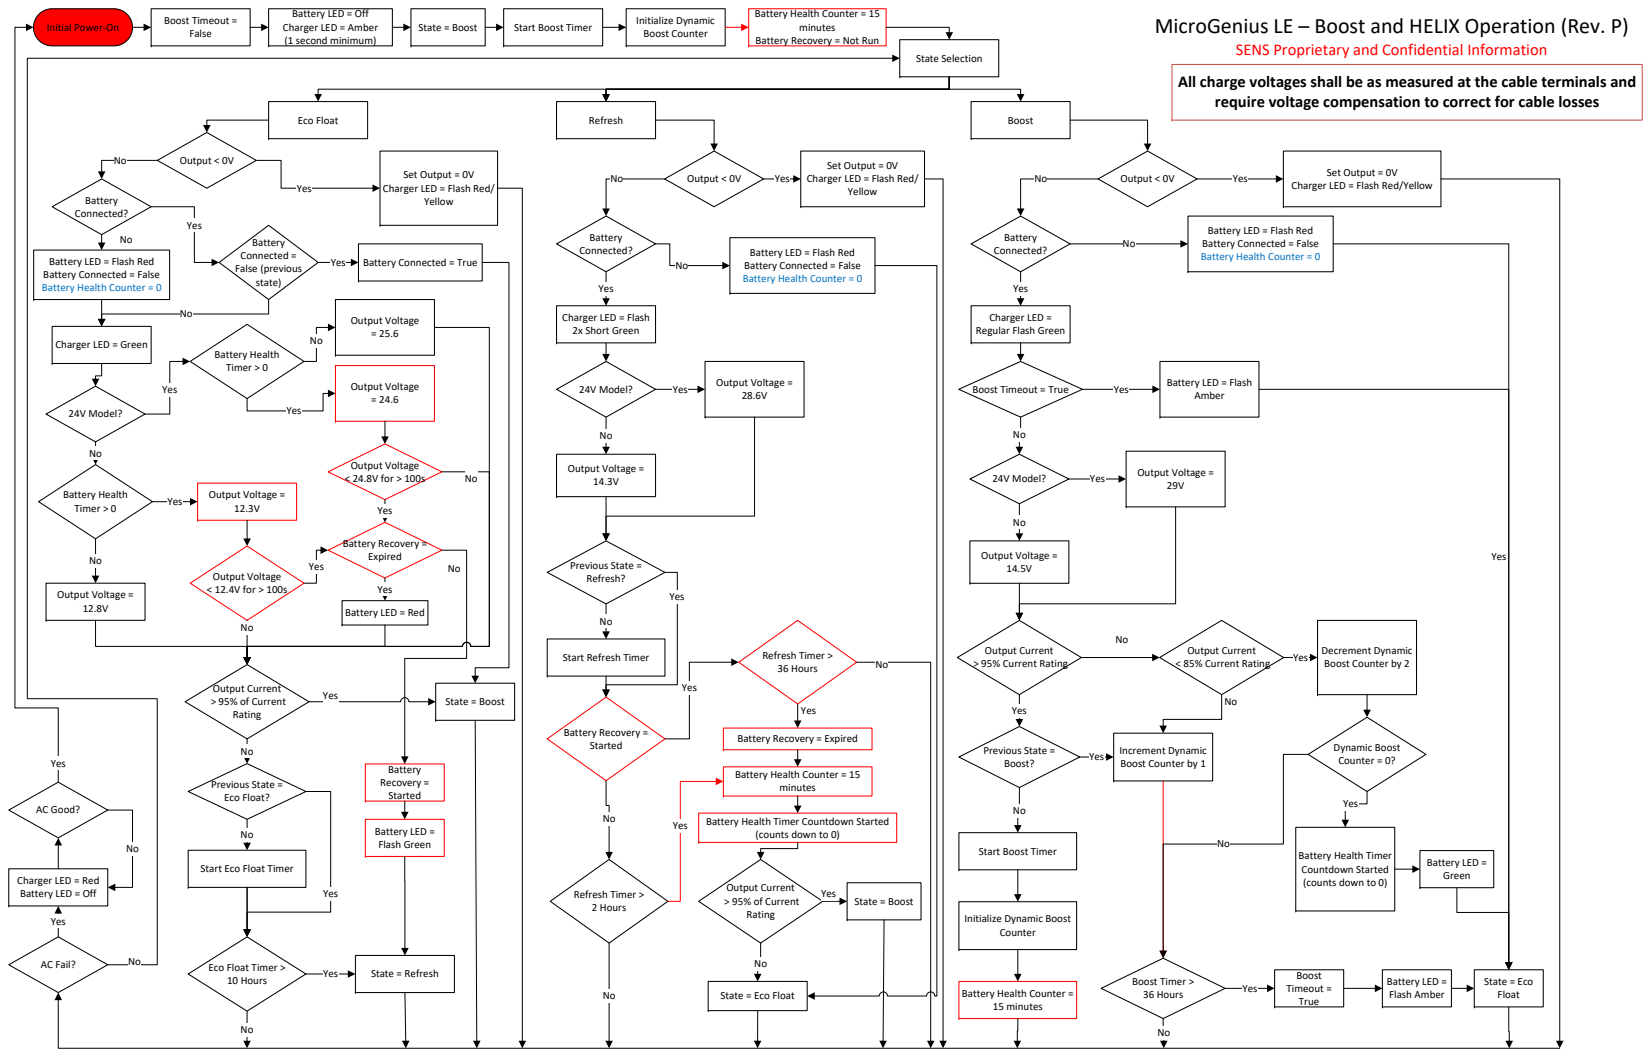
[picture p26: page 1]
Eco Float; 24V Model?; Output Voltage = 12.8V; Output Voltage = 25.6; Output Current > 95% of Current Rating; Yes; State = Boost; Previous State = Eco Float?; State = Refresh; Refresh; Output Voltage = 14.3V; Output Voltage = 28.6V; Previous State = Refresh?; Refresh Timer >; 2 Hours; Boost; Output Voltage = 14.5V; Output Voltage = 29V; Output Current > 95% Current Rating; Previous State = Boost?; Boost Timer > 36 Hours; Boost Timeout = True; State = Eco Float; Counter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

Battery LED = Off
Charger LED = Amber
(1 second minimum)

Battery Health Counter = 15

Initial Power‐On

Battery Recovery = Not Run

All charge voltages shall be as measured at the cable terminals and
require voltage compensation to correct for cable losses

Set Output = 0V
Charger LED = Flash Red/

Battery LED = Flash Red
Battery Connected = False

Battery Health Counter = 0 No

Battery Health Counter = 0

Battery Connected = True

Charger LED = Flash
2x Short Green

Charger LED =
Regular Flash Green

Charger LED = Green

Boost Timeout = True

Battery LED = Flash

Battery LED = Red

Decrement Dynamic
Yes
Boost Counter by 2

Start Refresh Timer

Battery Recovery = Expired

Battery Health Timer Countdown Started

(counts down to 0)

Start Boost Timer

Battery Health Timer
Countdown Started

Start Eco Float Timer

Charger LED = Red

Initialize Dynamic Boost

Eco Float Timer >
10 Hours

Battery Health Counter =
15 minutes

State = Eco Float

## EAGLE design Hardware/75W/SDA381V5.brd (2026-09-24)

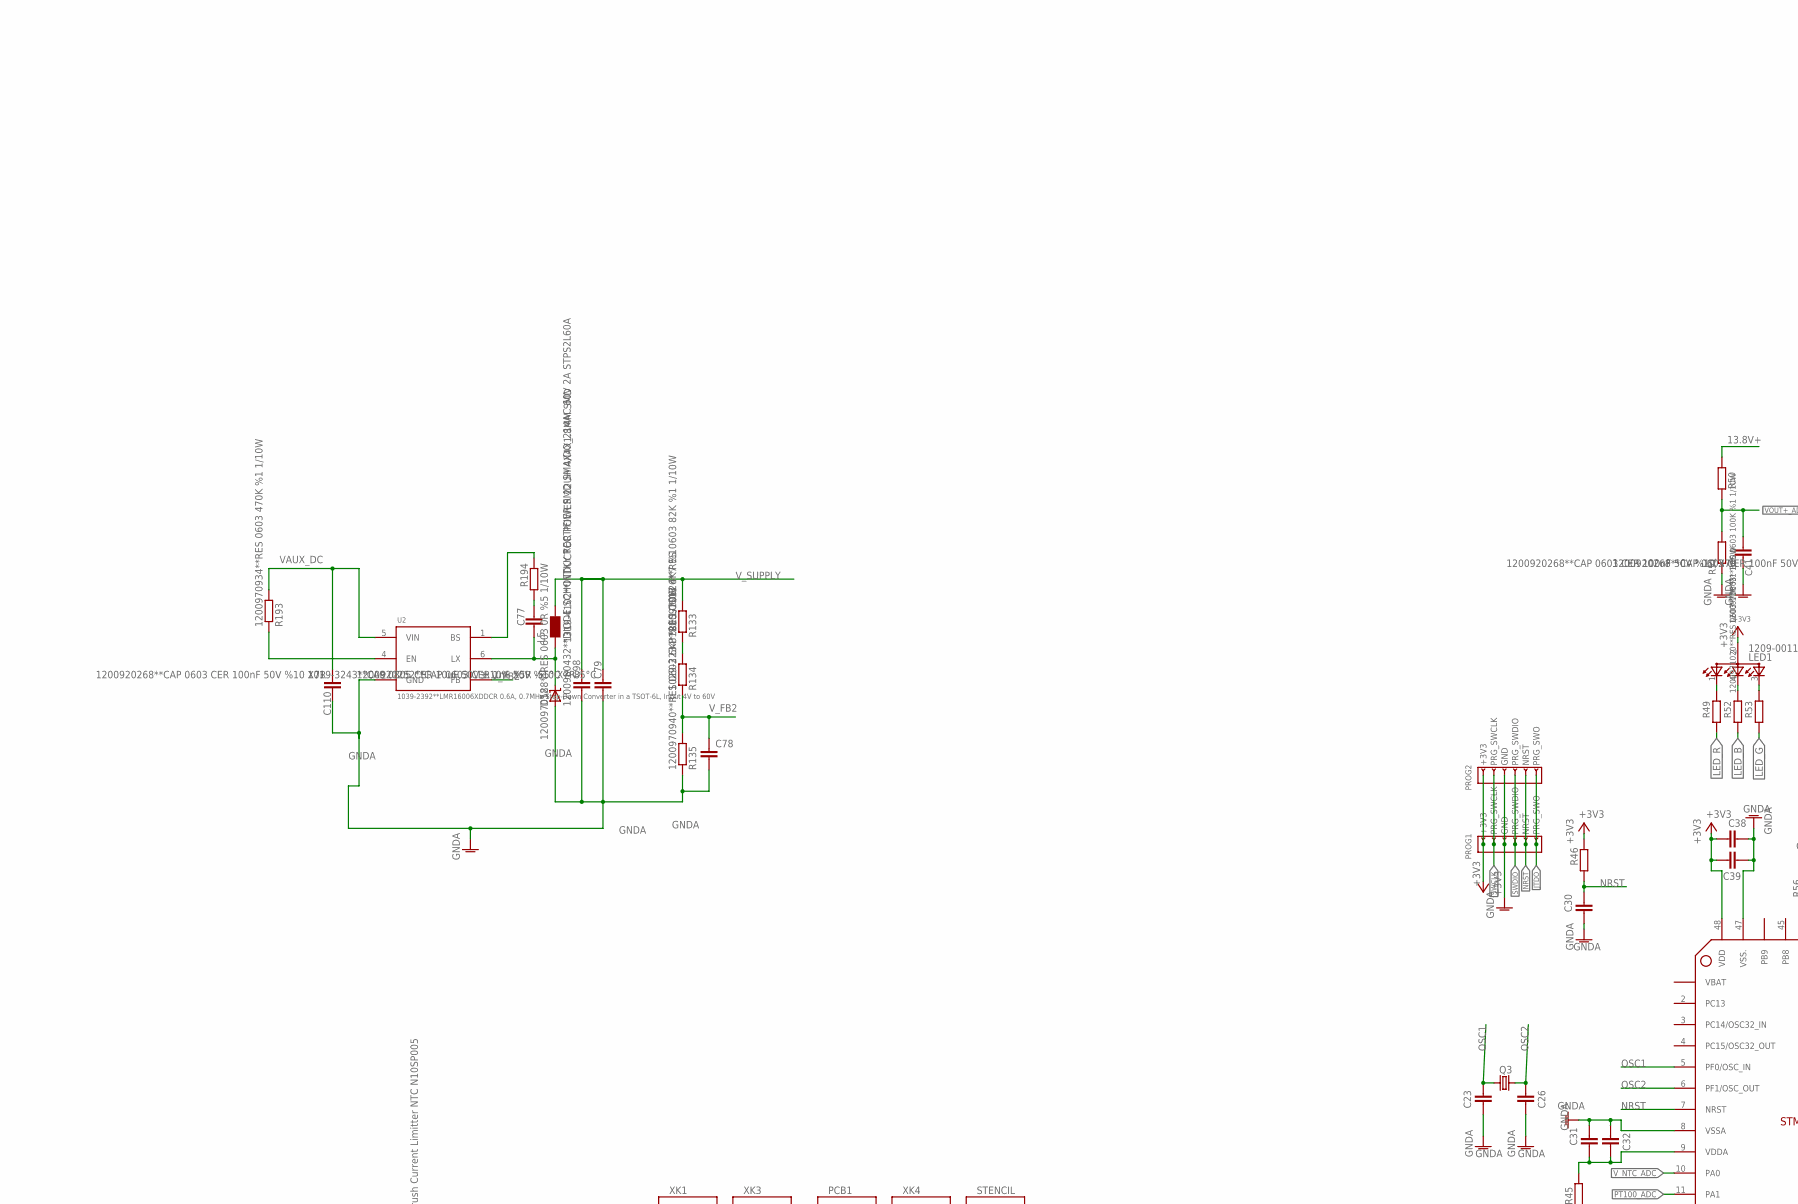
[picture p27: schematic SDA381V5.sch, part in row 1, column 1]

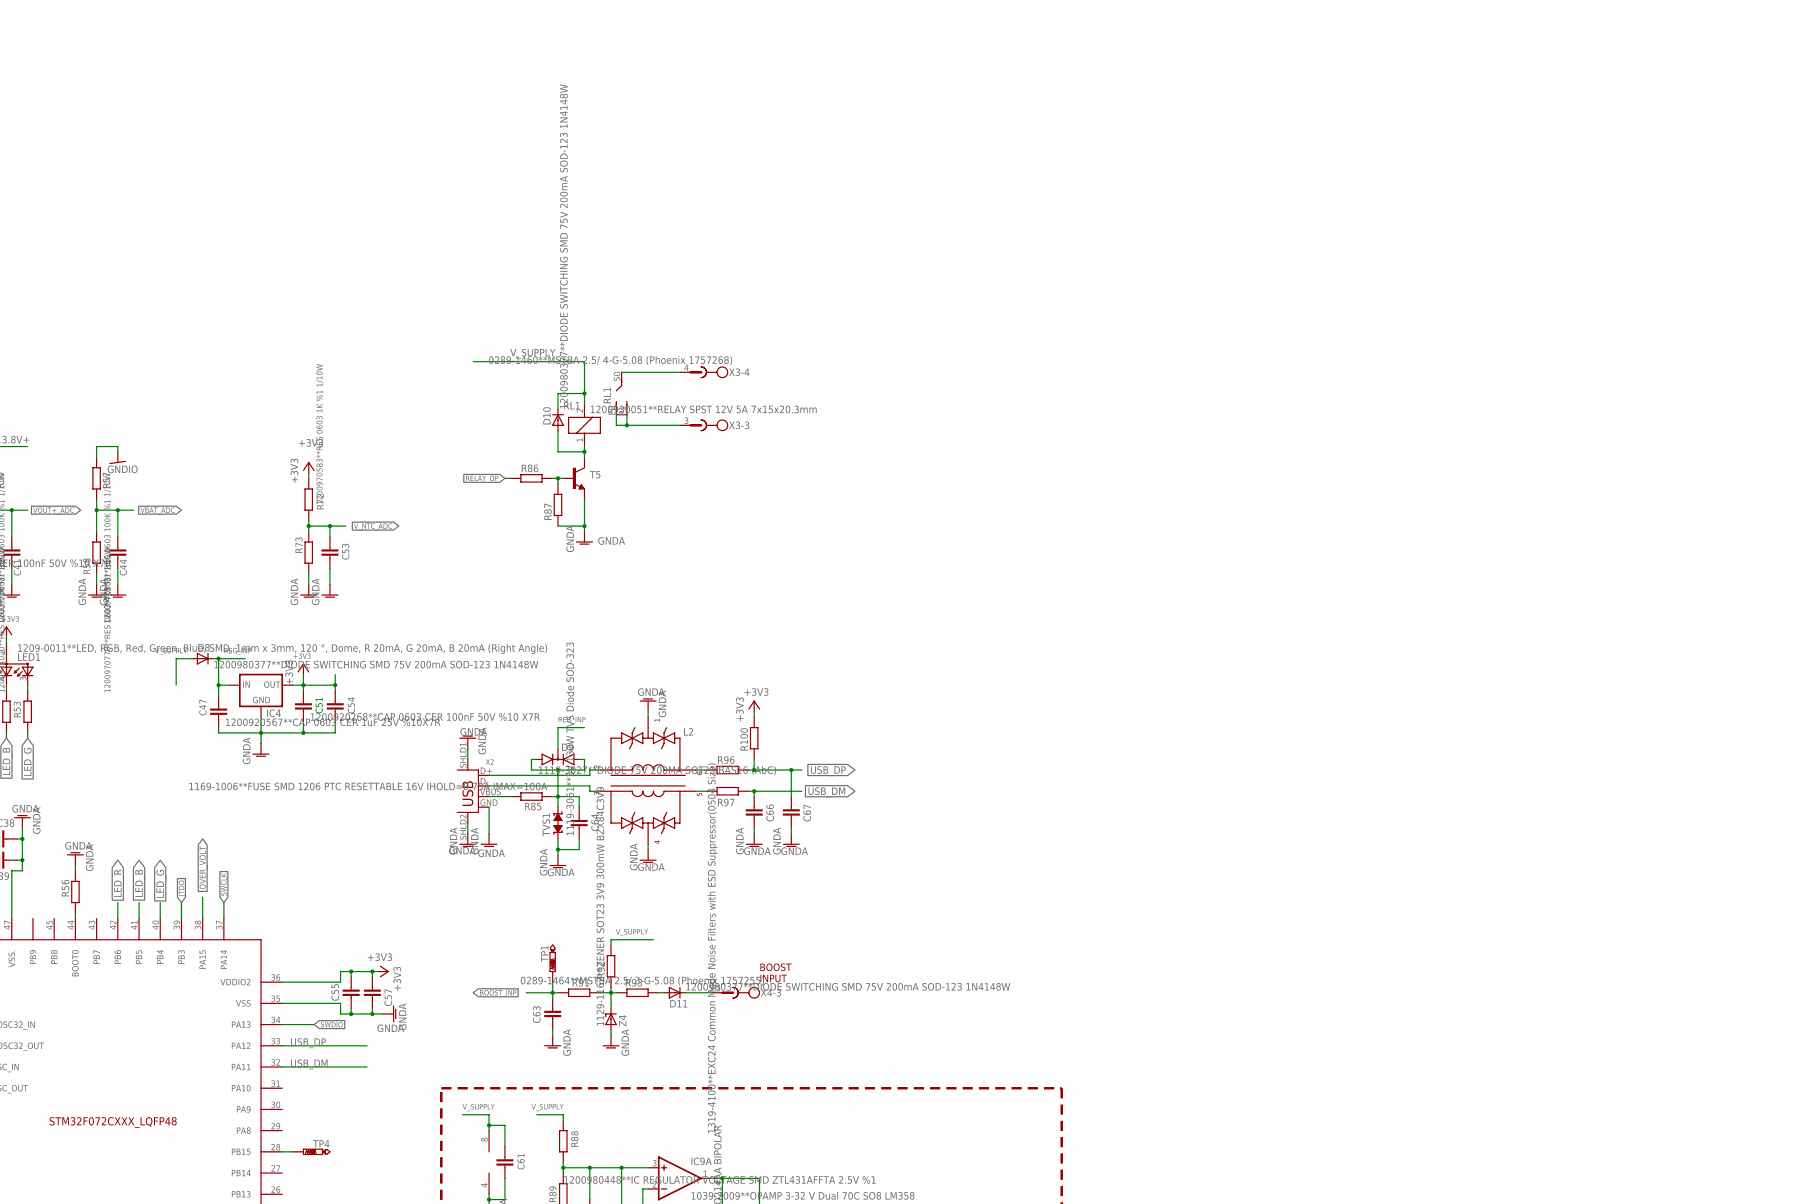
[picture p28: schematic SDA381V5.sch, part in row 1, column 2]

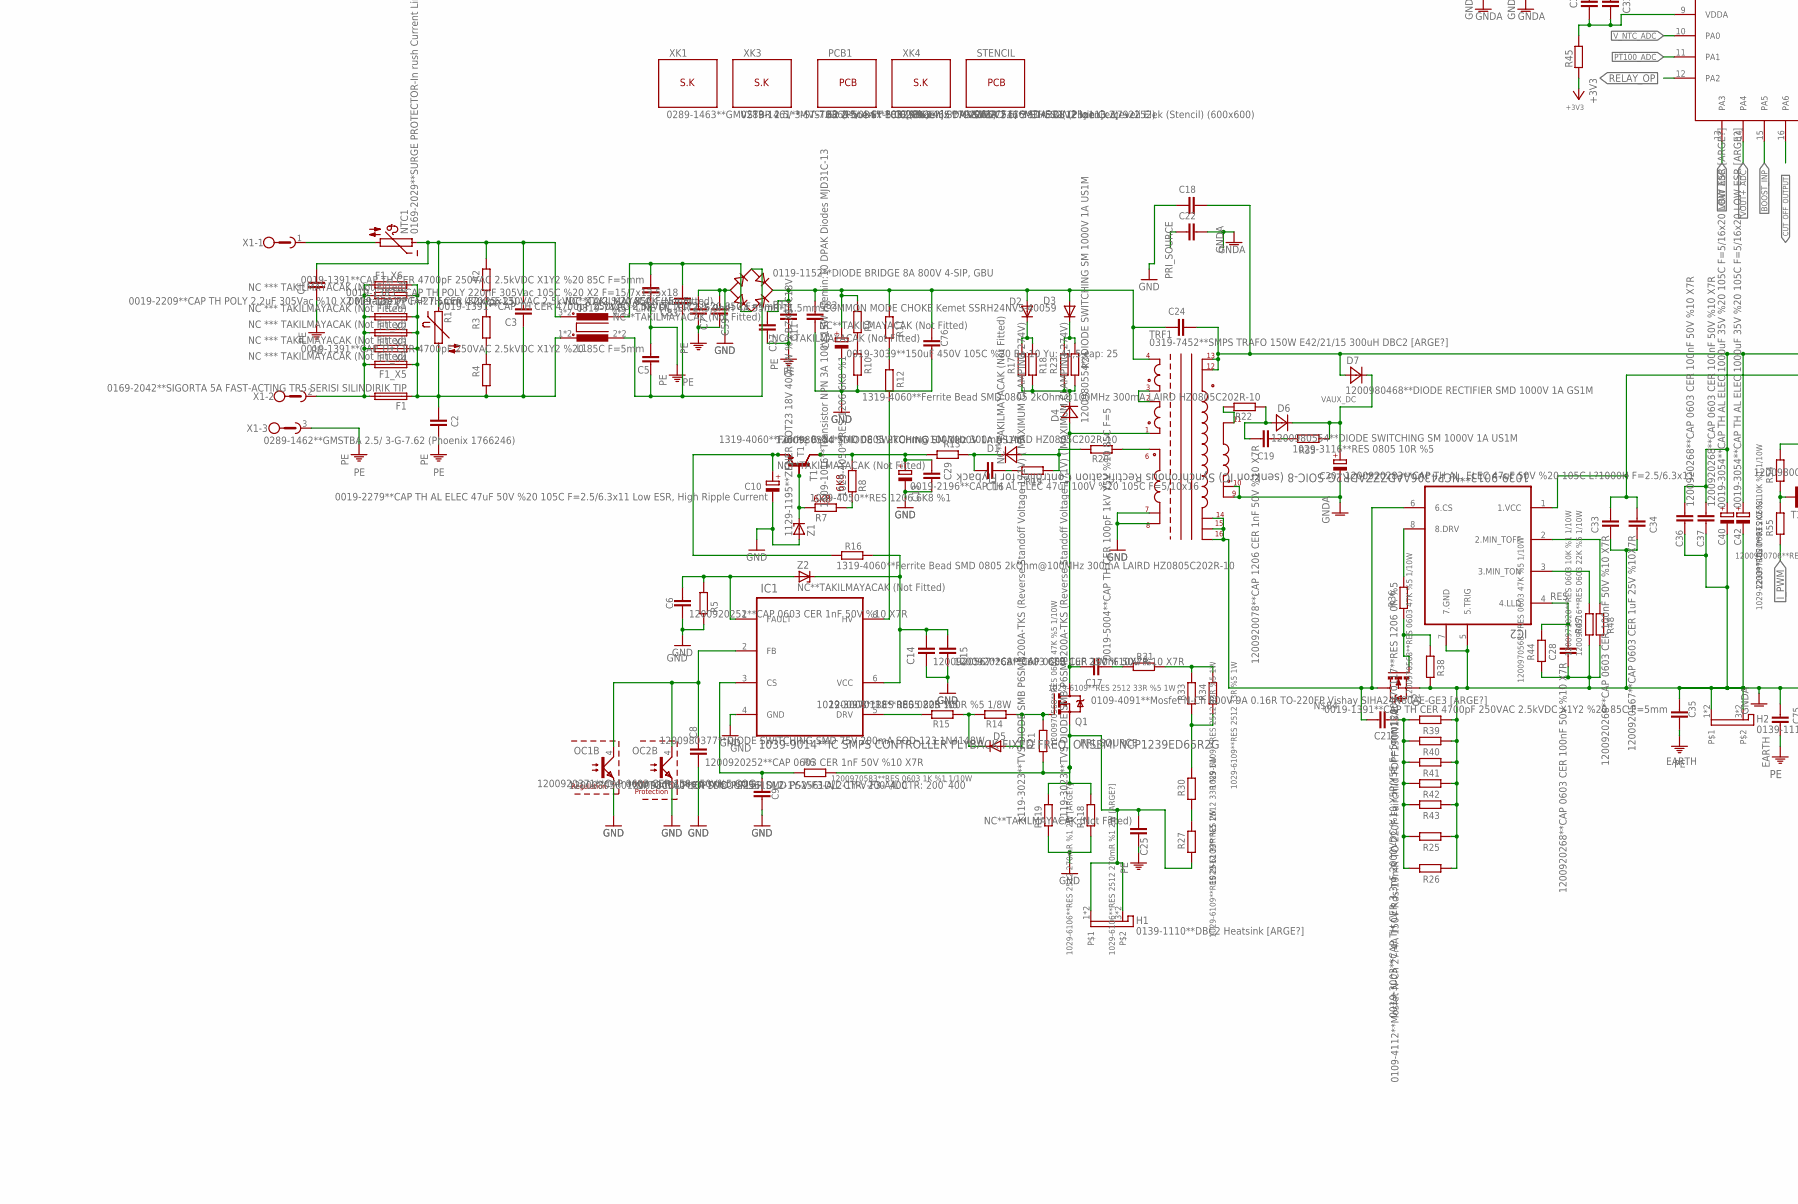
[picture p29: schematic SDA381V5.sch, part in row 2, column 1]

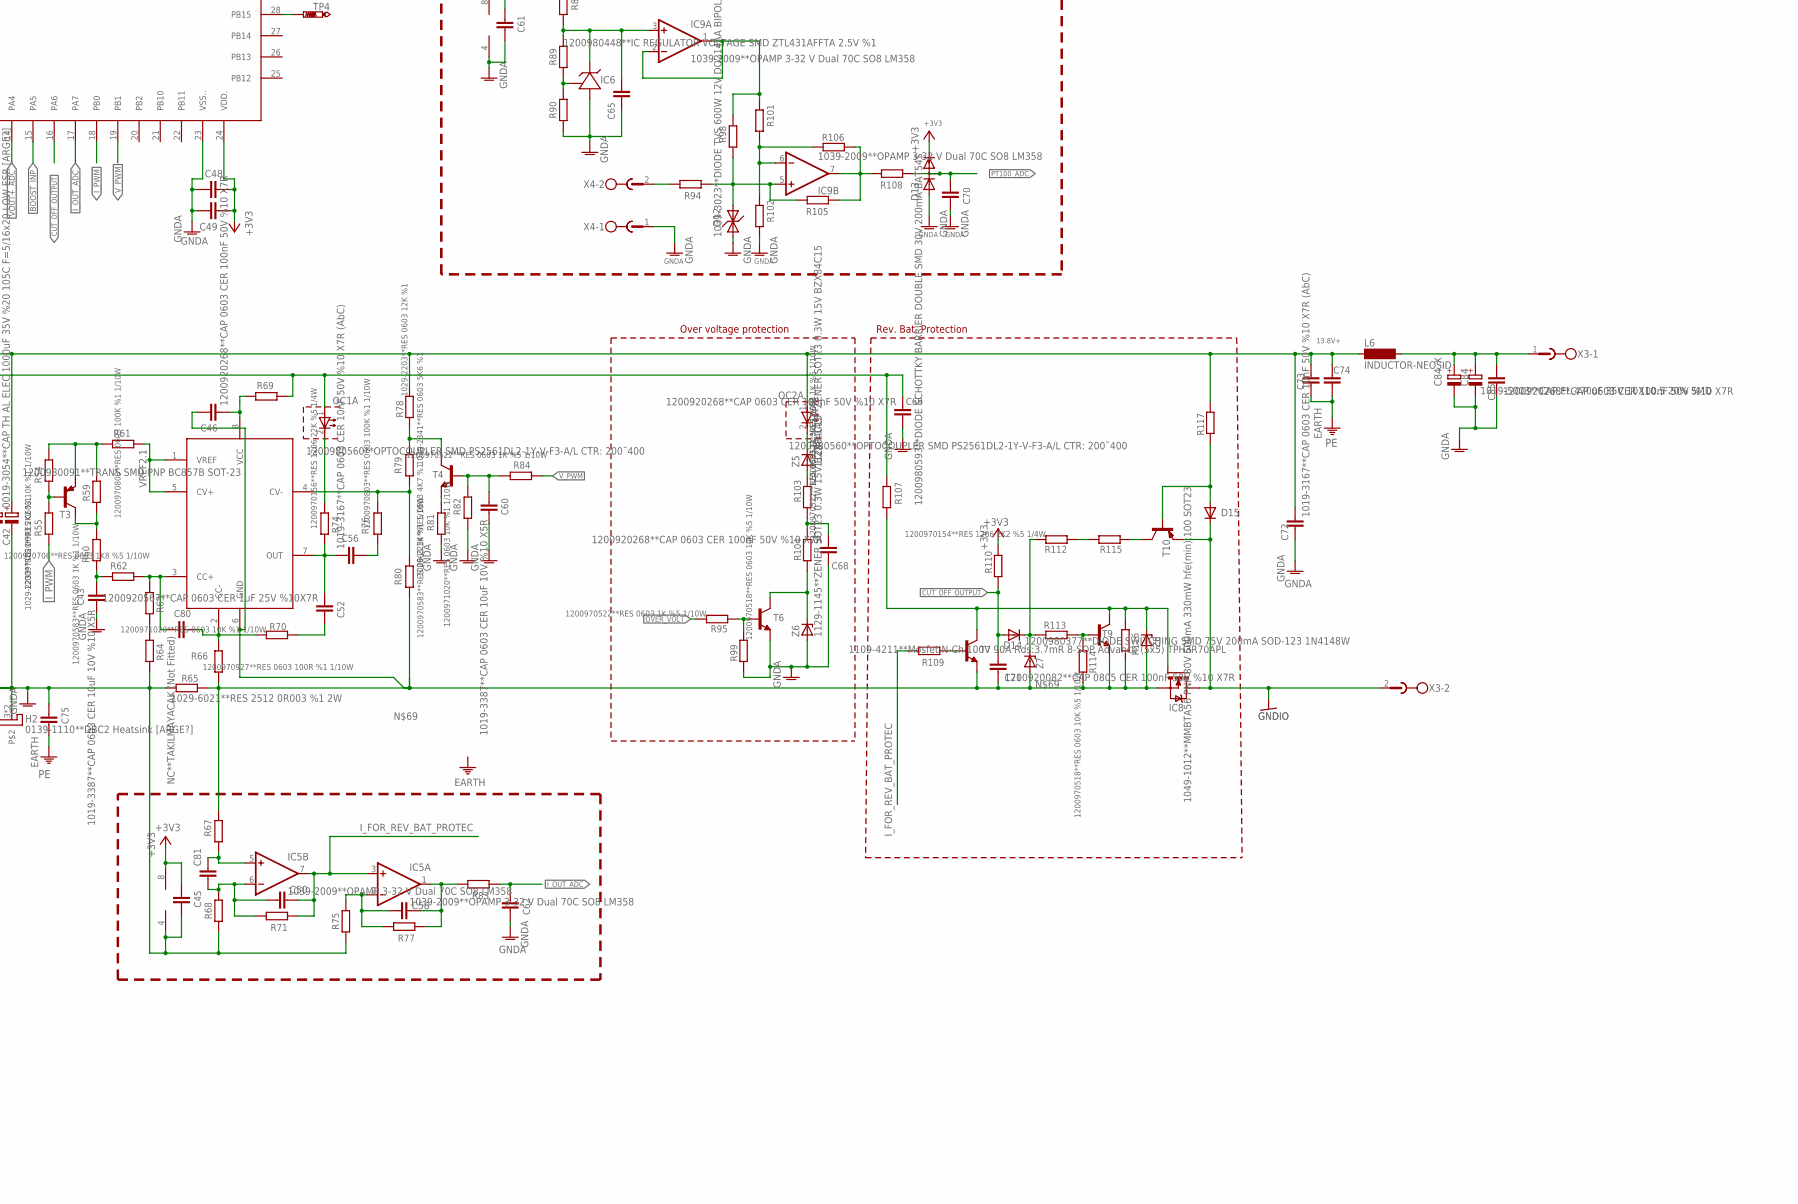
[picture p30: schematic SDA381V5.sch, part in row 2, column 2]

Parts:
B1: 0119-1152**DIODE BRIDGE 8A 800V 4-SIP, GBU; DıODE_BRIDGE_8A_DIK
C1, C2, C25, C27, C59: NC**TAKILMAYACAK (Not Fitted); C50-035X75
C3: 0019-2209**CAP TH POLY 2.2uF 305Vac %10 X2 Metali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; C275-113X316_&_C150-072X183_&_C225-113X268
C4, C5, C7, C11: 0019-1391**CAP TH CER 4700pF 250VAC 2.5kVDC X1Y2 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; C50-035X75
C6, C8, C98: 1200920252**CAP 0603 CER 1nF 50V %10 X7R; C0603_ENKO
C9, C58: 1200920371**CAP 0603 CER 150p 50V%5 COG; C0603_ENKO
C10: 0019-2279**CAP TH AL ELEC 47uF 50V %20 105C F=2.5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; E2,5-7
C12: 0019-3039**150uF 450V 105C %20 Ba:10 Yu: 41,5 çap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; EB25D
C13: 0019-2196**CAP TH AL ELEC 47uF 100V %20 105C F=5/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; E5-10,5
C14, C34, C47, C52: 1200920567**CAP 0603 CER 1uF 25V %10X7R; C0603_ENKO
C15, C28, C30, C31, C33, C36, C37, C38, C41, C44, C45, C46, C49, C51, C53, C57, C61, C62, C64, C65, C68, C69, C70, C77, C85, C110: 1200920268**CAP 0603 CER 100nF 50V %10 X7R; C0603_ENKO
C16, C29: NC**TAKILMAYACAK (Not Fitted); C1206_ENKO
C17: 0019-5004**CAP TH CER 100pF 1kV Y5V %10 85C F=5; C075-32X103/C050-035X75
C18: 1200920292**CAP TH CER 2.2nF 300Vac %20 X1Y2 F=7.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; C075-32X103_DEIF
C19: 1200920078**CAP 1206 CER 1nF 50V %10 X7R; C1206_ENKO
C20: 1200920283**CAP TH AL. ELEC 47uF 50V %20 105C L?1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; E2,5-7
C21: 0019-3003**CAP TH CER 3.3nF 2000VDC %10 Y5P/Y5E F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; C050-045X075
C22, C24: NC**TAKILMAYACAK (Not Fitted); C075-32X103_DEIF
C23, C26: 1019-3352**CAP 0603 CER 22pF 50V %5 NPO; C0603_ENKO
C32, C39, C48, C55, C56, C63, C72: 1019-3167**CAP 0603 CER 10nF 50V %10 X7R (AbC); C0603_ENKO
C35: 0019-1391**CAP TH CER 4700pF 250VAC 2.5kVDC X1Y2 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; C050-045X075
C40: 0019-3054**CAP TH AL ELEC 1000uF 35V %20 105C F=5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; E5-13/E7,5-16
C42: 0019-3054**CAP TH AL ELEC 1000uF 35V %20 105C F=5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; E5-13
C43, C60: 1019-3387**CAP 0603 CER 10uF 10V %10 X5R; C0603_ENKO
C50, C80, C81: NC**TAKILMAYACAK (Not Fitted); C0603_ENKO
C54: 1019-3301**CAP 0805 47uF 6.3V %20 X5R; C0805_ENKO
C66, C67: 1019-3381**CAP 0603 CER 33pf 50V %5 NPO(COG); C0603_ENKO
C71: 1200920082**CAP 0805 CER 100nF 50V %10 X7R; C0805_ENKO
C73: 0019-1391**CAP TH CER 4700pF 250VAC 2.5kVDC X1Y2 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; C050-035X075
C74, C75: NC**TAKILMAYACAK (Not Fitted); C050-035X075
C76: NC**TAKILMAYACAK (Not Fitted); C065-052X106
C78: 1200920271**CAP 0603 CER 10pF 50V%10 COG; C0603_ENKO
C79: 1019-3243**CAP 0805 CER 10uF 50V ±10% X5R -55°C ~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; C0805_ENKO
C82: NC**TAKILMAYACAK (Not Fitted); C150-091X182
C83: 0019-1383**CAP TH POLY 220nF 305Vac 105C %20 X2 F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; C150-091X182_C225-108X268
C84: 1019-5003**CAP.EL.470uF 35V 10X10.5 20% SMD; E5-10,5
C84_X: CPOL-EUE2.5-7; E2,5-7
D1, D4, D6: 1200980554**DIODE SWITCHING SM 1000V 1A US1M; M7_DC_DIYOT
D2, D3: 1119-3023**TVS DIODE SMB P6SMB200A-TKS (Reverse S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; SMB
D5, D8, D10, D11, D14, D15: 1200980377**DIODE SWITCHING SMD 75V 200mA SOD-123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; SOD123
D7: 1200980468**DIODE RECTIFIER SMD 1000V 1A GS1M; M7_DC_DIYOT
D9: 1119-3027**DIODE 75V 200MA SOT23 BAS16 (AbC); SOT23
D12: 1039-3023**DIODE TVS 600W 12V DO214AA BIPOLAR; TRANSIL_SMB
D13: 1200980593**DIODE SCHOTTKY BARRIER DOUBLE SMD 30V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; SOT23
D18: 1200980432**DIODE SCHOTTKY RECTIFIER SMD SMA/DO_2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; SMA
F1: 0169-2042**SIGORTA 5A FAST-ACTING TR5 SERISI SILI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; SENS_FUSE
F1_X1: NC *** TAKILMAYACAK (Not Fitted); FUSE_0678D
F1_X2: NC *** TAKILMAYACAK (Not Fitted); FUSE_1025FA
F1_X3: NC *** TAKILMAYACAK (Not Fitted); FUSE_EBF_FUSE_446/447
F1_X4: NC *** TAKILMAYACAK (Not Fitted); FUSE_OMF250
F1_X5: NC *** TAKILMAYACAK (Not Fitted); FUSE_UMF250
F1_X6: FUSE_TYPE0679H
H1, H2: 0139-1110**DBC2 Heatsink [ARGE?]; DEIF_SOGUTUCU_2
IC1: 1039-9014**IC SMPS CONTROLLER FLYBACK FIXED FREQ.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; NCP1239_SMPS_IC
IC2: 1039-9013**NCP4306AADZZZADR2G SOIC-8 (senkron IC)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; NCP4306
IC3: 1039-2224**TSM1011ID SO-8 Constant Voltage and Co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; SO-8
IC4: 1039-3003**Voltage Regulator SOT-89 3.3V Diodes A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; SOT89
IC5, IC9: 1039-2009**OPAMP 3-32 V Dual 70C SO8 LM358; SO08
IC6: 1200980448**IC REGULATOR VOLTAGE SMD ZTL431AFFTA 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; TL431_SOT23F
IC8: 1109-4211**Mosfet N-Ch 100V 90A Rds:3.7mR 8-SOP A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; TPH6R30ANL
L1: 0319-7445**LINE FILTER 2x5,9mH 4A 55mR 11.5mm COM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; UU1620_&_FWCMET24V
L2: 1319-4100**EXC24 Common Mode Noise Filters with E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; EXC24CS_COMMON_MODE
L5: 1319-4102**INDUCTOR POWER 22UH 4X4X1.8MM SMD; WE-PD2_5MM
L6: INDUCTOR-NEOSID
LED1: 1209-0011**LED, RGB, Red, Green, Blue, SMD, 1mm x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; KPFA-3010RGBC-11
NTC1: 0169-2029**SURGE PROTECTOR-In rush Current Limitt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; NTC_15R_2A_&_N15SP005-5
OC1, OC2: 1200980560**OPTOCOUPLER SMD PS2561DL2-1Y-V-F3-A/L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; PS2561DL2-1_OPTO1
PCB1: 0369-5034**PCB [ARGE?] SDA381V2CF416M3HFS2(123x11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; PCB
PROG1, PROG2: NC**TAKILMAYACAK (Not Fitted); PROG_6PIN
Q1: 0109-4091**Mosfet N-Ch 800V 9A 0.16R TO-220FP Vis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; TO220BV
Q2: 0109-4112**Mosfet N-Ch 27.4A 150V Rds:19mR TO-220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; TO220BV
Q3: 1149-0006**HC49S SMD KRISTAL 8MHZ -40+85 20PF 50P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; HC49UP
R1: 0169-2013**Varistor 20mm 300V; S20K40
R2, R3, R4: 1200970587**RES 1206 470K %5 1/4W; R1206_ENKO
R5: 1200970687**RES 0603 56K %1 1/10W; R0603_ENKO
R6, R60, R61, R72, R75, R81, R89, R102: 1200970583**RES 0603 1K %1 1/10W; R0603_ENKO
R7, R8: 1029-4050**RES 1206 6K8 %1; R1206_ENKO
R9, R10: 1200970179**RES 1206 330K %5 1/4W; R1206_ENKO
R11, R12, R112: 1200970154**RES 1206 2K2 %5 1/4W; R1206_ENKO
R13: 1200970601**RES 1206 10R %5 1/4W; R1206_ENKO
R14: 1200970118**RES 0805 100R %5 1/8W; R0805_ENKO
R15: 1029-3008**RES 0805 22R %5; R0805_ENKO
R16, R20, R22, R45: 1319-4060**Ferrite Bead SMD 0805 2kOhm@100MHz 300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; R0805_ENKO
R17, R18, R23, R24: 1029-3146**RES 1206 7R68 %1; R1206_ENKO
R19: NC**TAKILMAYACAK (Not Fitted); R1206_ENKO
R21, R38, R44, R92: 1200970568**RES 0603 47K %5 1/10W; R0603_ENKO
R25, R26, R39, R40, R41, R42, R43: 1200970228**RES 1206 47R %5 1/4W; R1206_ENKO
R27, R30, R31, R33, R34: 1029-6109**RES 2512 33R %5 1W; R2512
R35, R69: 1029-3116**RES 0805 10R %5; R0805_ENKO
R36: 1200970117**RES 1206 0R %5; R1206_ENKO
R46, R87, R91, R99, R109, R114: 1200970518**RES 0603 10K %5 1/10W; R0603_ENKO
R47, R51, R54, R70, R82: 1200971020**RES 0603 10K %1 1/10W; R0603_ENKO
R48, R110: 1200970516**RES 0603 22K %5 1/10W; R0603_ENKO
R49, R52, R53: 1029-2005**RES 0603 220R %1; R0603_ENKO
R50, R57, R59, R76: 1200970803**RES 0603 100K %1 1/10W; R0603_ENKO
R55: 1029-2233**RES 0603 2K2 %1; R0603_ENKO
R56, R67, R68, R83, R84, R86, R95, R103, R104: 1200970522**RES 0603 1K %5 1/10W; R0603_ENKO
R58: 1200970770**RES 0603 4K3 %1 1/10W; R0603_ENKO
R62: 1200970706**RES 0603 1K8 %5 1/10W; R0603_ENKO
R63: 1029-2003**RES 0603 10R %1; R0603_ENKO
R64: 1029-2006**RES 0603 47R %1; R0603_ENKO
R65: 1029-6021**RES 2512 0R003 %1 2W; R2512
R66: 1200970927**RES 0603 100R %1 1/10W; R0603_ENKO
R71, R80, R88, R98, R134: 1029-2234**RES 0603 4K7 %1; R0603_ENKO
R73: 1169-1001**TSM2A103F3951RZ THINKING 0805 10K NTC 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; R0805_ENKO
R74: 1200970156**RES 1206 22K %5 1/4W; R1206_ENKO
R77: 1029-6089**RES 0603 6K8 %5; R0603_ENKO
R78: 1029-2203**RES 0603 12K %1; R0603_ENKO
R79: 1029-2341**RES 0603 5K6 %1; R0603_ENKO
R85: 1169-1006**FUSE SMD 1206 PTC RESETTABLE 16V IHOLD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; R1206_ENKO
R90: 1029-2231**RES 0603 1K8 %1; R0603_ENKO
R93: 1409-0025**RES 0603 470R %5 1/16W; R0603_ENKO
R94, R96, R97: 1029-6086**RES 0603 22R %1; R0603_ENKO
R100: 1200970852**RES 0603 1K5 %5 1/10W ( <-1029-3501 ); R0603_ENKO
R101: 1200970684**RES 0603 47K %1 1/10W; R0603_ENKO
R105: 1029-2229**RES 0603 120K %1; R0603_ENKO
R106: 1029-2219**RES 0603 30K %1; R0603_ENKO
R107: 1200970515**RES 0603 100K %5 1/10W; R0603_ENKO
R108: 1200970730**RES 0603 560R %1 1/10W; R0603_ENKO
R113: 1200970121**RES 0805 1K %5 1/8W; R0805_ENKO
R115: 1200970853**RES 1206 39K %1 1/4W; R1206_ENKO
R116: 1200970585**RES 0603 1M %5 1/10W; R0603_ENKO
R117: 1029-6015**RES 1206 56K %5; R1206_ENKO
R118, R119: 1029-6106**RES 2512 270mR %1 2W [ARGE?]; R2512
R133: 1200970626**RES 0603 82K %1 1/10W; R0603_ENKO
R135: 1200970940**RES 0603 6K8 %1 1/10W; R0603_ENKO
R193: 1200970934**RES 0603 470K %1 1/10W; R0603_ENKO
R194: 1200970528**RES 0603 0R %5 1/10W; R0603_ENKO
RL1: 1200930051**RELAY SPST 12V 5A 7x15x20.3mm; ALD1_AND_ALJ_RELAY
STENCIL: 041-7516**SDA381V2 için Çerçeveli Elek (Stencil) 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; PCB
T1: 1109-1016**Transistor NPN 3A 100V 15W Hfemin:10 D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; DPAK
T1_X, T4, T5, T6, T7, T9: 1200980090**TRANS SMD NPN BC847B SOT-23; SOT23
T3: 1200980091**TRANS SMD PNP BC857B SOT-23; SOT23-BEC
T10: 1049-1012**MMBTA56 PNP 80V 500mA 330mW hfe(min):1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; SOT23-BEC
TP1, TP4: PTR1TP20R; TP20R
TRF1: 0319-7452**SMPS TRAFO 150W E42/21/15 300uH DBC2 [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; DEIF_TRF
TVS1: 1119-3061**5V 130W TVS Diode SOD-323; SOD323
U1: 1039-2220**STM32F072C8T6 64K Flash USB, CAN; STM32F072CXXX_LQFP48
U2: 1039-2392**LMR16006XDDCR 0.6A, 0.7MHz Step-Down C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; AOZ1282CI-1
X1: 0289-1462**GMSTBA 2.5/ 3-G-7.62 (Phoenix 1766246); GMSTBA3
X2: 0309-1064**USB Type-B Mini Connector Horizantal; USB_B(YATIK)
X3: 0289-1460**MSTBA 2.5/ 4-G-5.08 (Phoenix 1757268); MSTBA4
X4: 0289-1464**MSTBA 2.5/ 3-G-5.08 (Phoenix 1757255); MSTBA3
XK1: 0289-1463**GMVSTBR 2.5/ 3-ST-7.62 (Phoenix 183253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; SOKET
XK3: 0289-1461**MVSTBR 2.5/ 4-ST-5.08 (Phoenix 1792265); SOKET
XK4: 0289-1465**MVSTBR 2.5/ 3-ST-5.08 (Phoenix 1792252); SOKET
Z1: 1129-1195**ZENER SOT23 18V 400mW %5 BZX84C18V; SOT23
Z2: NC**TAKILMAYACAK (Not Fitted); SOT23
Z4: 1129-1162**ZENER SOT23 3V9 300mW BZX84C3V9; SOT23
Z5, Z6: 1129-1145**ZENER SOT23 0.3W 15V BZX84C15; SOT23
Z7: 1129-1151**ZENER SOT23 12V 225mW BZX84C12; SOT23
Z8: 1129-1140**ZENER SOT23 5V1 0.4W BZX84C5V1; SOT23

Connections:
13.8V+: C18.P$1 (1), C24.P$1 (1), C36.1, C37.1, C40.+, C40.+1 (+), C42.+, C72.2, C73.1, C74.1, D7.A, L6.1, OC2.1, R50.1, R78.2, R117.1, TRF1.9 (12), TRF1.10 (13), TRF1.21 (13), TRF1.22 (12), TRF1.29 (12), TRF1.30 (13), TRF1.43 (12), TRF1.44 (13)
+3V3: C38.1, C39.1, C45.1, C48.1, C49.1, C51.1, C54.1, C55.1, C57.1, D13.2 (C), IC4.3 (OUT), IC5.8 (V+), LED1.2, PROG1.1 (+3V3), PROG2.1 (+3V3), R45.2, R46.1, R72.2, R100.2, R110.2, U1.24 (VDD.), U1.36 (VDDIO2), U1.48 (VDD)
AUX1: D1.A, R19.2, R20.2
BOOST_INP: C63.1, R91.1, TP1.TP, U1.15 (PA5)
CUT_OFF_OUTPUT: C71.1, D14.A, R110.1, U1.16 (PA6)
DRAIN1: C17.1, C17.3 (1), D4.A, Q1.D, TRF1.55 (1), TRF1.56 (1), TRF1.57 (1), TRF1.58 (1)
FB: C8.1, IC1.2 (FB), OC1.4, OC2.4
GATE1: IC8.GATE (G4), R107.1, R116.2, T7.3 (C), T9.3 (C), Z8.3 (C)
GND: B1.-, C6.2, C7.2, C8.2, C9.1, C10.-, C12.-, C13.-, C14.2, C15.2, C18.P$2 (2), C29.1, C59.2, C76.2, C82.2, IC1.4 (GND), OC1.3, OC2.3, R5.1, R10.1, R118.1, R119.1, TRF1.6 (7), TRF1.14 (7), TRF1.33 (7), TRF1.48 (8), TRF1.49 (7), Z1.1 (A)
GNDA: C20.-, C22.P$1 (1), C23.2, C26.2, C28.1, C30.1, C31.2, C32.2, C33.1, C34.1, C35.1, C36.2, C37.2, C38.2, C39.2, C40.-, C40.-1 (-), C41.2, C42.-, C43.1, C44.2, C45.2, C47.2, C48.2, C49.2, C51.2, C53.2, C54.2, C55.2, C57.2, C60.1, C61.2, C62.1, C63.2, C64.2, C65.1, C66.2, C67.2, C68.1, C69.1, C70.1, C72.1, C75.2, C78.2, C79.1, C84.-, C84_X.-, C85.2, C98.1, C110.1, D12.A1, D13.1 (A), D18.A, H2.1, H2.2, H2.3, H2.4, IC2.5 (5.TRIG), IC2.7 (7.GND), IC4.1 (GND), IC5.4 (V-), IC6.A (1), IC9.4 (V-), L2.1 (1.GND), L2.4 (4.GND), PROG1.3 (GND), PROG2.3 (GND), Q2.S, R25.2, R26.2, R38.2, R39.2, R40.2, R41.2, R42.2, R43.2, R44.2, R47.2, R48.2, R51.2, R56.1, R58.2, R64.1, R65.1, R68.1, R73.2, R75.1, R81.2, R82.2, R87.1, R90.1, R99.1, R102.1, R135.1, T5.2 (E), T6.2 (E), TRF1.6.1 (9), TRF1.6.2 (9), TRF1.6.5 (9), TRF1.7 (10), TRF1.24 (10), TRF1.27 (10), TRF1.40 (9), TRF1.41 (10), TVS1.A (1), U1.8 (VSSA), U1.23 (VSS..), U1.35 (VSS), U1.47 (VSS.), U2.2 (GND), X2.GND, X2.SHLD1 (1), X2.SHLD2 (2), X4.1, Z4.1 (A), Z6.1 (A)
GNDIO: D15.C, IC8.D (D5678), IC8.D1 (D5678), IC8.D2 (D5678), IC8.D3 (D5678), IC8.P$1 (D5678), IC8.P$2 (D5678), IC8.P$3 (D5678), R57.1, T10.E, X3.2
HV1: IC1.8 (HV), R12.2
I_FOR_REV_BAT_PROTEC: C50.2, IC5.3 (+IN), IC5.7 (OUT), R71.2, R109.2
I_OUT_ADC: C62.2, R83.2, U1.17 (PA7)
I_PWM: R55.2, U1.18 (PB0)
JTDO: PROG1.6 (PRG_SWO), PROG2.6 (PRG_SWO), U1.39 (PB3)
LED_B: R52.1, U1.41 (PB5)
LED_G: R53.1, U1.40 (PB4)
LED_R: R49.1, U1.42 (PB6)
unnamed: TRF1.1 (2), TRF1.2 (3), TRF1.17 (3), TRF1.18 (2), TRF1.36 (3), TRF1.37 (2), TRF1.53 (3), TRF1.54 (2)
unnamed: R63.1, R64.2
unnamed: Q2.G, R36.2, R38.1
unnamed: R30.2, R33.1, R34.1
unnamed: OC2.2, Z5.3 (C)
unnamed: D14.C, R112.2, R113.2, Z7.3 (C)
unnamed: B1.AC1, C4.2, C83.2, C83.4 (2), L1.4, L1.7 (4)
unnamed: R91.2, R92.2, R93.2, Z4.3 (C)
unnamed: R95.1, R99.2, T6.1 (B)
unnamed: D5.A, Q1.G, R14.1, R21.2
unnamed: R103.2, Z5.1 (A)
unnamed: IC6.R (2), R89.1, R90.2
unnamed: C19.1, R35.1
unnamed: C68.2, R103.1, R104.2
unnamed: C52.2, C56.2, IC3.7 (OUT), R74.1
unnamed: D11.A, R93.1
unnamed: D11.C, X4.3
unnamed: IC2.8 (8.DRV), R36.1
unnamed: R59.1, R60.1, T3.C
unnamed: C21.2, R25.1, R26.1, R39.1, R40.1, R41.1, R42.1, R43.1
unnamed: IC3.4 (CV-), R76.2, R79.1, R80.2
unnamed: C13.+, C29.2, R8.2, R13.1, T1.4 (C), T1_X.3 (C)
unnamed: C80.1, IC3.2 (CC-), R66.1, R70.2
unnamed: R94.1, X4.2
unnamed: L2.6, R96.1
unnamed: D2.C, R17.1, R18.1
unnamed: F1.2, F1_X1.P$2 (2), F1_X2.P$2 (2), F1_X3.P$2 (2), F1_X4.P$2 (2), F1_X5.P$2 (2), F1_X6.P$1 (1), X1.2
unnamed: C16.2, R19.1
unnamed: B1.AC2, C5.1, C83.1, C83.3 (1), L1.2, L1.6 (2)
unnamed: C17.2, C17.4 (2), R31.1
unnamed: C46.2, IC3.8 (VCC), R69.2
unnamed: C50.1, C81.1, IC5.6 (-IN), R68.2, R71.1
unnamed: C81.2, IC5.5 (+IN), R67.1
unnamed: C19.2, D6.A, R22.1
unnamed: R109.1, T7.1 (B)
unnamed: C10.+, R16.1, T1.3 (E), T1_X.2 (E)
unnamed: TP4.TP, U1.28 (PB15)
unnamed: IC2.2 (2.MIN_TOFF), R48.1
unnamed: D5.C, R14.2, R15.1
unnamed: C56.1, R76.1
unnamed: R78.1, R79.2, T4.3 (C)
unnamed: R81.1, T4.2 (E)
unnamed: IC1.5 (DRV), R15.2
unnamed: IC2.3 (3.MIN_TON), R47.1
unnamed: C60.2, R82.1, R84.2, T4.1 (B)
unnamed: C58.2, IC5.1 (OUT), R77.2, R83.1
unnamed: R54.1, R59.2, R61.1, T3.E
unnamed: LED1.1, R49.2
unnamed: C43.2, R60.2, R62.2
unnamed: C80.2, IC3.3 (CC+), R62.1, R63.2
unnamed: R54.2, R55.1, T3.B
unnamed: C58.1, IC5.2 (-IN), R75.2, R77.1
unnamed: R104.1, T6.3 (C), Z6.3 (C)
unnamed: D3.C, R23.1, R24.1
unnamed: R56.2, U1.44 (BOOT0)
unnamed: C46.1, C71.2, IC3.6 (GND), IC8.S (S123), IC8.S1 (S123), IC8.S2 (S123), R65.2, R66.2, R67.2, R80.1, R114.2, R116.1, T7.2 (E), T9.2 (E), Z7.1 (A), Z8.1 (A)
unnamed: C77.2, D18.C, L5.2 (1), U2.6 (LX)
unnamed: C77.1, R194.2
unnamed: R194.1, U2.1 (BS)
unnamed: R193.1, U2.4 (EN)
unnamed: R20.1, TRF1.5 (6), TRF1.15 (6), TRF1.34 (6), TRF1.50 (6)
unnamed: R31.2, R33.2, R34.2
unnamed: R22.2, TRF1.8 (11), TRF1.23 (11), TRF1.28 (11), TRF1.42 (11)
unnamed: RL1.S0, X3.4
unnamed: C1.2, C3.2, C3.4 (2), C3.6 (2), L1.3, L1.8 (3), NTC1.P$1 (1), NTC1.P$4 (1), R1.1, R2.1
unnamed: C2.2, C3.1, C3.3 (1), C3.5 (1), F1.1, F1_X1.P$1 (1), F1_X2.P$1 (1), F1_X3.P$1 (1), F1_X4.P$1 (1), F1_X5.P$1 (1), F1_X6.P$2 (2), L1.1, L1.5 (1), R1.2, R4.2
unnamed: R112.1, R115.1
unnamed: C21.1, IC2.6 (6.CS), Q2.D, TRF1.11 (14), TRF1.12 (15), TRF1.13 (16), TRF1.19 (15), TRF1.20 (14), TRF1.25 (16), TRF1.31 (14), TRF1.32 (15), TRF1.38 (16), TRF1.45 (14), TRF1.46 (15), TRF1.47 (16)
unnamed: C84.+, C84_X.+, C85.1, L6.2, X3.1
unnamed: R27.2, R30.1
unnamed: NTC1.P$2 (2), NTC1.P$3 (2), X1.1
unnamed: D15.A, R117.2, T10.B
unnamed: D4.C, R17.2, R18.2, R23.2, R24.2
unnamed: C31.1, C32.1, R45.1, U1.9 (VDDA)
unnamed: R2.2, R3.2
unnamed: R3.1, R4.1
unnamed: LED1.4, R52.2
unnamed: LED1.3, R53.2
unnamed: R9.1, R10.2
unnamed: R115.2, T10.C
unnamed: IC9.6 (-IN), R101.1, R102.2, R106.1
unnamed: D12.A, IC9.5 (+IN), R94.2, R98.1, R105.1
unnamed: R113.1, R114.1, T9.1 (B)
unnamed: IC9.7 (OUT), R105.2, R106.2, R108.1
unnamed: D10.A, RL1.1, T5.3 (C)
unnamed: R86.1, R87.2, T5.1 (B)
unnamed: L2.5, R97.1
unnamed: C65.2, IC6.C (3), IC9.3 (+IN), R88.1, R89.2
unnamed: IC9.1 (OUT), IC9.2 (-IN), R98.2, R101.2
unnamed: C16.1, D1.C, R13.2
unnamed: R11.1, R12.1
unnamed: C6.1, IC1.1 (FAULT), R5.2, Z2.1 (A)
unnamed: R133.1, R134.2
unnamed: L2.3, X2.D-
unnamed: L2.2, X2.D+
unnamed: C64.1, D9.1 (A1), D9.2 (A2), R85.1, TVS1.C (2)
unnamed: R7.2, R8.1
unnamed: R7.1, T1.1 (B), T1_X.1 (B), Z1.3 (C)
unnamed: C52.1, R70.1
NRST: C30.2, PROG1.5 (NRST), PROG2.5 (NRST), R46.2, U1.7 (NRST)
OSC1: C23.1, Q3.1, U1.5 (PF0/OSC_IN)
OSC2: C26.1, Q3.2, U1.6 (PF1/OSC_OUT)
OVER_VOLT: R95.2, U1.38 (PA15)
PE: C1.1, C2.1, C4.1, C5.2, C7.1, C11.1, C25.1, C27.1, C35.2, C59.1, C73.2, C74.2, C75.1, X1.3
PRI_SOURCE: C22.P$2 (2), C25.2, H1.1, H1.2, H1.3, H1.4, Q1.S, R6.2, R21.1, R27.1, R118.2, R119.2
PT100_ADC: C70.2, D13.3 (AC), R108.2, U1.11 (PA1)
REG_INP: C47.1, D8.C, D9.3 (C), IC4.2 (IN), IC4.4 (IN)
RELAY_OP: R86.2, U1.12 (PA2)
RES: C28.2, IC2.4 (4.LLD), R44.1
RL+: RL1.P0, RL1.P1, X3.3
SENSE: C9.2, IC1.3 (CS), R6.1
SWCLK: PROG1.2 (PRG_SWCLK), PROG2.2 (PRG_SWCLK), U1.37 (PA14)
SWDIO: PROG1.4 (PRG_SWDIO), PROG2.4 (PRG_SWDIO), U1.34 (PA13)
U3-K: OC1.2, R74.2
USB_DM: C66.1, R97.2, U1.32 (PA11)
USB_DP: C67.1, R96.2, R100.1, U1.33 (PA12)
VAUX_DC: C20.+, C110.2, D6.C, D7.C, R35.2, R193.2, U2.5 (VIN)
VAUX_PRI: C14.1, C15.1, IC1.6 (VCC), R16.2, Z2.3 (C)
VBAT_ADC: C44.1, R57.2, R58.1, U1.13 (PA3)
VBUS1: R85.2, X2.VBUS
VDC_BUS: B1.+, C11.2, C12.+, C24.P$2 (2), C27.2, C76.1, C82.1, D2.A, D3.A, R9.2, R11.2, TRF1.3 (4), TRF1.16 (4), TRF1.35 (4), TRF1.52 (4)
VOUT+_ADC: C41.1, R50.2, R51.1, U1.14 (PA4)
VREF2.1: IC3.1 (VREF), IC3.5 (CV+), R61.2
V_FB2: C78.1, R134.1, R135.2, U2.3 (FB)
V_NTC_ADC: C53.1, R72.1, R73.1, U1.10 (PA0)
V_PWM: R84.1, U1.19 (PB1)
V_SUPPLY: C33.2, C34.2, C61.1, C69.2, C79.2, C98.2, D8.A, D10.C, IC2.1 (1.VCC), IC9.8 (V+), L5.1 (2), OC1.1, R69.1, R88.2, R92.1, R107.2, R133.2, RL1.2

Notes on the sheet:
Rev. Bat. Protection
Over voltage protection
HV Protection
Regulation
BOOST INPUT
6K8

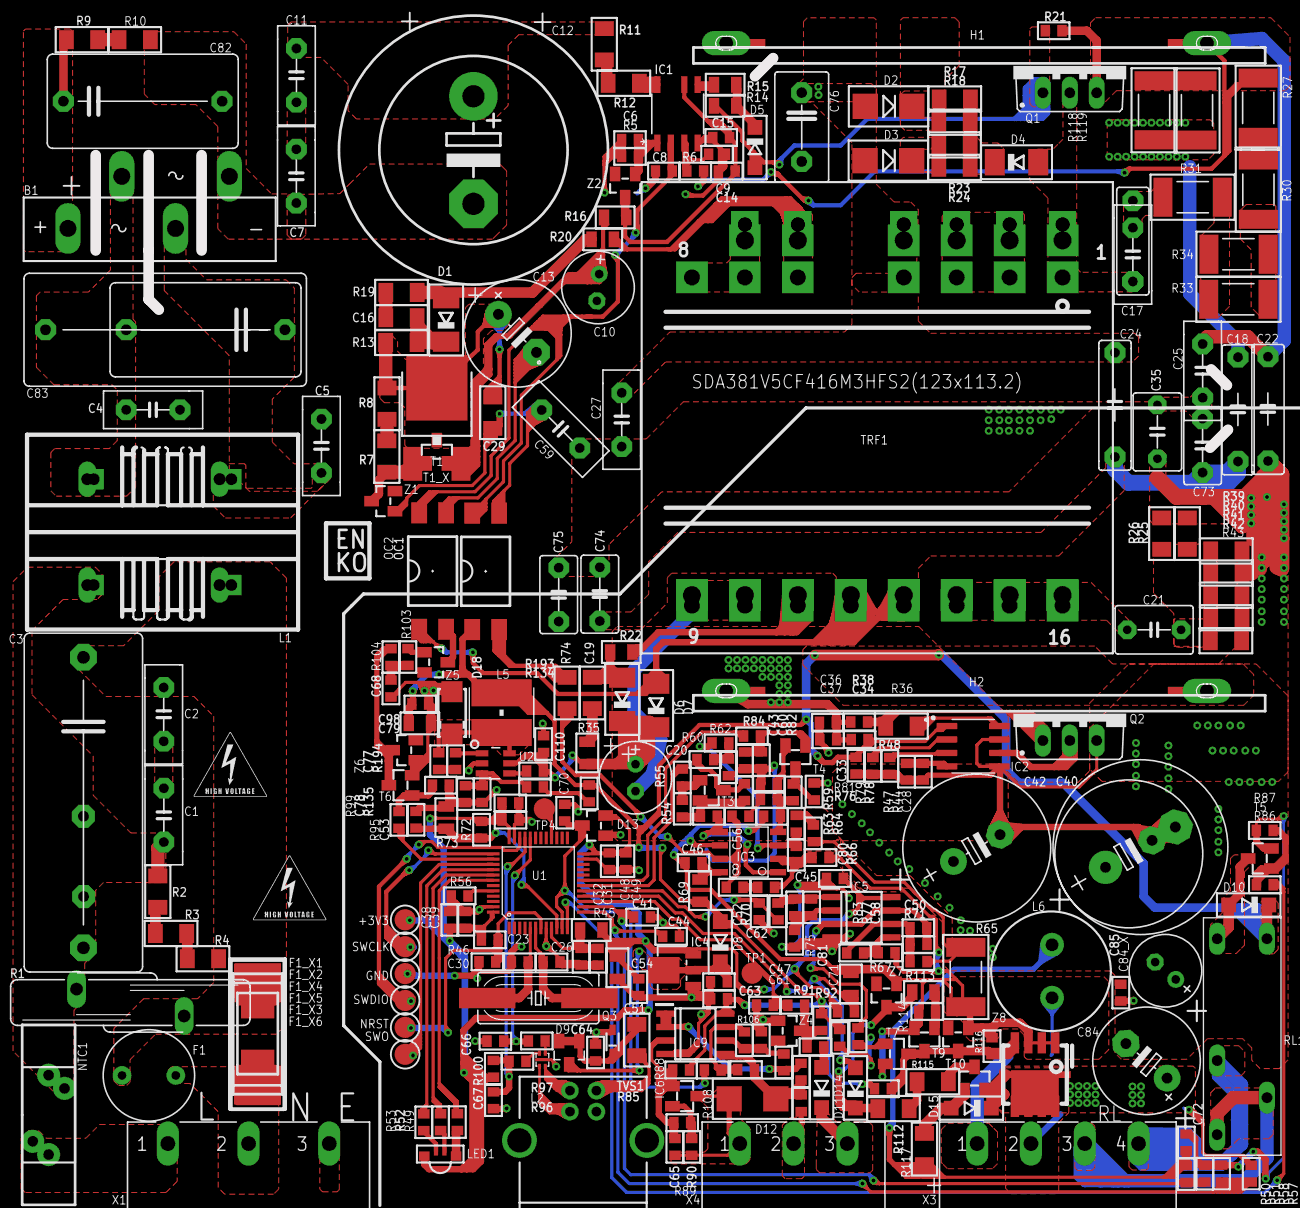
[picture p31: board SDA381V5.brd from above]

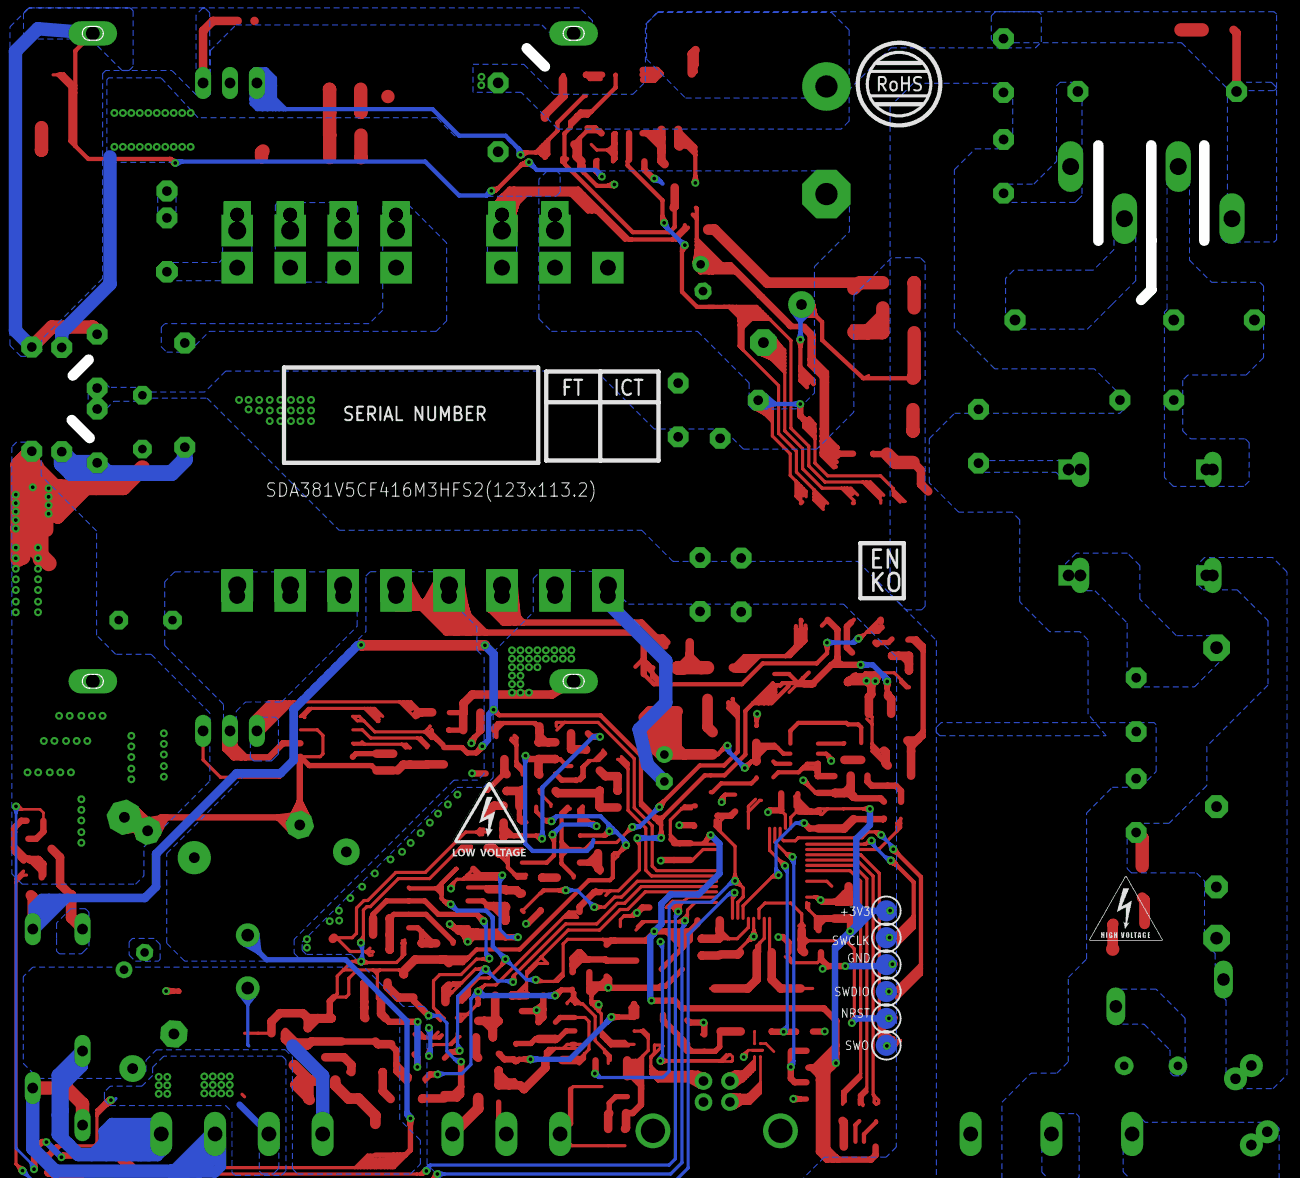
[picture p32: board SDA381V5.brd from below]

Board: 2 copper layers, 291 parts (5 on the bottom side), 146 nets.

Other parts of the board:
U$1: SERI_NO_ETIKET_ALANI
U$2, U$3: EN-KO_AMLEMI
U$4: ROHS
U$5: FT-ICT

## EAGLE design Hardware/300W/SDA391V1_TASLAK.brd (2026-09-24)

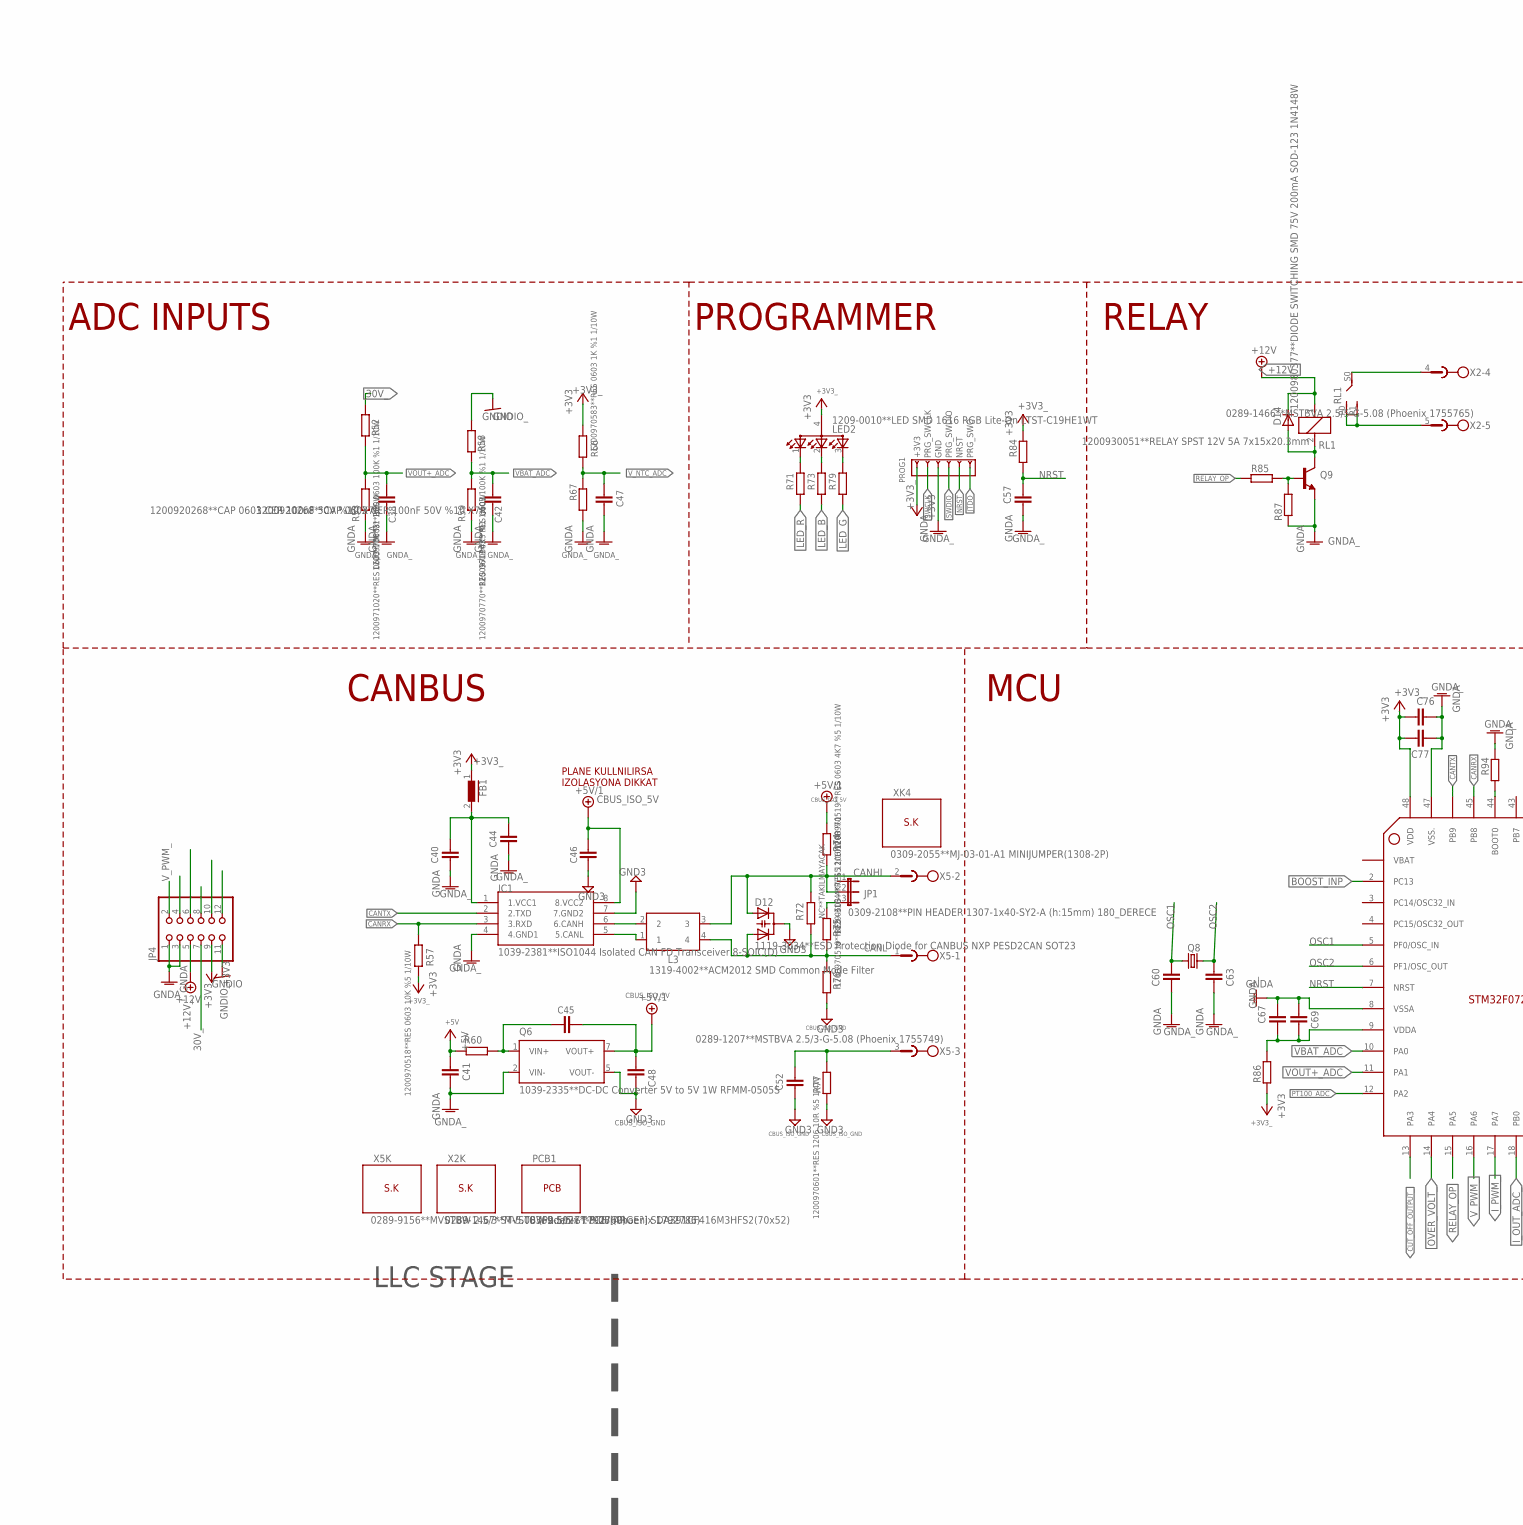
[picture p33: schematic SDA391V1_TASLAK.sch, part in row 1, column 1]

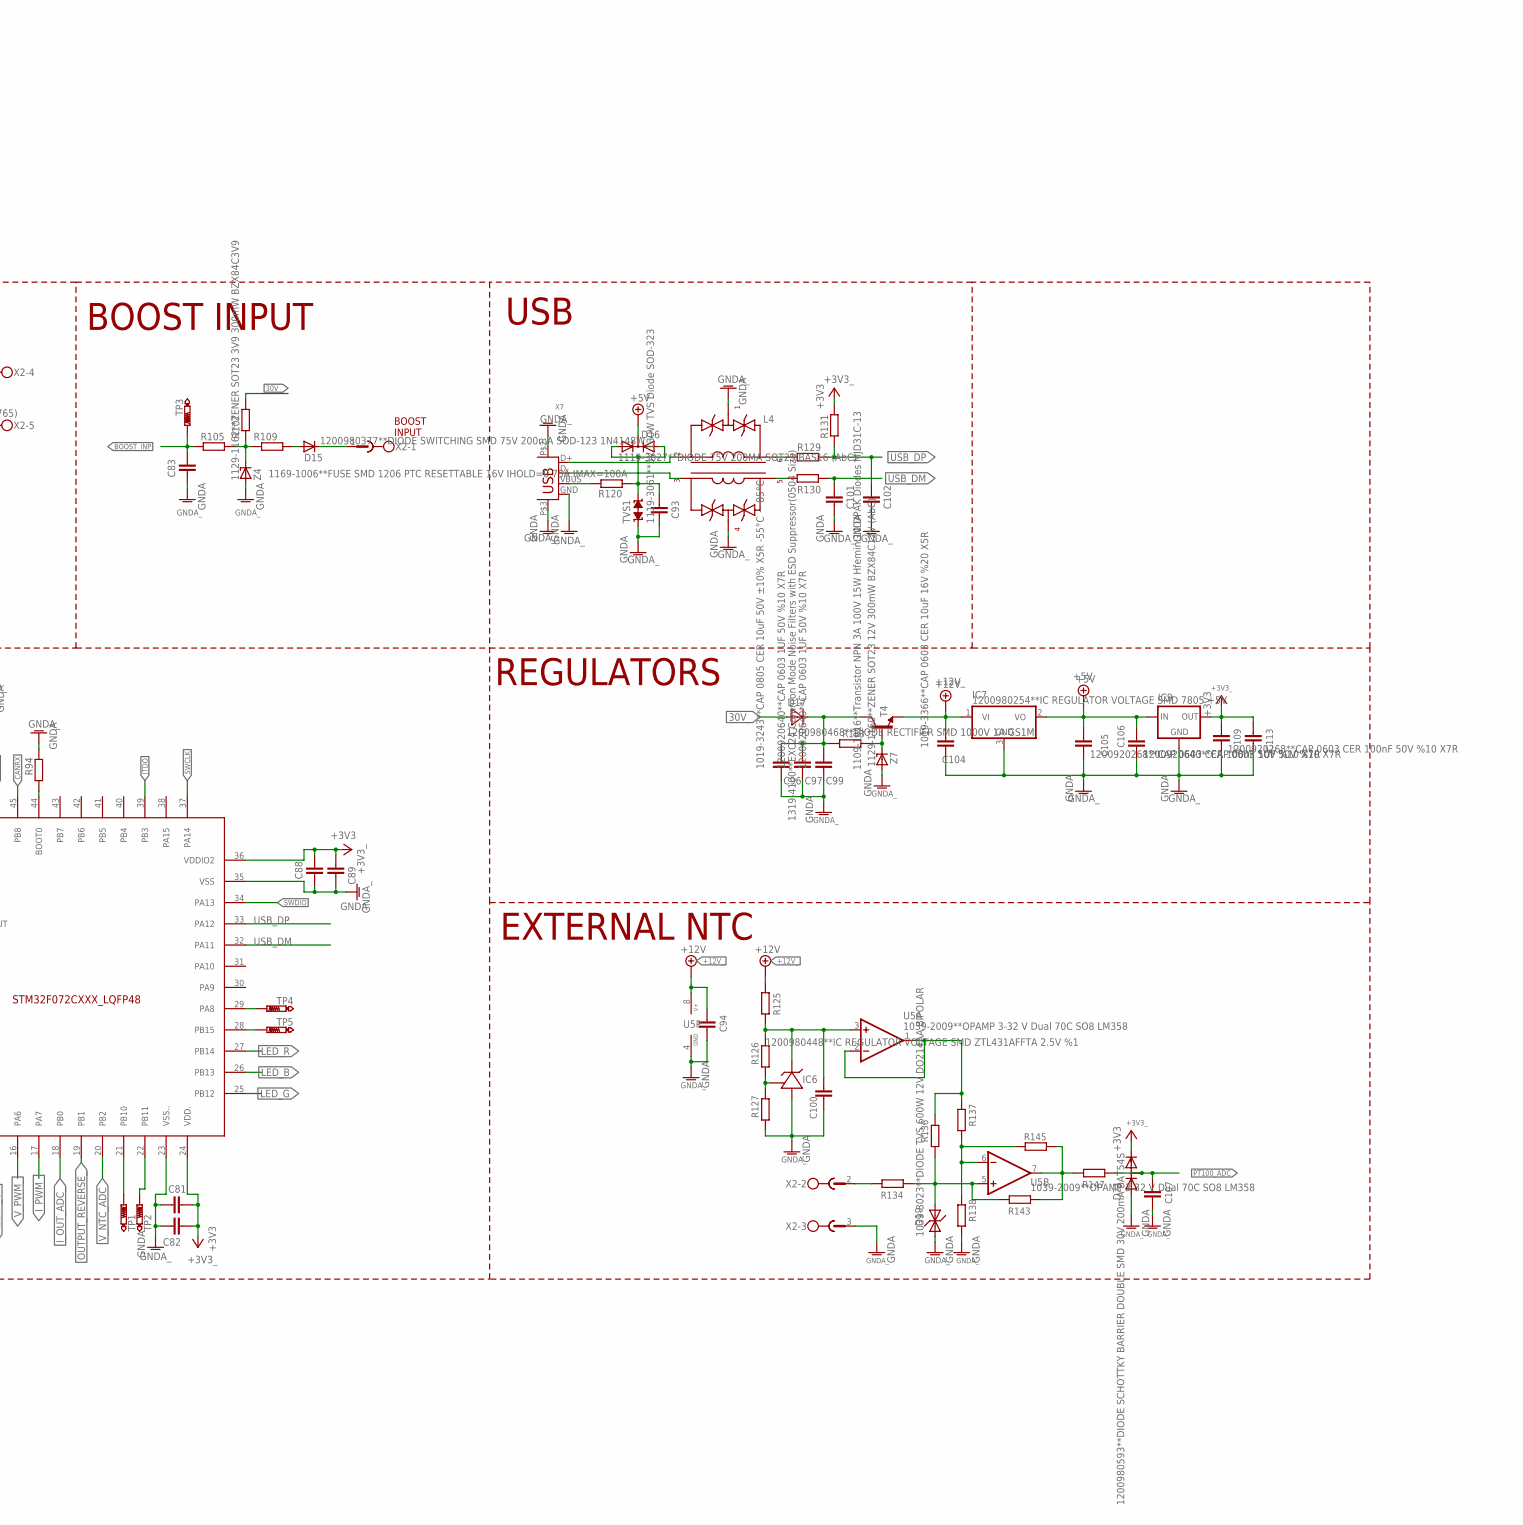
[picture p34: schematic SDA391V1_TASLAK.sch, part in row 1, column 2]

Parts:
C38, C42, C44, C46, C47, C57, C67, C76, C82, C89, C93, C94, C100, C105, C107, C109: 1200920268**CAP 0603 CER 100nF 50V %10 X7R; C0603_ENKO
C40, C52: 1200920253**CAP 0603 CER 10n 50V%10 X7R; C0603_ENKO
C41, C48: 1019-3362**CAP 0603 CER 2.2uF 10V %10 X5R; C0603_ENKO
C45: 0019-3020**CAP TH CER 470pF 3kV Y5P %10 85C F=7.5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; C050-055X075_SMALL
C60, C63: 1019-3352**CAP 0603 CER 22pF 50V %5 NPO; C0603_ENKO
C69, C77, C81, C83, C88: 1019-3167**CAP 0603 CER 10nF 50V %10 X7R (AbC); C0603_ENKO
C96: 1019-3243**CAP 0805 CER 10uF 50V ±10% X5R -55°C ~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; C0805_ENKO
C97, C99, C106: 1200920640**CAP 0603 1UF 50V %10 X7R; C0603_ENKO
C101, C102: 1019-3381**CAP 0603 CER 33pf 50V %5 NPO(COG); C0603_ENKO
C104, C113: 1019-3366**CAP 0603 CER 10uF 16V %20 X5R; C0603_ENKO
D12: 1119-3034**ESD Protection Diode for CANBUS NXP PE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; SOT23
D14, D15: 1200980377**DIODE SWITCHING SMD 75V 200mA SOD-123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; SOD123
D16: 1119-3027**DIODE 75V 200MA SOT23 BAS16 (AbC); SOT23
D17: 1200980468**DIODE RECTIFIER SMD 1000V 1A GS1M; M7_DC_DIYOT
D19: 1039-3023**DIODE TVS 600W 12V DO214AA BIPOLAR; TRANSIL_SMB
D21: 1200980593**DIODE SCHOTTKY BARRIER DOUBLE SMD 30V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; SOT23
FB1: 1319-4060**Ferrite Bead SMD 0805 2kOhm@100MHz 300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; FERRITE_BEAT_0805
IC1: 1039-2381**ISO1044 Isolated CAN FD Transceiver 8-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; ISO1044
IC6: 1200980448**IC REGULATOR VOLTAGE SMD ZTL431AFFTA 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; TL431_SOT23F
IC7: 1200980254**IC REGULATOR VOLTAGE SMD 7805 +5V; TO252
IC9: 1039-3003**Voltage Regulator SOT-89 3.3V Diodes A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; SOT89
JP1: 0309-2108**PIN HEADER 1307-1x40-SY2-A (h:15mm) 18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; JP2
JP4: PINHD-2X6_2.54; 2X06
L3: 1319-4002**ACM2012 SMD Common Mode Filter; ACM2012-900--2P-T002
L4: 1319-4100**EXC24 Common Mode Noise Filters with E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; EXC24CS_COMMON_MODE
LED2: 1209-0010**LED SMD 1616 RGB Lite-On LTST-C19HE1WT; CCS3210_RGB_LED
PCB1: 0369-5027**PCB [ARGE?] SDA391CF416M3HFS2(70x52); PCB
PROG1: NC**TAKILMAYACAK; PROG_6PIN
Q6: 1039-2335**DC-DC Converter 5V to 5V 1W RFMM-0505S; RFMM-0505S
Q8: 1149-0006**HC49S SMD KRISTAL 8MHZ -40+85 20PF 50P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; HC49UP
Q9: 1200980090**TRANS SMD NPN BC847B SOT-23; SOT23
R52, R58: 1200970803**RES 0603 100K %1 1/10W; R0603_ENKO
R53: 1200971020**RES 0603 10K %1 1/10W; R0603_ENKO
R57, R84, R87, R105: 1200970518**RES 0603 10K %5 1/10W; R0603_ENKO
R59: 1200970770**RES 0603 4K3 %1 1/10W; R0603_ENKO
R60: 1319-4025**INDUCTOR SMD 0805 4.7uH 500mA CL2012C-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; R0805_ENKO
R66, R126, R138: 1200970583**RES 0603 1K %1 1/10W; R0603_ENKO
R67: 1169-1001**TSM2A103F3951RZ THINKING 0805 10K NTC 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; R0805_ENKO
R71, R73, R79: 1029-2005**RES 0603 220R %1; R0603_ENKO
R72: NC**TAKILMAYACAK; R1206_ENKO
R74, R76: 1200970519**RES 0603 4K7 %5 1/10W; R0603_ENKO
R75: 1029-3164**RES 1206 120R %1; R1206_ENKO
R77: 1200970601**RES 1206 10R %5 1/4W; R1206_ENKO
R85, R94: 1200970522**RES 0603 1K %5 1/10W; R0603_ENKO
R86: 1319-4060**Ferrite Bead SMD 0805 2kOhm@100MHz 300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; R0805_ENKO
R107: 1200970568**RES 0603 47K %5 1/10W; R0603_ENKO
R109: 1409-0025**RES 0603 470R %5 1/16W; R0603_ENKO
R120: 1169-1006**FUSE SMD 1206 PTC RESETTABLE 16V IHOLD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; R1206_ENKO
R125, R136: 1029-2234**RES 0603 4K7 %1; R0603_ENKO
R127: 1029-2231**RES 0603 1K8 %1; R0603_ENKO
R129, R130, R134: 1029-6086**RES 0603 22R %1; R0603_ENKO
R131: 1200970852**RES 0603 1K5 %5 1/10W; R0603_ENKO
R133: 1200970121**RES 0805 1K %5 1/8W; R0805_ENKO
R137: 1200970684**RES 0603 47K %1 1/10W; R0603_ENKO
R143: 1029-2229**RES 0603 120K %1; R0603_ENKO
R145: 1029-2219**RES 0603 30K %1; R0603_ENKO
R147: 1200970730**RES 0603 560R %1 1/10W; R0603_ENKO
RL1: 1200930051**RELAY SPST 12V 5A 7x15x20.3mm; ALD1_AND_ALJ_RELAY
T4: 1109-1016**Transistor NPN 3A 100V 15W Hfemin:10 D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; DPAK
TP1, TP2, TP3, TP4, TP5: PTR1TP20R; TP20R
TVS1: 1119-3061**5V 130W TVS Diode SOD-323; SOD323
U4: 1039-2220**STM32F072C8T6 64K Flash USB, CAN; STM32F072CXXX_LQFP48
U5: 1039-2009**OPAMP 3-32 V Dual 70C SO8 LM358; SO08
X2: 0289-1466**MSTBVA 2.5/5-G-5.08 (Phoenix 1755765); MSTBV5
X2K: 0289-1467**MVSTBW 2.5/5-ST-5.08 (Phoenix 1792786); SOKET
X5: 0289-1207**MSTBVA 2.5/3-G-5.08 (Phoenix 1755749); MSTBV3
X5K: 0289-9156**MVSTBW 2.5/3-ST-5.08 (Phoenix 1792760); SOKET
X7: 0309-1065**USB Type-B Mini Connector Vertical; USB-BV
XK4: 0309-2055**MJ-03-01-A1 MINIJUMPER(1308-2P); SOKET
Z4: 1129-1162**ZENER SOT23 3V9 300mW BZX84C3V9; SOT23
Z7: 1129-1160**ZENER SOT23 12V 300mW BZX84C12V (AbC); SOT23

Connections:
5.CANL: IC1.5 (5.CANL), L3.1
30V_: D17.A, JP4.7, R52.1, R107.1
+3V3_: C76.1, C77.1, C81.1, C82.1, C88.1, C89.1, C109.1, C113.1, D21.2 (C), FB1.1, IC9.3 (OUT), JP4.9, LED2.4, PROG1.1 (+3V3), R57.2, R66.2, R84.1, R86.2, R131.2, U4.24 (VDD.), U4.36 (VDDIO2), U4.48 (VDD)
+5V: C41.1, C105.1, C106.1, D16.3 (C), IC7.2 (VO), IC9.2 (IN), R60.1
+12V_: C94.1, C104.1, D14.C, IC7.1 (VI), JP4.5, R125.2, RL1.1, T4.3 (E), U5.8 (V+)
BOOST_INP: C83.1, R105.1, TP3.TP, U4.2 (PC13)
CANHI: D12.1 (A1), JP1.2, L3.3, R72.2, R74.1, X5.2
CANL: D12.2 (A2), L3.4, R72.1, R75.1, R76.2, X5.1
CANRX: IC1.3 (3.RXD), R57.1, U4.45 (PB8)
CANTX: IC1.2 (2.TXD), U4.46 (PB9)
CBUS_ISO_5V: C45.2, C46.2, C48.1, IC1.8 (8.VCC2), Q6.7 (VOUT+), R74.2
CBUS_ISO_GND: C48.2, C52.2, IC1.7 (7.GND2), Q6.5 (VOUT-), R76.1, R77.2
CUT_OFF_OUTPUT_: JP4.6, U4.13 (PA3)
GND3: C46.1, D12.3 (C)
GNDA_: C38.2, C40.1, C41.2, C42.2, C44.1, C47.2, C57.1, C60.2, C63.2, C67.2, C69.2, C76.2, C77.2, C81.2, C82.2, C83.2, C88.2, C89.2, C93.2, C94.2, C96.2, C97.2, C99.2, C100.1, C101.2, C102.2, C104.2, C105.2, C106.2, C107.1, C109.2, C113.2, D19.A1, D21.1 (A), IC1.4 (4.GND1), IC6.A (1), IC7.3 (GND), IC9.1 (GND), JP4.1, JP4.3, L4.1 (1.GND), L4.4 (4.GND), PROG1.3 (GND), Q6.2 (VIN-), Q9.2 (E), R53.2, R59.2, R67.2, R87.1, R94.1, R127.1, R138.1, TVS1.A (1), U4.8 (VSSA), U4.23 (VSS..), U4.35 (VSS), U4.47 (VSS.), U5.4 (GND), X2.3, X7.GND, X7.P$2 (1), X7.P$3 (2), Z4.1 (A), Z7.1 (A)
GNDIO_: JP4.11, R58.1
I_OUT_ADC_: JP4.10, U4.18 (PB0)
I_PWM_: JP4.4, U4.17 (PA7)
JTDO: PROG1.6 (PRG_SWO), U4.39 (PB3)
LED_B: R73.1, U4.26 (PB13)
LED_G: R79.1, U4.25 (PB12)
LED_R: R71.1, U4.27 (PB14)
unnamed: L4.6, R129.1
unnamed: LED2.1, R71.2
unnamed: R105.2, R107.2, R109.2, Z4.3 (C)
unnamed: D15.A, R109.1
unnamed: D15.C, X2.1
unnamed: IC6.R (2), R126.1, R127.2
unnamed: R134.1, X2.2
unnamed: TP1.TP, U4.21 (PB10)
unnamed: R94.2, U4.44 (BOOT0)
unnamed: TP2.TP, U4.22 (PB11)
unnamed: TP5.TP, U4.28 (PB15)
unnamed: TP4.TP, U4.29 (PA8)
unnamed: C52.1, R77.1, X5.3
unnamed: JP1.3, R75.2
unnamed: IC1.6 (6.CANH), L3.2
unnamed: C45.1, Q6.1 (VIN+), R60.2
unnamed: C67.1, C69.1, R86.1, U4.9 (VDDA)
unnamed: LED2.2, R73.2
unnamed: LED2.3, R79.2
unnamed: R137.1, R138.2, R145.1, U5.6 (-IN)
unnamed: D19.A, R134.2, R136.1, R143.1, U5.5 (+IN)
unnamed: R143.2, R145.2, R147.1, U5.7 (OUT)
unnamed: D14.A, Q9.3 (C), RL1.2
unnamed: Q9.1 (B), R85.1, R87.2
unnamed: L4.5, R130.1
unnamed: C100.2, IC6.C (3), R125.1, R126.2, U5.3 (+IN)
unnamed: R136.2, R137.2, U5.1 (OUT), U5.2 (-IN)
unnamed: R133.1, T4.1 (B), Z7.3 (C)
unnamed: C96.1, C97.1, C99.1, D17.C, R133.2, T4.4 (C)
unnamed: L4.3, X7.D-
unnamed: L4.2, X7.D+
unnamed: C93.1, D16.1 (A1), D16.2 (A2), R120.1, TVS1.C (2)
unnamed: C40.2, C44.2, FB1.2, IC1.1 (1.VCC1)
NRST: C57.2, PROG1.5 (NRST), R84.2, U4.7 (NRST)
OSC1: C60.1, Q8.1, U4.5 (PF0/OSC_IN)
OSC2: C63.1, Q8.2, U4.6 (PF1/OSC_OUT)
OUTPUT_REVERSE_: JP4.12, U4.19 (PB1)
OVER_VOLT_: JP4.8, U4.14 (PA4)
PT100_ADC: C107.2, D21.3 (AC), R147.2, U4.12 (PA2)
RELAY_OP: R85.2, U4.15 (PA5)
RL+: RL1.P0, RL1.P1, X2.5
RL-: RL1.S0, X2.4
SWCLK: PROG1.2 (PRG_SWCLK), U4.37 (PA14)
SWDIO: PROG1.4 (PRG_SWDIO), U4.34 (PA13)
USB_DM: C101.1, R130.2, U4.32 (PA11)
USB_DP: C102.1, R129.2, R131.1, U4.33 (PA12)
VBAT_ADC: C42.1, R58.2, R59.1, U4.10 (PA0)
VBUS1: R120.2, X7.VBUS
VOUT+_ADC: C38.1, R52.2, R53.1, U4.11 (PA1)
V_NTC_ADC: C47.1, R66.1, R67.1, U4.20 (PB2)
V_PWM_: JP4.2, U4.16 (PA6)

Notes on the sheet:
LLC STAGE
AUXILIARY VOLTAGE REGULATOR
STM32G030F6P6
ISOLATION BARRIER
ISOLATED CONVERTER
BOOST INPUT
CANBUS
PLANE KULLNILIRSA IZOLASYONA DIKKAT
MCU
REGULATORS
EXTERNAL NTC
USB
BOOST INPUT
RELAY
PROGRAMMER
ADC INPUTS

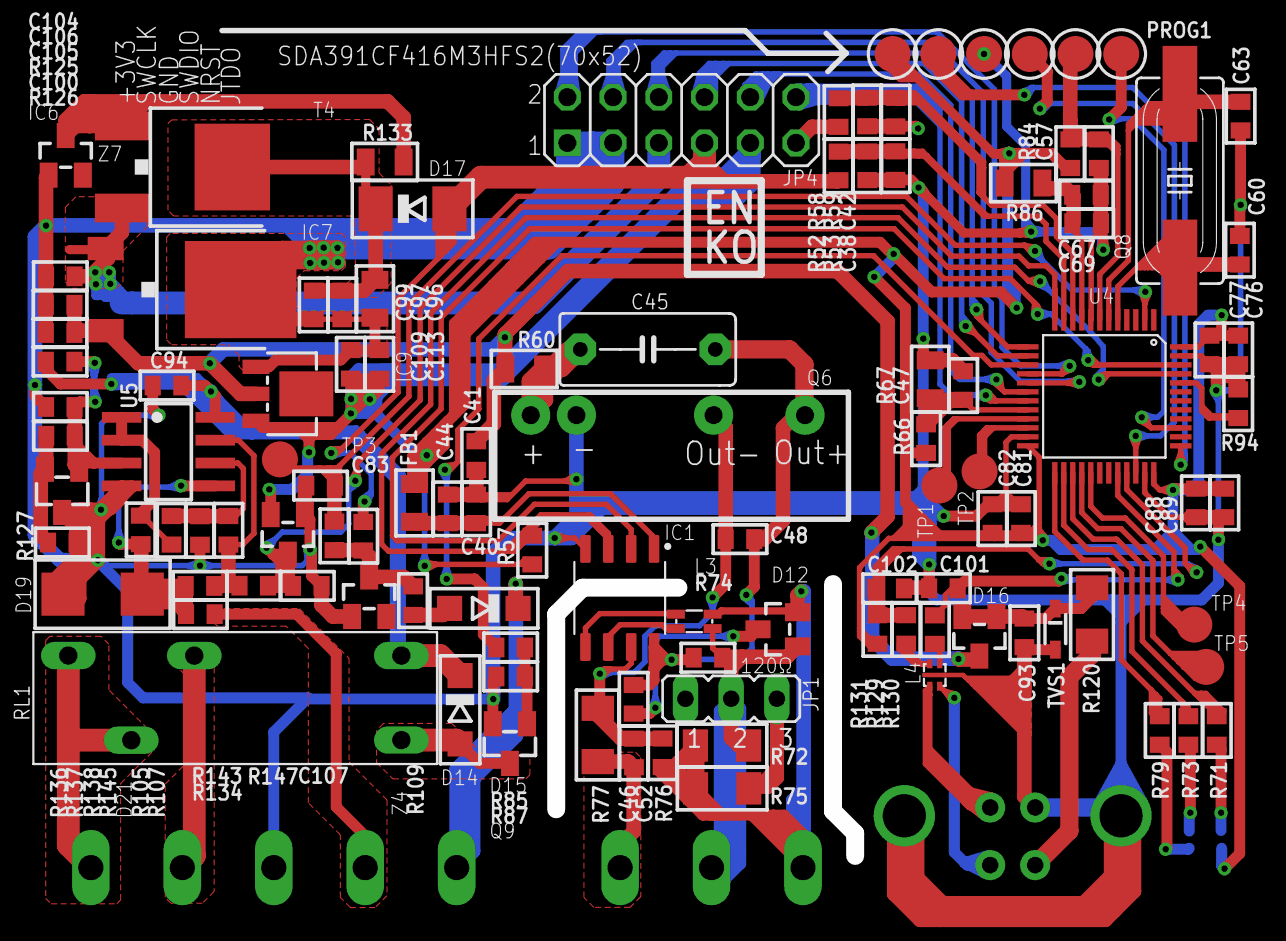
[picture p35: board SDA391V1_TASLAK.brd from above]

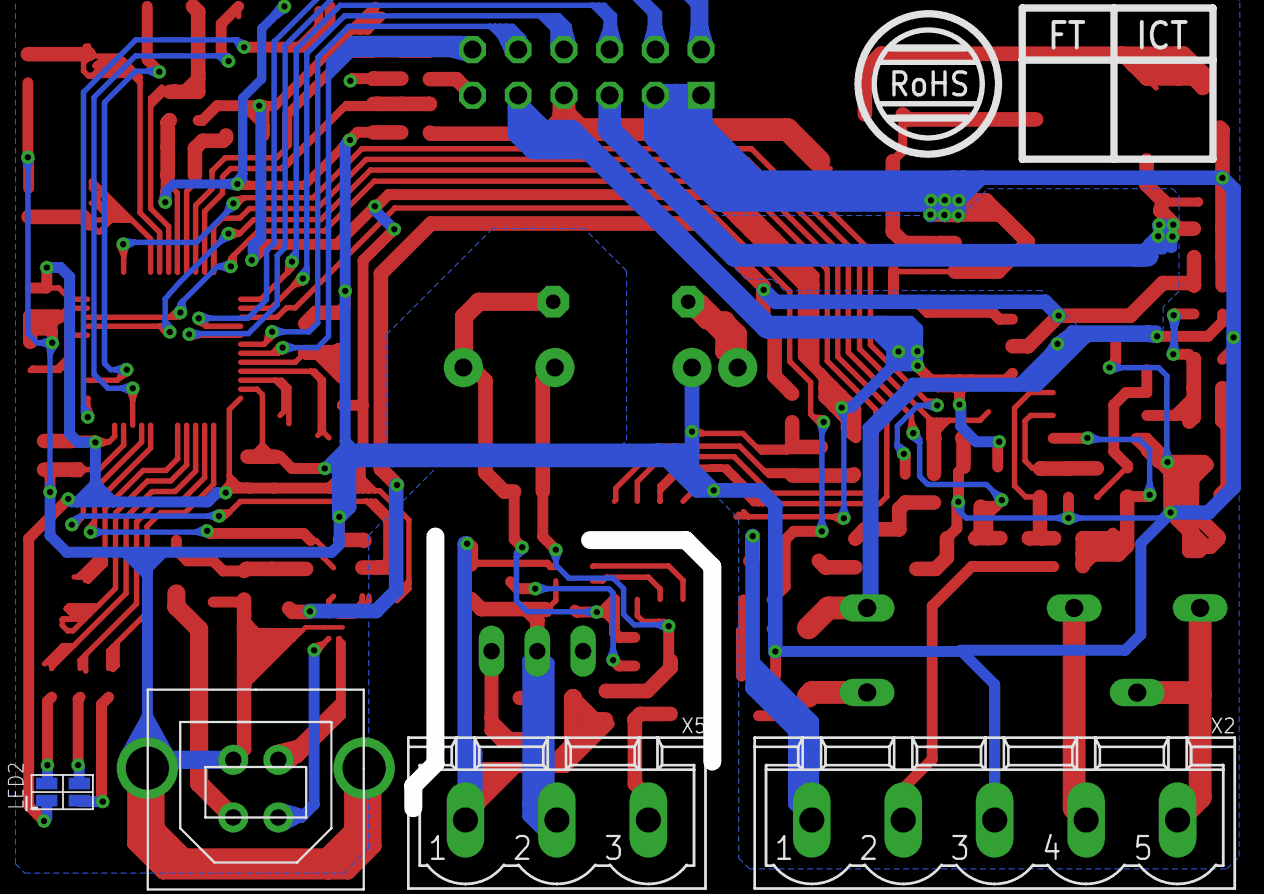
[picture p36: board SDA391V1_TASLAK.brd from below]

Board: 3 copper layers, 118 parts (6 on the bottom side), 73 nets.

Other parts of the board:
U$1: EN-KO_AMLEMI
U$2: ROHS
U$3: FT-ICT

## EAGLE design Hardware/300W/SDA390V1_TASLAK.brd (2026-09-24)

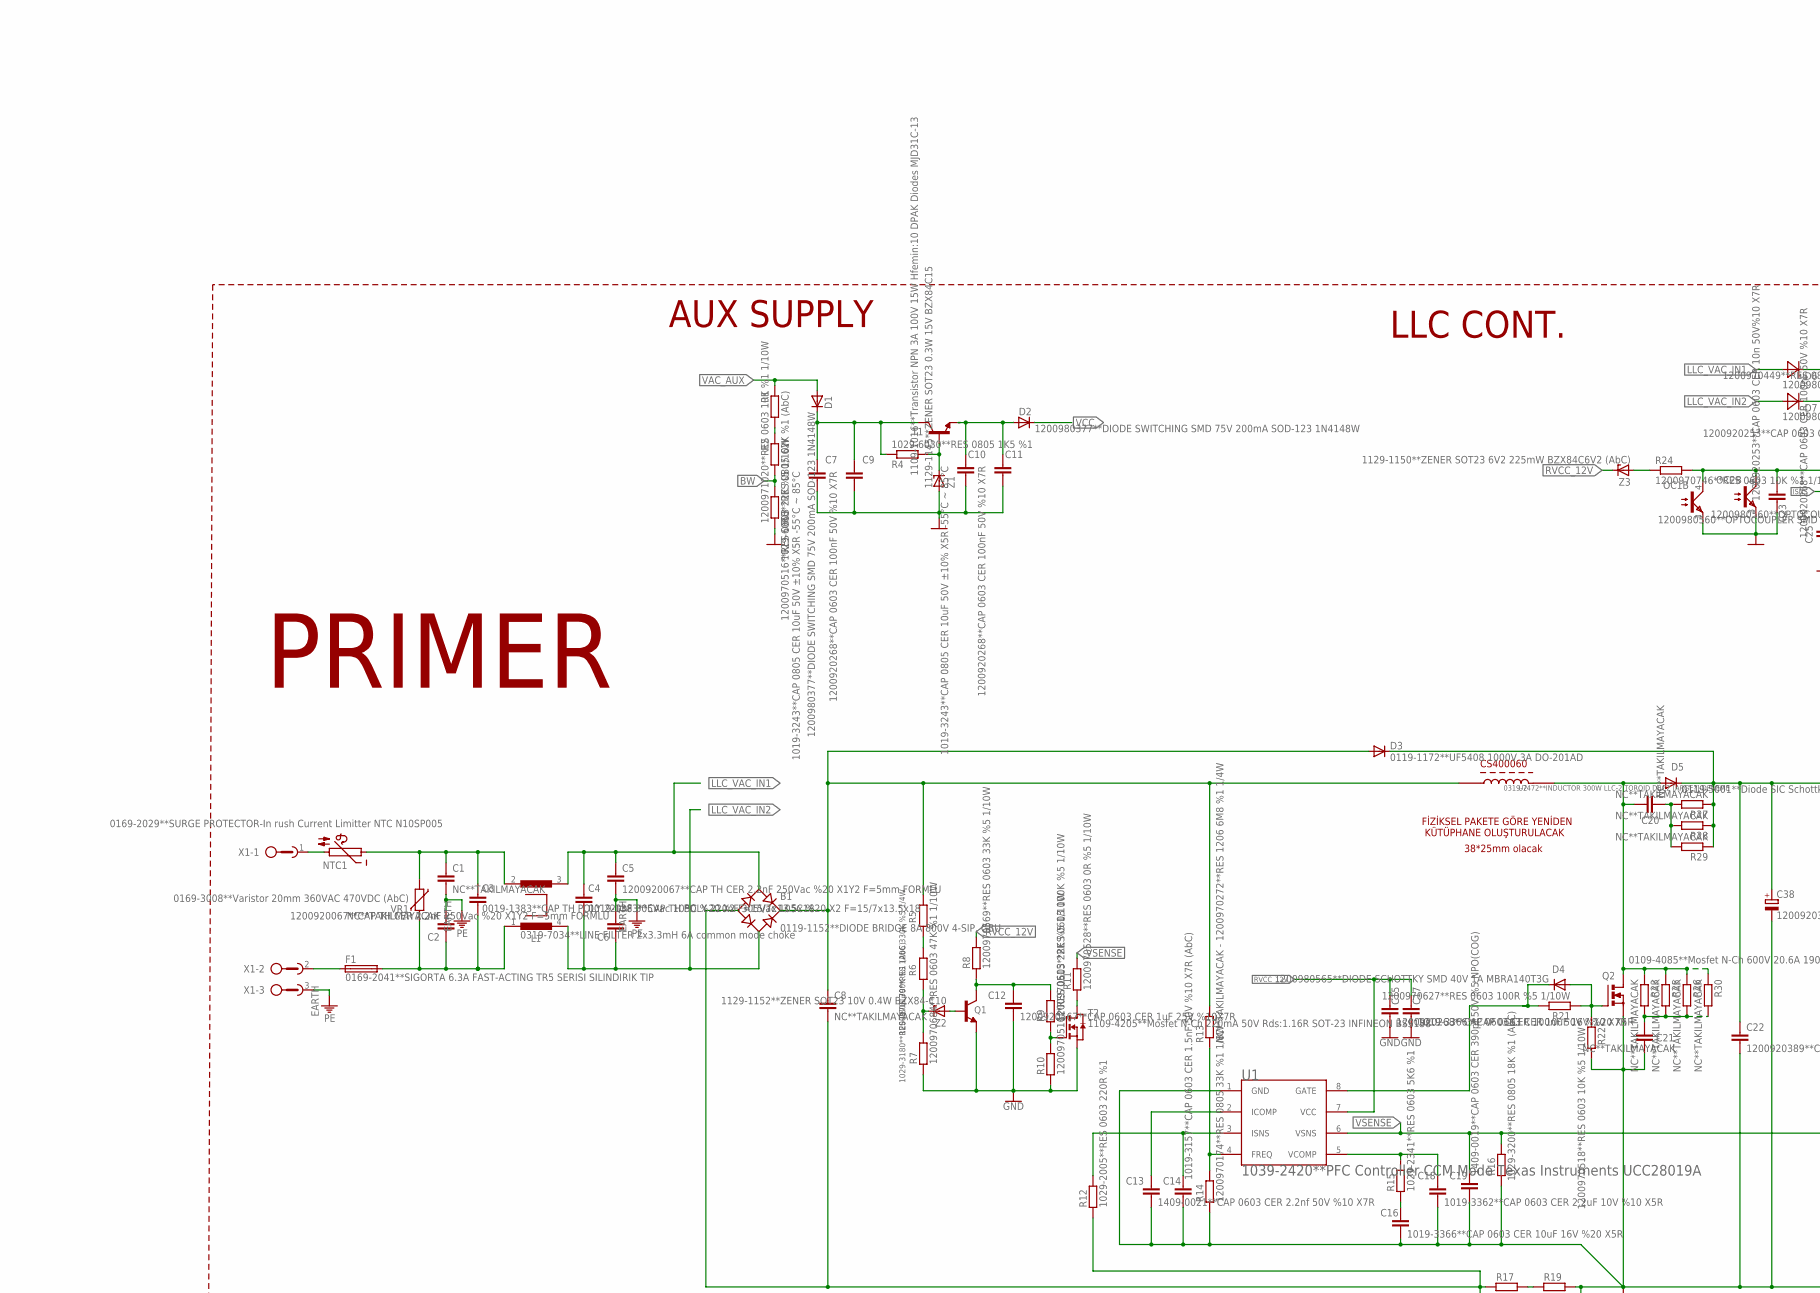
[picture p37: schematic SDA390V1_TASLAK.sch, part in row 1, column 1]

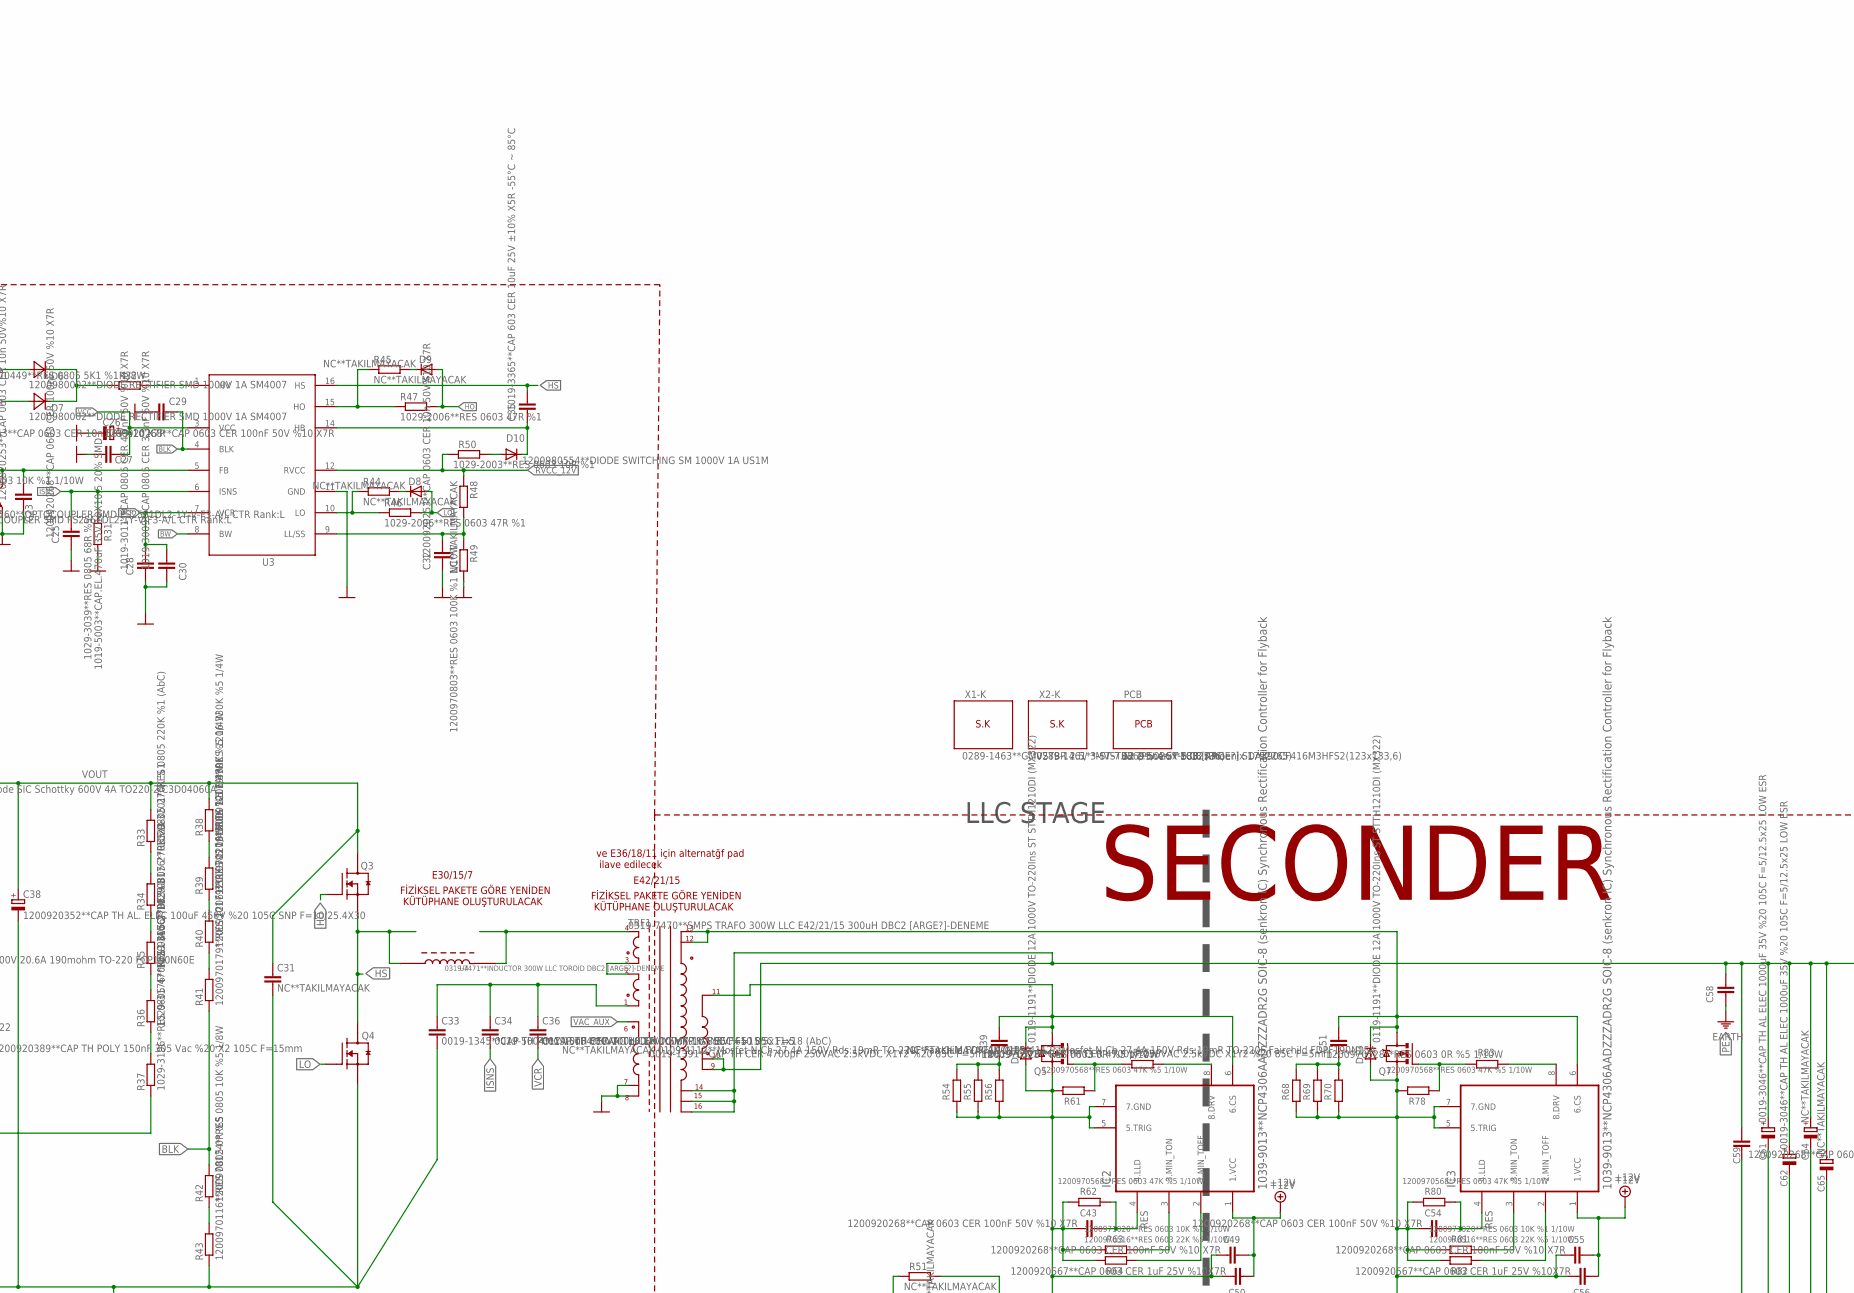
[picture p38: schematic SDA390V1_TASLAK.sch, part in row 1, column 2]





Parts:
B1: 0119-1152**DIODE BRIDGE 8A 800V 4-SIP, GBU; DıODE_BRIDGE_8A_DIK
C1, C2: NC**TAKILMAYACAK; C050-035X075
C3, C4: 0019-1383**CAP TH POLY 220nF 305Vac 105C %20 X2 F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; C150-064X183
C5, C6: 1200920067**CAP TH CER 2.2nF 250Vac %20 X1Y2 F=5m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; C050-035X075
C7, C10: 1019-3243**CAP 0805 CER 10uF 50V ±10% X5R -55°C ~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; C0805_ENKO
C8: NC**TAKILMAYACAK; C225-087X268
C9, C11, C15, C25, C27, C43, C49, C54, C55, C59, C73, C79, C80, C92, C95, C98, C103: 1200920268**CAP 0603 CER 100nF 50V %10 X7R; C0603_ENKO
C12, C50, C56, C74, C85: 1200920567**CAP 0603 CER 1uF 25V %10X7R; C0603_ENKO
C13: 1409-0021**CAP 0603 CER 2.2nf 50V %10 X7R; C0603_ENKO
C14: 1019-3157**CAP 0603 CER 1.5nF 50V %10 X7R (AbC); C0603_ENKO
C16, C17: 1019-3366**CAP 0603 CER 10uF 16V %20 X5R; C0603_ENKO
C18: 1019-3362**CAP 0603 CER 2.2uF 10V %10 X5R; C0603_ENKO
C19: 1409-0019**CAP 0603 CER 390pf 50V %5 NPO(COG); C0603_ENKO
C20, C21: NC**TAKILMAYACAK; C050-030X075
C22: 1200920389**CAP TH POLY 150nF 305 Vac %20 X2 105C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; C150-054X183
C23, C29, C32: 1200920253**CAP 0603 CER 10n 50V%10 X7R; C0603_ENKO
C24: NC**TAKILMAYACAK; C075-32X103_DEIF
C26: 1019-5003**CAP.EL.470uF 35V 10X10.5 20% SMD; 153CLV-1010
C28: 1019-3011**CAP 0805 CER 4.7nF 50V %10 X7R; C0603_ENKO
C30: 1019-3009**CAP 0805 CER 3.3nF 50V %10 X7R; C0603_ENKO
C31: NC**TAKILMAYACAK; C150-064X183
C33: 0019-1345**CAP TH POLY 10nF 600VAC 1000VDC MKP %5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; C150-072X183
C34: 0019-5004**CAP TH CER 100pF 1kV Y5V %10 85C F=5; C050-055X075
C35: 1019-3365**CAP 603 CER 10uF 25V ±10% X5R -55°C ~ 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; C0603_ENKO
C36: 0019-5004**CAP TH CER 100pF 1kV Y5V %10 85C F=5; C050-050X075
C38: 1200920352**CAP TH AL. ELEC 100uF 450V %20 105C S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; EB25D
C39, C51, C53: 0019-1391**CAP TH CER 4700pF 250VAC 2.5kVDC X1Y2 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; C050-045X075
C58: 1200920292**CAP TH CER 2.2nF 300Vac %20 X1Y2 F=7.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; C075-32X103/C050-035X75
C61, C62: 0019-3046**CAP TH AL ELEC 1000uF 35V %20 105C F=5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; E5-13/E7,5-16
C64, C65: NC**TAKILMAYACAK; E5-13/E7,5-16
C72: NC**TAKILMAYACAK; C0603_ENKO
C75: 1200920197**CAP 1206 CER 10uF 25V %10 X7R; C1206_ENKO
C78, C91: 1019-3387**CAP 0603 CER 10uF 10V %10 X5R; C0603_ENKO
C84: NC**TAKILMAYACAK (Not Fitted); C0603_ENKO
C86, C108: 1019-3167**CAP 0603 CER 10nF 50V %10 X7R (AbC); C0603_ENKO
C87: 1200920371**CAP 0603 CER 150p 50V%5 COG; C0603_ENKO
C90: NC**TAKILMAYACAK (Not Fitted); C050-035X075
C110, C111, C112: 0019-1391**CAP TH CER 4700pF 250VAC 2.5kVDC X1Y2 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; C050-035X075
D1, D2, D18, D20: 1200980377**DIODE SWITCHING SMD 75V 200mA SOD-123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; SOD123
D3: 0119-1172**UF5408 1000V 3A DO-201AD; DIODE_D0201-23
D4: 1200980565**DIODE SCHOTTKY SMD 40V 1A MBRA140T3G; SOD106-R
D5: 0119-5001**Diode SIC Schottky 600V 4A TO220-2 C3D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; DIODE_12A_1000V_TO220
D6, D7: 1200980002**DIODE RECTIFIER SMD 1000V 1A SM4007; M7_DC_DIYOT
D8, D9: NC**TAKILMAYACAK; SOD106-R
D10: 1200980554**DIODE SWITCHING SM 1000V 1A US1M; SOD106-R
D11, D13: 0119-1191**DIODE 12A 1000V TO-220Ins ST STTH1210D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; TO220ACS
F1: 0169-2041**SIGORTA 6.3A FAST-ACTING TR5 SERISI SI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; 19560
IC2, IC3: 1039-9013**NCP4306AADZZZADR2G SOIC-8 (senkron IC)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; NCP4306
IC4: 1039-2224**TSM1011ID SO-8 Constant Voltage and Co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; SO-8
IC5: 1039-2382**LMV358LIST 8-MiniSO Rail to Rail Opamp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; MSOP08
IC8: 1109-4211**Mosfet N-Ch 100V 90A Rds:3.7mR 8-SOP A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; TPH6R30ANL
JP5: PINHD-2X6_2.54; 2X06
L1: 0319-7034**LINE FILTER 2x3.3mH 6A common mode cho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; EPCOS_B82724J
NTC1: 0169-2029**SURGE PROTECTOR-In rush Current Limitt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; SENS_NTC
OC1, OC2: 1200980560**OPTOCOUPLER SMD PS2561DL2-1Y-V-F3-A/L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; PS2561DL2-1_OPTO1
PCB: 0369-5026**PCB [ARGE?] SDA390CF416M3HFS2(123x133,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; PCB
Q1, Q10, Q11, Q12, Q14: 1200980090**TRANS SMD NPN BC847B SOT-23; SOT23
Q2: 0109-4085**Mosfet N-Ch 600V 20.6A 190mohm TO-220 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; TO220BV
Q3, Q4: 0109-4091**Mosfet N-Ch 800V 9A 0.16R TO-220FP Vis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; ISO_TO_220
Q5, Q7: NC**TAKILMAYACAK 0109-4112**Mosfet N-Ch 27.4A 150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; TO220BV
Q13: NC**TAKILMAYACAK; SOT23
R1: 1029-6060**RES 0805 62K %1 (AbC); R0603_ENKO
R2, R10, R64, R82, R89, R135: 1200970516**RES 0603 22K %5 1/10W; R0603_ENKO
R3, R63, R81, R117: 1200971020**RES 0603 10K %1 1/10W; R0603_ENKO
R4: 1029-6030**RES 0805 1K5 %1; R0805_ENKO
R5, R38, R39, R40, R41: 1200970179**RES 1206 330K %5 1/4W; R1206_ENKO
R6: 1029-3180**RES 0805 300K %1 (AbC); R1206_ENKO
R7: 1200970684**RES 0603 47K %1 1/10W; R0603_ENKO
R8: 1200970569**RES 0603 33K %5 1/10W; R0603_ENKO
R9, R128: 1200970515**RES 0603 100K %5 1/10W; R0603_ENKO
R11, R65, R83, R112: 1200970528**RES 0603 0R %5 1/10W; R0603_ENKO
R12: 1029-2005**RES 0603 220R %1; R0603_ENKO
R13: NC**TAKILMAYACAK - 1200970272**RES 1206 6M8 %1 1/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; R1206_ENKO
R14: 1200970174**RES 0805 33K %1 1/8W; R0805_ENKO
R15, R114: 1029-2341**RES 0603 5K6 %1; R0603_ENKO
R16: 1029-3200**RES 0805 18K %1 (AbC); R0805_ENKO
R17, R19, R97: NC**TAKILMAYACAK; R2512
R18, R20, R98: 1029-6021**RES 2512 0R003 %1 2W; R2512
R21: 1200970627**RES 0603 100R %5 1/10W; R0603_ENKO
R22, R122, R142: 1200970518**RES 0603 10K %5 1/10W; R0603_ENKO
R23, R25, R26, R27, R28, R29, R30, R55, R69: NC**TAKILMAYACAK; R1206_ENKO
R24: 1200970746**RES 0603 10K %1 1/10W; R0603_ENKO
R31: 1029-3039**RES 0805 68R %5; R0603_ENKO
R32: 1200970449**RES 0805 5K1 %1 1/8W; R0805_ENKO
R33: 1029-3201**RES 0805 220K %1 (AbC); R0805_ENKO
R34, R35, R36: 1029-3176**RES 0805 270K %1; R0805_ENKO
R37: 1029-3196**RES 0805 470K %1 (AbC); R0805_ENKO
R42: 1200970124**RES 0805 10K %5 1/8W; R0805_ENKO
R43: 1200970116**RES 0805 0R %5; R0805_ENKO
R44, R45, R48, R139: NC**TAKILMAYACAK; R0603_ENKO
R46, R47: 1029-2006**RES 0603 47R %1; R0603_ENKO
R49, R90, R103, R110: 1200970803**RES 0603 100K %1 1/10W; R0603_ENKO
R50, R95, R102: 1029-2003**RES 0603 10R %1; R0603_ENKO
R51: NC**TAKILMAYACAK; 0207/15
R54, R56, R68, R70: 1029-4045**RES 1206 22R %5; R1206_ENKO
R61, R62, R78, R80: 1200970568**RES 0603 47K %5 1/10W; R0603_ENKO
R88: 1200970126**RES 0805 100K %1 1/8W; R0805_ENKO
R91, R92: 1200970120**RES 0805 1K %1 1/8W; R0805_ENKO
R93: 1200970706**RES 0603 1K8 %5 1/10W; R0603_ENKO
R96: 1029-3416**RES 0805 47R %1 (AbC) (MX322); R0805_ENKO
R99, R108, R116: 1200970583**RES 0603 1K %1 1/10W; R0603_ENKO
R100, R101, R118, R121, R123, R124, R132, R140, R141: 1200970522**RES 0603 1K %5 1/10W; R0603_ENKO
R104, R115: 1029-2234**RES 0603 4K7 %1; R0603_ENKO
R106: 1200970156**RES 1206 22K %5 1/4W; R1206_ENKO
R111: 1029-6089**RES 0603 6K8 %5; R0603_ENKO
R113: 1029-2203**RES 0603 12K %1; R0603_ENKO
R119: 1200970121**RES 0805 1K %5 1/8W; R0805_ENKO
R144: 1029-2337**RES 0603 39K %1; R0603_ENKO
R146: 1200970585**RES 0603 1M %5 1/10W; R0603_ENKO
R148: 1029-6015**RES 1206 56K %5; R1206_ENKO
T1: 1109-1016**Transistor NPN 3A 100V 15W Hfemin:10 D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; DPAK
T2: 1109-4205**Mosfet N-Ch 220mA 50V Rds:1.16R SOT-23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; SOT-23
T3: 1200980091**TRANS SMD PNP BC857B SOT-23; SOT23-BEC
T5: 1200980539**TRANS SM PNP NSS1C200LT1G SOT-23 100V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; SOT23-BEC
TRF1: 0319-7470**SMPS TRAFO 300W LLC E42/21/15 300uH DB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; DEIF_TRF_300W_2
U1: 1039-2420**PFC Controller CCM Mode Texas Instrume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; UCC28180
U2: 0319-7472**INDUCTOR 300W LLC-2 TOROID DBC2 [ARGE?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; IND_TOROID
U3: 1039-2421**LLC Controller Texas Instruments UCC25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; SOIC16_UCC256301
U4: 0319-7471**INDUCTOR 300W LLC TOROID DBC2 [ARGE?]-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; IND_TOROID
VR1: 0169-3008**Varistor 20mm 360VAC 470VDC (AbC); VITRA_VARISTOR
X1: 0289-1462**GMSTBA 2.5/ 3-G-7.62 (Phoenix 1766246); GMSTBA3
X1-K: 0289-1463**GMVSTBR 2.5/ 3-ST-7.62 (Phoenix 183253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; SOKET
X2-K: 0289-1461**MVSTBR 2.5/ 4-ST-5.08 (Phoenix 1792265); SOKET
X4: 0289-1460**MSTBA 2.5/ 4-G-5.08 (Phoenix 1757268); MSTBA4
Z1: 1129-1145**ZENER SOT23 0.3W 15V BZX84C15; SOT23
Z2, Z6: 1129-1152**ZENER SOT23 10V 0.4W BZX84-C10; SOT23
Z3, Z9: 1129-1150**ZENER SOT23 6V2 225mW BZX84C6V2 (AbC); SOT23
Z5: 1129-1163**ZENER SOT23 20V 400mW %5 BZX84C20V; SOT23
Z8: NC**TAKILMAYACAK; SOT23

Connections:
30V: C58.1, C58.3 (1), C59.1, C61.+, C61.+1 (+), C62.+, C62.+1 (+), C64.+, C64.+1 (+), C65.+, C65.+1 (+), C108.2, C110.1, C111.1, JP5.7, OC2.1, R112.2, R148.1, TRF1.6.1 (9), TRF1.6.2 (9), TRF1.6.5 (9), TRF1.7 (10), TRF1.11 (14), TRF1.12 (15), TRF1.13 (16), TRF1.19 (15), TRF1.20 (14), TRF1.24 (10), TRF1.25 (16), TRF1.27 (10), TRF1.31 (14), TRF1.32 (15), TRF1.38 (16), TRF1.40 (9), TRF1.41 (10), TRF1.45 (14), TRF1.46 (15), TRF1.47 (16), X4.3, X4.4
+3V3: C79.1, IC5.8 (V+), JP5.9, R135.2
+12V: C49.2, C50.2, C55.2, C56.2, C72.1, C73.1, C74.1, C75.1, C98.2, IC2.1 (1.VCC), IC3.1 (1.VCC), JP5.5, OC1.1, R102.1, R128.2
BLK: C29.2, R41.1, R42.2, U3.4 (BLK)
BW: R2.2, R3.2, U3.8 (BW)
CUT_OFF_OUTPUT: C103.1, D18.A, JP5.6, R135.1
GATE1: IC8.GATE (G4), Q12.3 (C), Q14.3 (C), R128.1, R146.2, Z9.3 (C)
GND: C7.1, C9.1, C10.1, C11.1, C12.2, C13.2, C14.2, C15.2, C16.2, C17.2, C18.2, C19.2, C21.1, C22.2, C23.2, C24.P$1 (1), C25.2, C26.-, C27.2, C28.2, C29.1, C30.2, C31.2, C32.2, C33.2, C38.-, OC1.3, OC2.3, Q1.2 (E), Q2.S, Q4.3 (S), R3.1, R7.1, R10.1, R14.1, R16.1, R19.2, R20.2, R22.2, R31.2, R43.1, R49.2, R51.1, T2.2 (S), TRF1.4 (8), TRF1.6 (7), TRF1.14 (7), TRF1.26 (8), TRF1.33 (7), TRF1.39 (8), TRF1.48 (8), TRF1.49 (7), U1.1 (GND), U3.11 (GND), Z1.1 (A)
GNDA: C72.2, C73.2, C74.2, C75.2, C78.1, C80.1, C90.2, C91.1, C92.1, C95.1, C98.1, C103.2, C108.1, IC4.6 (GND), IC8.S (S123), IC8.S1 (S123), IC8.S2 (S123), JP5.1, JP5.3, Q11.2 (E), Q13.2 (E), Q14.2 (E), R97.2, R98.2, R99.2, R100.2, R115.1, R116.1, R117.2, R122.1, R139.1, R142.2, R146.1, Z6.1 (A)
GNDIO: C112.2, D20.C, IC8.D (D5678), IC8.D1 (D5678), IC8.D2 (D5678), IC8.D3 (D5678), IC8.P$1 (D5678), IC8.P$2 (D5678), JP5.11, T5.E, X4.1, X4.2
HO: D9.A, Q3.1 (G), R47.2
HS: C35.1, Q3.3 (S), Q4.2 (D), U3.16 (HS), U4.1
ISNS: C25.1, C34.2, R31.1, U3.6 (ISNS)
I_FOR_REV_BAT_PROTEC: C84.2, IC5.3 (+IN), IC5.7 (OUT), R104.2, R132.2
I_OUT_ADC: C92.2, JP5.10, R118.2
I_PWM: JP5.4, R89.2
LLC_VAC_IN1: B1.AC1, C4.1, C5.1, D6.A, L1.3
LLC_VAC_IN2: B1.AC2, C4.2, C6.1, D7.A, L1.4
LO: D8.A, Q4.1 (G), R46.2
unnamed: R4.2, T1.1 (B), Z1.3 (C)
unnamed: R1.2, R2.1
unnamed: R39.1, R40.2
unnamed: R112.1, R113.2
unnamed: R95.1, R96.2
unnamed: F1.1, X1.2
unnamed: R24.1, Z3.1 (A)
unnamed: C85.2, C86.2, IC4.7 (OUT), R106.1
unnamed: C78.2, R91.2, R93.2
unnamed: R32.1, U3.1 (HV)
unnamed: R5.2, R6.1
unnamed: C35.2, D10.C, U3.14 (HB)
unnamed: IC4.3 (CC+), R93.1, R95.2
unnamed: R88.2, R89.1, T3.B
unnamed: Q10.3 (C), R113.1, R114.2
unnamed: IC4.4 (CV-), R110.2, R114.1, R115.2
unnamed: C32.1, R48.2, R49.1, U3.9 (LL/SS)
unnamed: IC4.2 (CC-), R99.1, R103.2
unnamed: C91.2, Q10.1 (B), R117.1, R119.2
unnamed: D6.C, D7.C, R32.2
unnamed: R123.2, Z5.1 (A)
unnamed: C95.2, R123.1, R124.2
unnamed: Q11.1 (B), R121.1, R122.2
unnamed: C7.2, C9.2, D1.C, R4.1, T1.4 (C)
unnamed: OC2.2, Z5.3 (C)
unnamed: Q12.1 (B), R132.1
unnamed: C87.2, IC5.1 (OUT), R111.2, R118.1
unnamed: C80.2, IC4.8 (VCC), R102.2
unnamed: C84.1, IC5.6 (-IN), R101.2, R104.1
unnamed: IC5.5 (+IN), R100.1
unnamed: C87.1, IC5.2 (-IN), R108.2, R111.1
unnamed: R40.1, R41.2
unnamed: R42.1, R43.2
unnamed: R38.1, R39.2
unnamed: D18.C, R140.2, R141.2
unnamed: C86.1, R110.1
unnamed: Q13.1 (B), R139.2, Z8.1 (A)
unnamed: TRF1.3 (4), TRF1.16 (4), TRF1.35 (4), TRF1.52 (4), U4.2
unnamed: Q10.2 (E), R116.2
unnamed: D10.A, R50.2
unnamed: C23.1, OC1.4, OC2.4, R24.2, U3.5 (FB)
unnamed: R45.1, R47.1, U3.15 (HO)
unnamed: R44.1, R46.1, U3.10 (LO)
unnamed: C33.1, C34.1, C36.1, TRF1.55 (1), TRF1.56 (1), TRF1.57 (1), TRF1.58 (1)
unnamed: R88.1, R90.2, R92.2, T3.E
unnamed: C14.1, R12.2, U1.3 (ISNS)
unnamed: R11.1, T2.1 (D)
unnamed: D4.A, Q2.G, R21.1, R22.1
unnamed: R13.1, R14.2, U1.4 (FREQ)
unnamed: C12.1, Q1.3 (C), R8.1, R9.2
unnamed: Q11.3 (C), R124.1, Z6.3 (C)
unnamed: TRF1.1 (2), TRF1.2 (3), TRF1.17 (3), TRF1.18 (2), TRF1.36 (3), TRF1.37 (2), TRF1.53 (3), TRF1.54 (2)
unnamed: C1.1, C3.1, L1.2, NTC1.P$1 (1), VR1.1
unnamed: C20.1, D5.A, Q2.D, R23.1, R25.1, R26.1, R30.1, U2.2
unnamed: R6.2, R7.2, Z2.3 (C)
unnamed: C16.1, R15.1
unnamed: C13.1, U1.2 (ICOMP)
unnamed: D9.C, R45.2
unnamed: Q5.G, R61.1, R65.2
unnamed: C20.2, R27.2, R28.2, R29.2
unnamed: C21.2, R23.2, R25.2, R26.2, R30.2
unnamed: IC2.2 (2.MIN_TOFF), R64.1
unnamed: D8.C, R44.2
unnamed: B1.+, C8.1, D3.A, R5.1, R13.2, U2.1
unnamed: R140.1, R144.1, Z8.3 (C)
unnamed: NTC1.P$2 (2), X1.1
unnamed: C18.1, R15.2, U1.5 (VCOMP)
unnamed: R90.1, R91.1, T3.C
unnamed: D20.A, R148.2, T5.B
unnamed: R33.1, R34.2
unnamed: R34.1, R35.2
unnamed: R35.1, R36.2
unnamed: R36.1, R37.2
unnamed: R144.2, T5.C
unnamed: IC2.3 (3.MIN_TON), R63.1
unnamed: Q14.1 (B), R141.1, R142.1
unnamed: IC2.8 (8.DRV), R65.1
unnamed: C39.2, R54.1, R55.1, R56.1
unnamed: C39.1, D11.C, IC2.6 (6.CS), Q5.D, TRF1.8 (11), TRF1.23 (11), TRF1.28 (11), TRF1.42 (11)
unnamed: R9.1, R10.2, T2.3 (G)
unnamed: Q1.1 (B), Z2.1 (A)
unnamed: B1.-, C8.2, R12.1, R17.1, R18.1
unnamed: Q7.G, R78.1, R83.2
unnamed: IC3.2 (2.MIN_TOFF), R82.1
unnamed: IC3.3 (3.MIN_TON), R81.1
unnamed: IC3.8 (8.DRV), R83.1
unnamed: C51.2, R68.1, R69.1, R70.1
unnamed: R18.2, R20.1
unnamed: R17.2, R19.1
unnamed: C51.1, D13.C, IC3.6 (6.CS), Q7.D, TRF1.9 (12), TRF1.10 (13), TRF1.21 (13), TRF1.22 (12), TRF1.29 (12), TRF1.30 (13), TRF1.43 (12), TRF1.44 (13)
unnamed: C85.1, R103.1
NEUTRAL: C2.1, C3.2, F1.2, L1.1, VR1.2
OUTPUT_REVERSE: JP5.12, Q13.3 (C)
OVER_VOLT: JP5.8, R121.2
PE: C1.2, C2.2, C5.2, C6.2, C53.2, C58.2, C58.4 (2), C90.1, C110.2, C111.2, C112.1, X1.3
Q1_GATE: D4.C, R21.2, U1.8 (GATE)
RES: C43.2, C54.2, IC2.4 (4.LLD), IC3.4 (4.LLD), R62.1, R80.1
RVCC_12V: C15.1, C17.1, R8.2, R48.1, R50.1, U1.7 (VCC), U3.12 (RVCC), Z3.3 (C)
S3: C24.P$2 (2), C43.1, C49.1, C50.1, C53.1, C54.1, C55.1, C56.1, C59.2, C61.-, C61.-1 (-), C62.-, C62.-1 (-), C64.-, C64.-1 (-), C65.-, C65.-1 (-), C79.2, D11.A, D13.A, IC2.5 (5.TRIG), IC2.7 (7.GND), IC3.5 (5.TRIG), IC3.7 (7.GND), IC5.4 (V-), Q5.S, Q7.S, Q12.2 (E), R51.2, R54.2, R55.2, R56.2, R61.2, R62.2, R63.2, R64.2, R68.2, R69.2, R70.2, R78.2, R80.2, R81.2, R82.2, R96.1, R97.1, R98.1, R101.1, R108.1, Z9.1 (A)
U3-K: OC1.2, R106.2
VAC_AUX: D1.A, R1.1, TRF1.5 (6), TRF1.15 (6), TRF1.34 (6), TRF1.50 (6)
VCC: C26.+, C27.1, D2.C, U3.3 (VCC)
VCR: C28.1, C30.1, C36.2, U3.7 (VCR)
VDC_AUX: C10.2, C11.2, D2.A, T1.3 (E)
VOUT: C22.1, C31.1, C38.+, D3.C, D5.K (C), Q3.2 (D), R27.1, R28.1, R29.1, R33.2, R38.2
VREF2.1: IC4.1 (VREF), IC4.5 (CV+), R92.1
VSENSE: C19.1, R11.2, R16.2, R37.1, U1.6 (VSNS)
V_PWM: JP5.2, R119.1

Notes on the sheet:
LLC STAGE
AUXILIARY VOLTAGE REGULATOR
STM32G030F6P6
ISOLATION BARRIER
ISOLATED CONVERTER
FİZİKSEL PAKETE GÖRE YENİDEN KÜTÜPHANE OLUŞTURULACAK
Rev. Bat. Protection
Over voltage protection
E30/15/7
E42/21/15
CS400060
ve E36/18/11 için alternatğf pad ilave edilecek
PRIMER
SECONDER
LLC CONT.
AUX SUPPLY
38*25mm olacak

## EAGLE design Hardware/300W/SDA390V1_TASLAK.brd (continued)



Board: 3 copper layers, 246 parts (3 on the bottom side), 127 nets.

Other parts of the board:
U$1, U$5: EN-KO_AMLEMI
U$2, U$4: ROHS
U$3: FT-ICT

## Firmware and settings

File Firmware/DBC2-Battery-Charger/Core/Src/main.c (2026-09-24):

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
/* Includes ------------------------------------------------------------------*/
#include "main.h"
#include "adc.h"
#include "can.h"
#include "dma.h"
#include "iwdg.h"
#include "tim.h"
#include "usb_device.h"
#include "gpio.h"

/* USER CODE BEGIN Includes */
#include "usbd_cdc_if.h"
#include "Controller.h"
#include "stm32f0xx_hal.h"

#include "ModbusServerSerial/msserial.h"
#include "ModbusClientSerial/mcserial.h"
#include "ModbusPDU/modbus_pdu.h"
#include "modbus_adapter_dma.h"
#include "modbus_adapter_usb.h"
#include "modbus_adapter_pdu.h"
#include "parameters_setget.h"
#include "parameter_callback.h"
#include "dynamic_pass_adapter.h"
/* USER CODE END Includes */

/* USER CODE BEGIN PD */
//bootloader defines
#define USER_PROG_BASLANGIC_ADR 0x08004800
#define SYSCFG_MemoryRemap_SRAM ((uint8_t)0x03)
//#define  RCC_APB2ENR_SYSCFGEN   ((uint32_t)0x00000001)        /*!< SYSCFG clock enable */
#define RCC_APB2Periph_SYSCFG   RCC_APB2ENR_SYSCFGEN
//DMA conv complete buffer size
#define DMA_BUFFER_SIZE         6
/* USER CODE END PD */


/* USER CODE BEGIN PV */

__attribute__((section(".SIGNATURESECTION.SGN"))) volatile const uint8_t signature[4] ={'E','N','K','O'};
__attribute__((section(".My_Vector_Table_Section.table")))  uint32_t VectorTable[50];
//volatile uint32_t *VectorTable = (uint32_t *)0x20000000; // Carve space here via linker script, or attributes

MEASURED_t MEASURED;
extern int16_t data[PARAM_MAX_COUNT];

volatile int64_t tick = 0, tempTick = 0;

ModbusServerSerial_t MbServerUsbObj;
ModbusPDU_t MbServerUsbObj_PDU;

uint32_t ledToggleCount = 0, ledOffset = 0, ledOffset_2 = 0;

uint8_t  boostLock = 0, pt100Flag = 0;
GPIO_PinState boostPinState = GPIO_PIN_SET;
uint32_t boostPinCounter = 0;

int16_t INTC_CAL1 = 0, INTC_CAL2  = 0;
int16_t PT100Comp = 0;
int16_t CalibINTC = 0;

volatile uint16_t ADC_Buffer[6] = {0, 0, 0, 0, 0, 0};
volatile uint16_t DMA_Buffer[DMA_BUFFER_SIZE];

extern ControllerParam_t outputReferences;

ALG_STATES mode = S_PSU;

uint8_t tagCount = 0;

extern USBD_HandleTypeDef hUsbDeviceFS;
/* USER CODE END PV */

void SystemClock_Config(void);
/* USER CODE BEGIN PFP */

void sysTickCallback(void);
HAL_StatusTypeDef Flash_writeReferencesToFlash(void);
HAL_StatusTypeDef Flash_readReferencesFromFlash(void);
void setDeviceParams(void);
/* USER CODE END PFP */

/**
  * @brief  The application entry point.
  * @retval int
  */
int main(void)
{
  /* USER CODE BEGIN 1 */
	// Vektor tablosu tasıma
  for(uint8_t i = 0; i < 48; i++){
		VectorTable[i] = *(__IO uint32_t*)(USER_PROG_BASLANGIC_ADR + (i<<2));
	}
	// Enable the SYSCFG peripheral clock//
	RCC_APB2PeriphResetCmd(RCC_APB2Periph_SYSCFG, ENABLE);
	// Remap SRAM at 0x00000000 //
	SYSCFG_MemoryRemapConfig(SYSCFG_MemoryRemap_SRAM);
	if(signature[0]==1)  // optimize etmemesi için eklendi.
	__NOP();
  /* USER CODE END 1 */

  /* MCU Configuration--------------------------------------------------------*/

  /* Reset of all peripherals, Initializes the Flash interface and the Systick. */
  HAL_Init();

  /* Configure the system clock */
  SystemClock_Config();

  /* Initialize all configured peripherals */
  MX_GPIO_Init();
  MX_DMA_Init();
  MX_ADC_Init();
  MX_USB_DEVICE_Init();
  MX_TIM14_Init();
  MX_CAN_Init();
//  MX_TIM1_Init();
//  MX_TIM2_Init();
  MX_TIM3_Init();
  MX_IWDG_Init();
  /* USER CODE BEGIN 2 */
//  HAL_GPIO_WritePin(CUT_OFF_OUTPUT_GPIO_Port, CUT_OFF_OUTPUT_Pin, GPIO_PIN_RESET);
//  HAL_GPIO_WritePin(LED_R_GPIO_Port,LED_R_Pin, GPIO_PIN_RESET);
//  while(1);

  #ifdef DBC_2_150W
  MX_TIM3_Init();
  #endif
#ifdef DBC_2_150W_2
MX_TIM3_Init();
#endif
  #ifdef DBC_2_300W
  MX_TIM1_Init();
  MX_TIM2_Init();
  #endif

  #ifndef DEBUG_MODE_OPTIONS
  FLASH_OBProgramInitTypeDef OBInit;
  // Get current status of the OB
  HAL_FLASHEx_OBGetConfig(&OBInit);
  //If it is not LEVEL 1 protected, set it. Else just ignore.
  if(OBInit.RDPLevel != OB_RDP_LEVEL_1){
    //Unlock OB
    HAL_FLASH_Unlock();
    HAL_FLASH_OB_Unlock();
    // Set Protection Level 1. This Level means no read operation but OB can be change in exchange of mass erase.
    // LEVEL 2 means no change on OB
    OBInit.OptionType = OPTIONBYTE_RDP;
    OBInit.RDPLevel = OB_RDP_LEVEL_1;
    // Change OB
    HAL_FLASHEx_OBProgram(&OBInit);
    // Launch means restart MCU
    HAL_FLASH_OB_Launch();
  }
  //Lock OB
  HAL_FLASH_OB_Lock();
  HAL_FLASH_Lock();
  #endif
	//Start ADC and DMA peripherals
	HAL_ADCEx_Calibration_Start(&hadc);
	HAL_ADC_Start_DMA(&hadc, (uint32_t*)DMA_Buffer, DMA_BUFFER_SIZE);

  	// USB uzerinden MultiWrite fonksiyonu maksimum 27register icin gerceklesebilir.
	// USB Composite kurulumu yapilmaktadir. USB-CDC ve USB-MSC
	ModbusAdapterUsbInit();
	modbusServerSerialSoftInit(&MbServerUsbObj, &MbServerUsbObj_PDU);
	modbusServerSerialLLInit(&MbServerUsbObj, ModbusAdapterTransmitterUsb,
			ModbusAdapterReceiverUsb, ModbusAdapterReceiverStopUsb, isModbusAdapterTransmitUSBDone);
	ModbusPDUInit(&MbServerUsbObj_PDU, ModbusPDUAdapterWrite, ModbusPDUAdapterRead, ModbusPDUAdressCheck);
	setModbusServerSerialSlaveAddress(&MbServerUsbObj, 1);
	setModbusServerSerialControlInterval(&MbServerUsbObj, 1 * 2);
	setModbusServerSerialWait(&MbServerUsbObj, 10);

	//Init dynamic password
	setDynamicPasswordSetup(getDynamicPasswordObj());

	//load default parameters from ROM. Used till Flash read
	for(uint16_t i = 1; i < PARAM_MAX_COUNT; i++){
		data[i - 1] = getParamDefViaPN(i);
	}
	//Read from Flash and decide to use fixed PWM or controller
//	Flash_writeReferencesToFlash();
    Flash_readReferencesFromFlash();
    outputReferences.REFCurrent = getParamDataViaPN(OUTPUT_CURRENT);
	if(getParamDataViaPN(PWMFLAG) == 0){
	  setCurrentPWMtoRef(&outputReferences);
	  setVoltagePWMtoRef(&outputReferences);
	}else if(getParamDataViaPN(PWMFLAG) == 1){
	Voltage_PWM = getParamDataViaPN(VOUTPWM);
    updateVPWMLimits();
	Current_PWM = getParamDataViaPN(IOUTPWM);
    updateIPWMLimits();
	}

	setParamDataViaPN(DEVICE_SOFTWARE_VER, 1090, CALLBACK_OFF);

  // Set ENKO Constant MB params for this device
  setDeviceParams();
#ifdef DBC_2_90W
  //Start TIM3 and PWM outputs according to references above
  TIM3->ARR  = 959;
  TIM3->PSC  = 0;
  HAL_TIM_PWM_Start(&htim3, I_PWM_CH); //I_PWM
  HAL_TIM_PWM_Start(&htim3, V_PWM_CH); //V_PWM
#endif
#ifdef DBC_2_150W
	//Start TIM3 and PWM outputs according to references above
	TIM3->ARR  = 959;
	TIM3->PSC  = 0;
	HAL_TIM_PWM_Start(&htim3, I_PWM_CH); //I_PWM
	HAL_TIM_PWM_Start(&htim3, V_PWM_CH); //V_PWM
#endif
#ifdef DBC_2_150W_2
  //Start TIM3 and PWM outputs according to references above
  TIM3->ARR  = 959;
  TIM3->PSC  = 0;
  HAL_TIM_PWM_Start(&htim3, I_PWM_CH); //I_PWM
  HAL_TIM_PWM_Start(&htim3, V_PWM_CH); //V_PWM
#endif
#ifdef DBC_2_300W
	TIM2->ARR  = 959;
	TIM2->PSC  = 0;
	HAL_TIM_PWM_Start(&htim2, I_PWM_CH); //I_PWM
	HAL_TIM_PWM_Start(&htim2, V_PWM_CH); //V_PWM
	HAL_TIM_PWM_Stop(&htim1, TIM_CHANNEL_3);
#endif

	//Start TIM14 interrupt to control LEDs
	TIM14->ARR = 59999;
	TIM14->PSC = 7;
	HAL_TIM_Base_Start_IT(&htim14);

	//ADC Calibration for internal NTC Temp
	INTC_CAL1 = *(int16_t*)0x1FFFF7B8;
	INTC_CAL2 = *(int16_t*)0x1FFFF7C2;
	//When I used int16_t instead of float for CalibINTC, flash size usage shrink 2KB!
	//https://www.st.com/resource/en/application_note/cd00211314-how-to-get-the-best-adc-accuracy-in-stm32-microcontrollers-stmicroelectronics.pdf
	CalibINTC = ((110.0 - 30.0) / (INTC_CAL2 - INTC_CAL1)) * 1024;

	//Toggle the LEDs to initial state
	setLedColor(Black, LED_CONS);
	setLedColor(Red, LED_CONS);
	controlLEDbyParam(GPIO_PIN_RESET);
	HAL_Delay(500);
	setLedColor(Blue, LED_CONS);
	controlLEDbyParam(GPIO_PIN_RESET);
	HAL_Delay(500);
	setLedColor(Green, LED_CONS);
	controlLEDbyParam(GPIO_PIN_RESET);
	HAL_Delay(500);

	//Init the flag variables
	outputReferences.settedREFVoltage = outputReferences.nonParallelREFVoltage = getParamDataViaPN(OUTPUT_VOLTAGE);
	boostPinState = HAL_GPIO_ReadPin(BOOST_INP_GPIO_Port, BOOST_INP_Pin);
    *getParamDataAdr(PARALLEL_CURRENT_COEFF) = getParamDefViaPN(PARALLEL_CURRENT_COEFF);//parallelCurrentCoefficient = 3;
    setParamDataViaPN(ERR_FLAG, 0, CALLBACK_OFF);
    setParamDataViaPN(WARN_FLAG, 0, CALLBACK_OFF);
  /* USER CODE END 2 */

  /* Infinite loop */
  /* USER CODE BEGIN WHILE */
    //Algorithm starts

    //Check device type and set for analog
    //if(MAX_VOLTAGE <= 1600)HAL_GPIO_WritePin(OVER_VOLT_GPIO_Port, OVER_VOLT_Pin, GPIO_PIN_SET);
    setParamDataViaPN(OUTPUT_MODEL, 0000, CALLBACK_ON);

    //check for open connections on ADC
    if(isADCOpen(MEASURED) == STAT_TRUE){
    	errorHandler(ADCOpen);
    }else{
    	errorHandler(ADCOpen_false);
    }

    //Open the output MOSFET
	setParamDataViaPN(OUTPUT_CUT_OFF, CONDUCTING, CALLBACK_ON);
uint64_t mbPrevTick = 0;
	while (1)
	{
		//if this loop becomes faster than 1ms, tick related things will be stuck because it can't be incremented before new loop starts
    /* USER CODE END WHILE */

    /* USER CODE BEGIN 3 */
	  //* Reload IWDG to not cause reset of the MCU
    #ifndef DEBUG_MODE_OPTIONS
	  __HAL_IWDG_RELOAD_COUNTER(&hiwdg);
    #endif

	//update monitor parameters on modbus
		*getParamDataAdr(MONITORING_VOLTAGE) = MEASURED.Vout;
		*getParamDataAdr(MONITORING_CURRENT) = MEASURED.Iout;
	//I thought updating *getParamDataAdr(OUTPUT_VOLTAGE AND CURRENT) in here, would update the scada values.
	//But this will also effect voltage update callback

		// Moved this line to CPT100 calculation for SCADA
		// *getParamDataAdr(MONITORING_PT100)   = MEASURED.RPT100;

		*getParamDataAdr(MONITORING_NTC)     = MEASURED.ntcC;
		*getParamDataAdr(MONITORING_VBAT)    = MEASURED.Vbat;
		*getParamDataAdr(MONITORING_INTC) 	 = MEASURED.INTC;

		//To monitor actual pwm values over SCADA
		if(getParamDataViaPN(PWMFLAG) == 0){
			*getParamDataAdr(VOUTPWM) =  outputReferences.dbgVPWM = Voltage_PWM;
			*getParamDataAdr(IOUTPWM) =  outputReferences.dbgIPWM = Current_PWM;
		}

		//To monitor algorithm states over SCADA
		setParamDataViaPN(DEBUG_MODE, getParamDataViaPN(OUTPUT_CHARGE_MODE), CALLBACK_OFF);

    	//modbus function to respond calls from usb
		if(tick != mbPrevTick){
			mbPrevTick = tick;
			modbusServerSerialRun(&MbServerUsbObj);
		}

		//Control the LEDs
		if(getParamDataViaPN(LED_CONSTANT) == 0){
			if(HAL_GetTick() > ledOffset ){
				ledOffset = HAL_GetTick() + getParamDataViaPN(LED_FLASH_TIME);
				if(ledOffset < HAL_GetTick() ){
					ledOffset = getParamDataViaPN(LED_FLASH_TIME);
				}
				ledToggleCount = 0;
				controlLEDbyParam(GPIO_PIN_SET);
			}else{
				if(HAL_GetTick() > ledOffset_2){
					ledOffset_2 = HAL_GetTick() + 128;
					if(ledOffset_2 < HAL_GetTick()) ledOffset_2 = 128;
					if(ledToggleCount < getParamDataViaPN(LED_BLINK) * 2){
						ledToggleCount++;
						controlLEDbyParam(3);
					}else{
						controlLEDbyParam(GPIO_PIN_SET);
				  }
				}
			}
		}else{
			controlLEDbyParam(GPIO_PIN_RESET);
		}

	    //check for reverse polarity
	    if(isOutputReverse(MEASURED) == STAT_TRUE){
			errorHandler(outputReverse);
		}else{
			errorHandler(outputReverse_false);
		}

	    //Temperature controls
		if(tempTick != tick && tick % 65535 == 0){
			tempTick = tick;

			if(getParamDataViaPN(DEBUG_DERATE) == 1) powerDerator(MEASURED);

			//check for mode
			if(mode != S_CHARGER) continue;

			//check for pt100 status if it is activated and connected
			if(isPT100Connected(MEASURED) != STAT_TRUE){
				//! alt satır neden var?!?!?!
				//PT100 Charging() set edilen voltajı değiştiriyor
				//setParamDataViaPN(OUTPUT_VOLTAGE, outputReferences.settedREFVoltage, CALLBACK_ON);
				if(getParamDataViaPN(TEMP_PT100_ACT) != 1) continue;
				errorHandler(PT100Connection);
				continue;
			}
			//Activate PT100
			setParamDataViaPN(TEMP_PT100_ACT, 1, CALLBACK_OFF);
			errorHandler(PT100Connection_false);

			//Calculate Temp for PT100
			int16_t CPT100 = MEASURED.RPT100 * 0.0258 - 258;
			*getParamDataAdr(MONITORING_PT100)   = CPT100;

			//if dvdc set
			//modify reference voltage accordingly
			//If battery temp drops below 25C then output should be increased
			//but if it gets hotter we should drop the output voltage
			//so CPT100 - 25 produces negative coef if batt is cold and gets multiplied with DVDT and multiplied with "-"
			//setParamDataViaPN(OUTPUT_VOLTAGE, outputReferences.settedREFVoltage + (getParamDataViaPN(TEMP_PT100_DVDT) * (CPT100 - 25)), CALLBACK_OFF);
			PT100Comp = getParamDataViaPN(TEMP_PT100_DVDT) * (CPT100 - 25);
			pt100Flag = 1;


			//Check for power derate
			if(CPT100 < getParamDataViaPN(TEMP_DERATE_PT100)){
				errorHandler(overTempPT100_false);
				continue;
			}

			//Warning
			errorHandler(overTempPT100);

			//if there is error
			if(CPT100 > getParamDataViaPN(TEMP_PT100_MAX)){
				errorHandler(overTempPT100);
			}
		}

		//Check for over voltage situation
		if(isOverVoltage(MEASURED) == STAT_TRUE){
			errorHandler(overVoltageError);
		}else{
			errorHandler(overVoltageError_false);
		}

//		//over current can happen on current limit so no blocking
//		if(isOverCurrent(MEASURED) == STAT_TRUE){
//			setParamDataViaPN(LED_CONSTANT, 0, CALLBACK_OFF);
//			errorHandler(overCurrentWarn);
//		}
//		errorHandler(overCurrentWarn_false);

		//output control mode
		if(getParamDataViaPN(OUTPUT_MODE_PSU) == 1){
			mode = S_PSU;
		}else{
			mode=S_CHARGER;
		}
		switch(mode){
		//These are the device modes that  determines if device is battery charging or power supply
		case S_PSU:{
		//power supply mode 
		//in this mode, Vout and Iout is directly controlled by params
			if(getParamDataViaPN(OUTPUT_VOLTAGE) >= 1800){
				setLedColor(Cyan, LED_CONS);
			}else if(getParamDataViaPN(OUTPUT_VOLTAGE) <= 1600){
				setLedColor(Green, LED_CONS);
			}else{
				setLedColor(Purple, LED_CONS);
			}
			if(getRelayState() != RELAY_CONDUCTING) setRelayOutput(RELAY_CONDUCTING);
			break;
}
		case S_CHARGER:{
		//charger mode with stated output voltages.
		//it does auto boost, auto detect, ...
			*getParamDataAdr(OUTPUT_CURRENT) = outputReferences.REFCurrent;
			if(getRelayState() != RELAY_CONDUCTING) setRelayOutput(RELAY_CONDUCTING);
			
			if(getParamDataViaPN(OUTPUT_MODE_AUTO) == 1){
				//Check for connected battery voltage
				//if it is out of range, we can't auto detect
				if(MEASURED.Vout >= 1800){
					setParamDataViaPN(OUTPUT_VOLTAGE, 2760, CALLBACK_ON);
					setParamDataViaPN(OUTPUT_BOOST_VOLTAGE, 2800, CALLBACK_ON);
					setParamDataViaPN(OUTPUT_MODE_AUTO, 0, CALLBACK_OFF);
					if(MEASURED.Vout >= 1800){
						errorHandler(wrongBattWarn_false);
						continue;
					}
				}else if(MEASURED.Vout <= 1600){
					setParamDataViaPN(OUTPUT_VOLTAGE, 1380, CALLBACK_ON);
					setParamDataViaPN(OUTPUT_BOOST_VOLTAGE, 1450, CALLBACK_ON);
					setParamDataViaPN(OUTPUT_MODE_AUTO, 0, CALLBACK_OFF);
					if(MEASURED.Vout <= 1600){
						errorHandler(wrongBattWarn_false);
						continue;
					}
				}
				//If auto mode can't detect batt type
				setParamDataViaPN(OUTPUT_VOLTAGE, 1200, CALLBACK_ON);
				setParamDataViaPN(OUTPUT_BOOST_VOLTAGE, 1450, CALLBACK_ON);
				setParamDataViaPN(OUTPUT_MODE_AUTO, 0, CALLBACK_OFF);
				errorHandler(wrongBattWarn);
			}else if(getParamDataViaPN(OUTPUT_MODE_AUTO) == 0){

				//Check for parameter voltage, it should be deterministic
				if(*getParamDataAdr(OUTPUT_VOLTAGE) >= 1800){
					setLedColor(Cyan, LED_CONS);
					if(MEASURED.Vout >= 1800){
						errorHandler(wrongBattWarn_false);
						continue;
					}
				}else if(*getParamDataAdr(OUTPUT_VOLTAGE) <= 1600 && *getParamDataAdr(OUTPUT_VOLTAGE) >= 1201){
					setLedColor(Green, LED_CONS);
					if(MEASURED.Vout <= 1600){
						errorHandler(wrongBattWarn_false);
						continue;
					}
				}else{
					setLedColor(Purple, LED_NCONS);
					errorHandler(wrongBattWarn);
				}
			}
			break;
		}
		default:{
		//there must be memory error or debug going on
			setLedColor(Yellow, LED_CONS);
			//setParamDataViaPN(LED_CONSTANT, 0, CALLBACK_OFF);
			setParamDataViaPN(LED_BLINK, 2, CALLBACK_OFF);
			setParamDataViaPN(LED_FLASH_TIME, 1024, CALLBACK_OFF);
			break;
		}
		}
		//This function should be called every minutes or so
		//It does timing and measuring battery
		if(tick % 65535 == 0){
			if(mode == S_CHARGER) Charging(MEASURED, boostLock, PT100Comp);
		}
  }
  /* USER CODE END 3 */
}

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
/* USER CODE BEGIN 4 */

/**
 * @brief function to call periodically inside hal tick it computes and calculates periodic jobs 
 * 
 */
void sysTickCallback(void){

  //Time base for whole main function
	tick++;

	if(tick % 128 == 0){ //If changed OVER_VOLTAGE_COUNT should be updated to

		//Calculate the readed values in human readable form
		MEASURED.ntcC   = getParamDataViaPN(MEASURE_CALIB_NTC)   * (150 - (ADC_Buffer[0] >> 5)) >> 10;
		MEASURED.RPT100 = getParamDataViaPN(MEASURE_CALIB_PT100) * ((ADC_Buffer[1] * 819 >> 8)  + 7487) >> 10;//* 3.2 + 7487);
		MEASURED.Vbat   = getParamDataViaPN(MEASURE_CALIB_VBAT)  * (ADC_Buffer[2] * 500  >> 8 ) >> 10;
		MEASURED.Vout   = getParamDataViaPN(MEASURE_CALIB_VOUT)  * (ADC_Buffer[3] * 1815 >> 11) >> 10;
		MEASURED.Iout   = getParamDataViaPN(MEASURE_CALIB_IOUT)  * (ADC_Buffer[4] * MEASURE_CURRENT_MUL >> MEASURE_CURRENT_SH) >> 10;
		MEASURED.INTC   = ((CalibINTC * (ADC_Buffer[5] - INTC_CAL1)) / 1024) + 30;

		if(getParamDataViaPN(PARALLEL_WORKING) == 1){
			*getParamDataAdr(OUTPUT_VOLTAGE) = outputReferences.nonParallelREFVoltage - ( MEASURED.Iout / 128 * getParamDataViaPN(PARALLEL_CURRENT_COEFF) );//parallelWorking(MEASURED);
		}//else nonparallelvoltage = output_voltage

		//if(pt100Flag == 1 && getParamDataViaPN(TEMP_PT100_ACT) == 0) output_voltage = outputReferences.setted;

		if(getParamDataViaPN(PWMFLAG) == 0) outputController(MEASURED);

	}
}

/**
 * @brief callback for gpio perip. It's been used for Boost input pin
 * 
 * @param GPIO_Pin 
 */
void HAL_GPIO_EXTI_Callback(uint16_t GPIO_Pin){

	if(GPIO_Pin == BOOST_INP_Pin){

	}
}

/**
 * @brief Callback function for DMA peripheral. It sums up all DMA values to be divided in the systickcallback.
 * Data comes from here can't be used without division.
 * 
 * @param hadc handle for adc peripheral
 */
void HAL_ADC_ConvCpltCallback(ADC_HandleTypeDef *hadc) {
  static uint64_t dma_prev_tick;
	if(tick % 8 == 0 && tick != dma_prev_tick){
		dma_prev_tick = tick;
		ADC_Buffer[0] = (DMA_Buffer[DMA_IND_0] + ADC_Buffer[0]) / 2;
		ADC_Buffer[1] = (DMA_Buffer[DMA_IND_1] + ADC_Buffer[1]) / 2;
		ADC_Buffer[2] = (DMA_Buffer[DMA_IND_2] + ADC_Buffer[2]) / 2;
		ADC_Buffer[3] = (DMA_Buffer[DMA_IND_3] + ADC_Buffer[3]) / 2;
		ADC_Buffer[4] = (DMA_Buffer[DMA_IND_4] + ADC_Buffer[4]) / 2;
		ADC_Buffer[5] = (DMA_Buffer[DMA_IND_5] + ADC_Buffer[5]) / 2;
  }
}

/**
 * @brief checks for data values on param list against modbus min max values
 */
void Default_isoutputReferencesDefault(){
	for(uint16_t i = 1; i < PARAM_LAST_INDEX; i++){
		if(data[i - 1] < getParamMinViaPN(i) || data[i - 1] > getParamMaxViaPN(i)) data[i - 1] = getParamDefViaPN(i);
	}
}
int16_t wtf[TAG_SIZE];
/**
 * @brief  this func reads control reference values from flash
 * @return HAL_StatusTypeDef
 */
HAL_StatusTypeDef Flash_readReferencesFromFlash(void){

	  //if it is initial loading of the program
	  if(FLASH_POINTER_1 == 0xFFFFFFFF){
	  //Load Default Vector Table
	  Flash_writeWordtoAddr((uint32_t)(&FLASH_POINTER_16 + 4), (uint32_t)&FLASH_POINTER_1);
	  Flash_writeWordtoAddr((uint32_t)(0x0800FFC0), 		   (uint32_t)&FLASH_POINTER_2);
	  Flash_writeWordtoAddr((uint32_t)(&FLASH_POINTER_16 + 4), (uint32_t)&FLASH_POINTER_3);
	  Flash_writeWordtoAddr((uint32_t)(&FLASH_POINTER_16 + 4), (uint32_t)&FLASH_POINTER_4);
	}
	  HAL_StatusTypeDef stat;

	  //read the list
	  stat = Flash_readDataChunkFromAddr(data, FLASH_POINTER_1 , (sizeof data));
	  if(stat != HAL_OK) return stat;

	  stat = Flash_readDataChunkFromAddr(wtf, FLASH_POINTER_2 , (sizeof wtf));
	  if(stat != HAL_OK) return stat;

	  //compare for defaults
	  Default_isoutputReferencesDefault();

	  //load to struct that is used inside code
	  outputReferences.REFCurrent = getParamDataViaPN(OUTPUT_CURRENT);
	  outputReferences.dbgVPWM = getParamDataViaPN(VOUTPWM);
	  outputReferences.dbgIPWM = getParamDataViaPN(IOUTPWM);
	  outputReferences.boostVoltage = getParamDataViaPN(OUTPUT_BOOST_VOLTAGE);
//	  outputReferences.nonParallelREFVoltage = getParamDataViaPN(OUTPUT_VOLTAGE);
	  return HAL_OK;
}

/**
 * @brief erases the control page and writes controller reference values to flash
 *
 * @return HAL_StatusTypeDef
 */
HAL_StatusTypeDef Flash_writeReferencesToFlash(void){

	//Hiç bir zaman readden önce write yapılmaması ön koşuluyla şu yapılabilir
	//read işlemi en baştaki 20 adresin içinde yer alan adreslerden ram'a verileri alacak
	//işlemesi gereken her şeyi işleyecek ve datanın son hali her zaman ramda olacak
	//write yapılması gerektiğinde flash baştan ram'a göre doldurulacak ve en baştaki adresler buna göre güncellenecek

	HAL_StatusTypeDef stat;
	uint32_t* tmpPointer = 0;

	stat = Flash_readWordChunkFromAddr(tmpPointer, 0x0800F800, 16);
	if(stat != HAL_OK) return stat;

	stat = Flash_ErasePageWithNumber(31);
	if(stat != HAL_OK) return stat;

	stat = Flash_writeWordChunktoAddr(tmpPointer, 0x0800F800, 16);
	if(stat != HAL_OK) return stat;


	stat = Flash_writeWordChunktoAddr((uint32_t*)data, FLASH_POINTER_1, (sizeof data) / 2);
	if(stat != HAL_OK) return stat;

	stat = Flash_writeWordChunktoAddr((uint32_t*)wtf, FLASH_POINTER_2, (sizeof wtf) / 2);
	if(stat != HAL_OK) return stat;

	return HAL_OK;
}
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

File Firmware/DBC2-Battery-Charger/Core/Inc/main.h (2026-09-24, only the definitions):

#define USER_PROG_TAG_ADR  0x800FFC0
#define TAG_SIZE 64
#define V_NTC_ADC_Pin GPIO_PIN_0
#define V_NTC_ADC_GPIO_Port GPIOA
#define PT100_ADC_Pin GPIO_PIN_1
#define PT100_ADC_GPIO_Port GPIOA
#define RELAY_OP_Pin GPIO_PIN_2
#define RELAY_OP_GPIO_Port GPIOA
#define VBAT_ADC_Pin GPIO_PIN_3
#define VBAT_ADC_GPIO_Port GPIOA
#define VOUT__ADC_Pin GPIO_PIN_4
#define VOUT__ADC_GPIO_Port GPIOA
#define BOOST_INP_Pin GPIO_PIN_5
#define BOOST_INP_GPIO_Port GPIOA
#define BOOST_INP_EXTI_IRQn EXTI4_15_IRQn
#define CUT_OFF_OUTPUT_Pin GPIO_PIN_6
#define CUT_OFF_OUTPUT_GPIO_Port GPIOA
#define I_OUT_ADC_Pin GPIO_PIN_7
#define I_OUT_ADC_GPIO_Port GPIOA
#define I_PWM_Pin GPIO_PIN_0
#define I_PWM_GPIO_Port GPIOB
#define V_PWM_Pin GPIO_PIN_1
#define V_PWM_GPIO_Port GPIOB
#define TP4_Pin GPIO_PIN_15
#define TP4_GPIO_Port GPIOB
#define TP4_EXTI_IRQn EXTI4_15_IRQn
#define OVER_VOLT_Pin GPIO_PIN_15
#define OVER_VOLT_GPIO_Port GPIOA
#define JTDO_Pin GPIO_PIN_3
#define JTDO_GPIO_Port GPIOB
#define LED_G_Pin GPIO_PIN_4
#define LED_G_GPIO_Port GPIOB
#define LED_B_Pin GPIO_PIN_5
#define LED_B_GPIO_Port GPIOB
#define LED_R_Pin GPIO_PIN_6
#define LED_R_GPIO_Port GPIOB
#define V_NTC_ADC_Pin GPIO_PIN_0
#define V_NTC_ADC_GPIO_Port GPIOA
#define PT100_ADC_Pin GPIO_PIN_1
#define PT100_ADC_GPIO_Port GPIOA
#define RELAY_OP_Pin GPIO_PIN_2
#define RELAY_OP_GPIO_Port GPIOA
#define VBAT_ADC_Pin GPIO_PIN_3
#define VBAT_ADC_GPIO_Port GPIOA
#define VOUT__ADC_Pin GPIO_PIN_4
#define VOUT__ADC_GPIO_Port GPIOA
#define BOOST_INP_Pin GPIO_PIN_5
#define BOOST_INP_GPIO_Port GPIOA
#define BOOST_INP_EXTI_IRQn EXTI4_15_IRQn
#define CUT_OFF_OUTPUT_Pin GPIO_PIN_6
#define CUT_OFF_OUTPUT_GPIO_Port GPIOA
#define I_OUT_ADC_Pin GPIO_PIN_7
#define I_OUT_ADC_GPIO_Port GPIOA
#define I_PWM_Pin GPIO_PIN_0
#define I_PWM_GPIO_Port GPIOB
#define V_PWM_Pin GPIO_PIN_1
#define V_PWM_GPIO_Port GPIOB
#define TP4_Pin GPIO_PIN_15
#define TP4_GPIO_Port GPIOB
#define TP4_EXTI_IRQn EXTI4_15_IRQn
#define OVER_VOLT_Pin GPIO_PIN_15
#define OVER_VOLT_GPIO_Port GPIOA
#define JTDO_Pin GPIO_PIN_3
#define JTDO_GPIO_Port GPIOB
#define LED_G_Pin GPIO_PIN_4
#define LED_G_GPIO_Port GPIOB
#define LED_B_Pin GPIO_PIN_5
#define LED_B_GPIO_Port GPIOB
#define LED_R_Pin GPIO_PIN_6
#define LED_R_GPIO_Port GPIOB
#define V_NTC_ADC_Pin GPIO_PIN_0
#define V_NTC_ADC_GPIO_Port GPIOA
#define PT100_ADC_Pin GPIO_PIN_1
#define PT100_ADC_GPIO_Port GPIOA
#define RELAY_OP_Pin GPIO_PIN_2
#define RELAY_OP_GPIO_Port GPIOA
#define VBAT_ADC_Pin GPIO_PIN_3
#define VBAT_ADC_GPIO_Port GPIOA
#define VOUT__ADC_Pin GPIO_PIN_4
#define VOUT__ADC_GPIO_Port GPIOA
#define BOOST_INP_Pin GPIO_PIN_5
#define BOOST_INP_GPIO_Port GPIOA
#define BOOST_INP_EXTI_IRQn EXTI4_15_IRQn
#define CUT_OFF_OUTPUT_Pin GPIO_PIN_6
#define CUT_OFF_OUTPUT_GPIO_Port GPIOA
#define I_OUT_ADC_Pin GPIO_PIN_7
#define I_OUT_ADC_GPIO_Port GPIOA
#define V_PWM_Pin GPIO_PIN_0
#define V_PWM_GPIO_Port GPIOB
#define I_PWM_Pin GPIO_PIN_1
#define I_PWM_GPIO_Port GPIOB
#define TP4_Pin GPIO_PIN_15
#define TP4_GPIO_Port GPIOB
#define OVER_VOLT_Pin GPIO_PIN_15
#define OVER_VOLT_GPIO_Port GPIOA
#define JTDO_Pin GPIO_PIN_3
#define JTDO_GPIO_Port GPIOB
#define LED_G_Pin GPIO_PIN_4
#define LED_G_GPIO_Port GPIOB
#define LED_B_Pin GPIO_PIN_5
#define LED_B_GPIO_Port GPIOB
#define LED_R_Pin GPIO_PIN_6
#define LED_R_GPIO_Port GPIOB
#define PT100_ADC_Pin GPIO_PIN_1
#define PT100_ADC_GPIO_Port GPIOA
#define CUT_OFF_OUTPUT_Pin GPIO_PIN_2
#define CUT_OFF_OUTPUT_GPIO_Port GPIOA
#define V_PWM_Pin GPIO_PIN_3
#define V_PWM_GPIO_Port GPIOA
#define VOUT__ADC_Pin GPIO_PIN_5
#define VOUT__ADC_GPIO_Port GPIOA
#define VBAT_ADC_Pin GPIO_PIN_6
#define VBAT_ADC_GPIO_Port GPIOA
#define RELAY_OP_Pin GPIO_PIN_7
#define RELAY_OP_GPIO_Port GPIOA
#define I_OUT_ADC_Pin GPIO_PIN_0
#define I_OUT_ADC_GPIO_Port GPIOB
#define V_NTC_ADC_Pin GPIO_PIN_1
#define V_NTC_ADC_GPIO_Port GPIOB
#define I_PWM_Pin GPIO_PIN_10
#define I_PWM_GPIO_Port GPIOB
#define BOOST_INP_Pin GPIO_PIN_12
#define BOOST_INP_GPIO_Port GPIOB
#define BOOST_INP_EXTI_IRQn EXTI4_15_IRQn
#define PWM_CAN_Pin GPIO_PIN_15
#define PWM_CAN_GPIO_Port GPIOB
#define LED_B_Pin GPIO_PIN_15
#define LED_B_GPIO_Port GPIOA
#define JTDO_Pin GPIO_PIN_3
#define JTDO_GPIO_Port GPIOB
#define LED_R_Pin GPIO_PIN_4
#define LED_R_GPIO_Port GPIOB
#define LED_G_Pin GPIO_PIN_7
#define LED_G_GPIO_Port GPIOB

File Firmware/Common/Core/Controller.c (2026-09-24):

/*
 * Controller.c
 *
 *  Created on: 6 Eki 2022
 *      Author: ceyhun.uysal
 */

 /*-------------------------------------- Includes --------------------------------------*/

#include "Controller.h"

/*-------------------------------------- Private Definitions --------------------------------------*/

extern modbusServerObject_t server;

extern controller_t controller;

// Relay state global variable
RELAY_STATE relayState = RELAY_NOT;

// Timer variables for boost mode
uint32_t t1 = 0, t2 = 0, boostCounter = 0;

// Objects to hold ADC related data and filter accumulator
measurement_t Vout, Iout, Intc, Ontc, Tpt, Vbat;

/*--------------------------------------Function Implementations --------------------------------------*/

void _checkTemperature(MEASURED_t *_measured){

  // If PT100 is not connected
  if(Tpt.flagOpen == ENABLED){

    // But PT100 is activated, we should raise a flag
    if(controller.flagPt100 == ENABLED){
      controller.flagWARN = controller.flagWARN | 0x04; // 3rd Warning bit is PT100Connection
    }else{
      // If it is not activated just ignore it
      controller.flagWARN = controller.flagWARN & ~(0x04); // 3rd Warning bit is PT100Connection
    }

  }else{

    //Activate PT100 in case it is connected
    //controller.flagPt100 = ENABLED;
    controller.flagWARN = controller.flagWARN & ~(0x04); // 3rd Warning bit is PT100Connection

    //if dvdc set
    //modify reference voltage accordingly
    //If battery temp drops below 25C then output should be increased
    //but if it gets hotter we should drop the output voltage
    //so CPT100 - 25 produces negative coef if batt is cold and gets multiplied with DVDT and multiplied with "-"
    //controller.referenceVoltage, outputReferences.settedREFVoltage + (controller.Pt100DVDT * (CPT100 - 25)), CALLBACK_OFF);
    _measured->PT100Comp = -1 * (controller.Pt100DVDT * ( ((_measured->CPT100 - 250) * 51) >> 9));
  }
}

/**
 * @brief return relayState global function for the updateRelay func.
 */
RELAY_STATE getRelayState(void){
  return relayState;
}

/**
 * @brief set relayState global function for the updateRelay func.
 */
void setRelayState(RELAY_STATE r){
  relayState = r;
}

/**
 * @brief Periodic update function for relay state.
 * It checks for current status and updates relay accordingly.
 */
void updateRelay(void){

  controller.flagRelay = RELAY_VALUE;

  switch(relayState){
  case RELAY_CONDUCTING:
    RELAY_ON;
    break;
  case RELAY_NOT:
    RELAY_OFF;
    break;
  case RELAY_WAITING:
    break;
  case RELAY_ERROR:
    RELAY_OFF;
  default:
    break;
  }
}

/**
 * @brief checks for ADC pin possible values returns STAT_TRUE if it is abnormal"
 * 
 * @param _measured 
 * @return AlgorithmStatus 
 */
AlgorithmStatus isADCOpen(const MEASURED_t _measured){
	if(_measured.Vout == 0) return STAT_TRUE;
	if(_measured.CPT100 <= -400 || _measured.CPT100 >= 1500) return STAT_TRUE;
	if(_measured.ntcC == 150) return STAT_TRUE;
	//if(_measured.Iout == 0) return STAT_TRUE;
	//if(_measured.Vbat == 0) return STAT_TRUE;
	//if(_measured.INTC == 0) return STAT_TRUE;
	return STAT_FALSE;
}

/**
 * @brief checks for ADC pin possible values returns STAT_TRUE if it is abnormal"
 *
 * @param _measured
 * @return AlgorithmStatus
 */
AlgorithmStatus isPT100Broken(const MEASURED_t _measured){
	if(_measured.CPT100 <= -400 || _measured.CPT100 >= 1500) return STAT_TRUE;
	return STAT_FALSE;
}

void outputAutoDetect(MEASURED_t *_measured){

  //Check for connected battery voltage
  //if it is out of range, we can't auto detect
  if(_measured->Vout >= 1800){
    controller.chargeVoltage = 2760;
    controller.boostVoltage = 2800;
    if(_measured->Vout >= 1800){
      controller.flagWARN = controller.flagWARN & 0xDF; // 6th Warning bit is wrongBattWarn
    }
  }else if(_measured->Vout <= 1600){
    controller.chargeVoltage = 1380;
    controller.boostVoltage = 1450;
    if(_measured->Vout <= 1600){
      controller.flagWARN = controller.flagWARN & 0xDF; // 6th Warning bit is wrongBattWarn
    }
  }else{
    // If auto mode can't detect batt type
    controller.chargeVoltage = 1200;
    controller.boostVoltage = 1450;
    controller.flagWARN = controller.flagWARN | 0x20; // 6th Warning bit is wrongBattWarn

  }

  controller.flagModeAuto = 0;
  callBackChargerUpdateVoltageREF();
  CallbackUpdateVoltageBoost();
}

void Charging(MEASURED_t *_measured){

  // If External Boost Input is triggered, we should stay in the boost mode until it is removed
	if(controller.flagBoostTriggered == ENABLED){
	  controller.chargeState = BOOST;
	  boostCounter = 0;
    t1 = 0;
    t2 = 0;
	}

	switch (controller.chargeState){

	case BOOST:
		boostCounter++;
		t1++;

		controller.LEDColor = Blue;
    controller.LEDBlink = 2;

		//this multiplier comes from %95 constraint *0.95 ~= 243/256
		if((_measured->Iout <= ((controller.effectiveCurrent * 243 ) >> 8))
				|| (t1 >= controller.boostDuration)){
		  controller.chargeState = EQUALIZATION;
		}

		break;
	case EQUALIZATION:

		boostCounter++;
		t2++;

    controller.LEDColor = Blue;
    controller.LEDBlink = 2;

		if(t2 >= t1 / 2){
			if(t2 >= controller.equalizationTime){
			  controller.chargeState = FLOAT;
			}
		}

		break;
	case FLOAT:
		
	boostCounter++;

	if(boostCounter >= 2 * (t1 + t2)){
		if(boostCounter >= controller.autoStartBoostTime){

			if(controller.flagAutoBoost == ENABLED && controller.flagParallel == DISABLED){

			  controller.chargeState = BOOST;
				boostCounter = 0;
				t1 = 0;
				t2 = 0;
			}
		}
	}

	break;
	default:		

	  // there must be memory error or debug going on
	  controller.LEDColor = Yellow;
    controller.LEDBlink = 2;

		break;
	}
}
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

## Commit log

2026-09-24 Initial project import
    [101.CSV, 101output.csv, 102.CSV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]
2026-09-25 timer2 32bit problem is resolved
    [DBC2-90W.ioc, Interfaces.c, gpio.c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]
2026-09-25 Update ADC channel configuration and GPIO initialization for I_OUT_ADC
2026-09-25 Add NTC_ACTIVE pin configuration in GPIO setup and update IOC file
2026-10-01 Update current and power definitions in defaults.h for improved specifications

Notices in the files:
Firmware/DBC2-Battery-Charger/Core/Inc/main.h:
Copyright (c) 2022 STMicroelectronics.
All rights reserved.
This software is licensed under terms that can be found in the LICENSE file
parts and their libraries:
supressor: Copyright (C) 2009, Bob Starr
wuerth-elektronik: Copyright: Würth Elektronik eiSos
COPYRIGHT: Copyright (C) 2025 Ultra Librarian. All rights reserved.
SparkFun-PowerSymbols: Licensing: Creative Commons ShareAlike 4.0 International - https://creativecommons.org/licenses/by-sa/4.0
